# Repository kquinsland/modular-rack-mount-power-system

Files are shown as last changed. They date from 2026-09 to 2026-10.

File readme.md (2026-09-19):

# Modular Rack Power

This is a "side-quest" project on the way to building a small "mini rack" dedicated to hosting GH/A runners.

I'll do the CAD and standalone development here before integrating it into the larger project.
The goal is to have a modular system of a backplane and multiple carrier modules that can be swapped in and out to provide different power configurations as needed.
As long as the power supply can handle it, backplanes may share/daisy-chain the
input distribution needed by their carrier modules.

Hardware, firmware, and host tooling for a modular mini-rack power system.

## Boards

- `backplane`: STM32C092/CAN-FD backplane with six carrier slots, power
  distribution, aggregate current monitoring, fan control, and a status
  NeoPixel.
- `carrier`: Mates with one backplane slot and hosts an SW3538 USB-C PD module.

Every backplane and carrier is an independent STM32C092 CAN-FD node. There is no
I2C mux and no controller/proxy relationship between nodes. Earlier hardware and
firmware were research prototypes and are not compatibility targets.

## Layout

```text
firmware/
  Cargo.toml
  backplane/
  carrier/
  bootloader/
  crates/
  tools/
  xtask/
  docs/pdcan/
hardware/
  boards/
    backplane/
    carrier/
  libraries/
    symbols/
    footprints/
    3dmodels/
  mechanical/
docs/
scripts/
build/
releases/
```

`build/` is for generated local outputs. `releases/` is for fabrication packages that should be preserved exactly as sent to a board house.

See [`firmware/README.md`](firmware/README.md) for workspace commands and the
current hardware/firmware contract. Run `mise run firmware:check` from this
directory, or run Cargo commands from `firmware/`. The reviewed implementation
plan is kept in [`firmware/plan.md`](firmware/plan.md).

## Documentation site

The public-facing project documentation is maintained in [`site/`](site/) and
is intended for <https://mrps.karlquinsland.com/>. Run `mise run site:serve` for
local preview or `mise run site:build` for a production build. Create journal
entries with `mise run worklog:new -- "Concise Summary"` to create
`site/content/worklogs/YYYY/MM/DD - Concise Summary/index.md` with matching
front matter and an adjacent `_files/` directory for page resources.

## Misc

I can't believe that it's STILL such a pain in the ass to use LCSC to search for parts that are stocked by the SMT service.
https://yaqwsx.github.io/jlcparts/#/

Also super useful reference: https://www.tinkervault.com/usb-power-sources/dc-pd30-adapters
It's how I 'caught' that the `sw3538` based module I am using is non-standard 140W, later confirmed:

- https://en.eeworld.com.cn/Reference_Designs/detail/81702
- https://github.com/happyme531/h1_SW35xx/issues/13#issuecomment-4361605621

https://github.com/Shrike-Lab/HomeLab-PDU-V1/blob/main/ASSEMBLY/README.md#pcb-tray

Plan was to use APK43070 but they do not support MCU controlling it via i2c

https://meron33.hatenablog.com/entry/2026/02/07/112759

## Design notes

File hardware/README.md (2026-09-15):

# Hardware

Source hardware lives here.

- `boards/`: One KiCad project per physical PCB.
- `libraries/`: Project-local KiCad symbols, footprints, and 3D models shared by all boards.
- `mechanical/`: Enclosure, panel, mounting, and exported mechanical references.

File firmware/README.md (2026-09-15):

# Firmware

This Cargo workspace targets the finalized Generation-2 hardware. Every backplane
and carrier is an independent STM32C092GCU6 CAN-FD node. I2C is board-local; the
host addresses nodes directly for control, telemetry, commissioning, and
application firmware updates.

## Workspace

- `backplane/`: backplane hardware contract and Embassy application target.
- `carrier/`: current SW3538 carrier contract and Embassy application target.
- `bootloader/`: common Embassy Boot swap/rollback bootloader.
- `crates/pdcan-types/`: shared role, capability, policy, telemetry, and update types.
- `crates/pdcan-protocol/`: strict CAN-FD codecs and message catalog.
- `crates/pdcan-core/`: transport-independent safety, commissioning, and update state machines.
- `crates/pdcan-drivers/`: INA237, DS18B20, and SW3538 drivers plus flash records.
- `crates/pdcan-artifact/`: versioned, signed-ready application update bundles.
- `tools/pdcan/`: Clap-based SocketCAN host utility with `clap_schema` discovery.
- `tools/pdcan-sim/`: deterministic Generation-2 backplane/carrier simulator.
- `xtask/`: CI, embedded builds, size gates, bundle construction, and DBC generation.

Firmware retains manual binary codecs; **Deku is not adopted**. See
[decision 0002](../docs/decisions/0002-do-not-use-deku-in-firmware.md) for the
rationale and supporting tests. The [benchmark report](docs/pdcan/deku-benchmark.md)
preserves the completed POWER and carrier-policy trial and reproduction commands.

## Commands

Run Cargo commands from this directory:

```sh
cargo xtask ci
cargo xtask firmware build backplane --release
cargo xtask firmware build carrier --release
cargo xtask firmware build bootloader --release
cargo xtask dbc --check
cargo run --package pdcan -- --help
cargo run --package pdcan -- schema --full
cargo run --package pdcan-sim -- --help
```

Build an unsigned application bundle after converting the linked application to
the raw ACTIVE-partition image expected by Embassy Boot:

```sh
cargo xtask firmware bundle carrier 1.0.0 carrier.bin carrier-1.0.0.pdcan
cargo run --package pdcan -- firmware inspect carrier-1.0.0.pdcan
```

Only Linux builds open SocketCAN interfaces. Host tests, artifact inspection,
Clap help, and schema discovery work on macOS. Embedded binaries use
`thumbv6m-none-eabi` and the `stm32c092gc` Embassy feature.

## Safety and update contract

Carrier outputs start disabled. A persisted enable is restored only after local
hardware checks and a deterministic UID-derived startup delay. Emergency and
fault handling always override policy. Backplane fans start at the safe 100%
duty state.

The host stages an image directly to the target node over CAN, verifies its
SHA-256 digest, and activates it separately. The current SW3538 profile advertises
`interrupt`, so `pdcan firmware activate` and the convenience `update` command
require `--allow-interruption`. A future profile may advertise `live` only after
its complete activation, trial-boot, failure, and rollback sequence has passed
profile-specific hardware-in-the-loop continuity testing.

The bootloader itself is SWD-only. Initial unsigned bundles provide transfer
integrity, not sender authentication; the artifact reserves Ed25519 algorithm,
key-ID, and signature fields for later enforcement.

See [plan.md](plan.md), [the firmware architecture](docs/pdcan/firmware-architecture.md),
and [the protocol specification](docs/pdcan/protocol.md).

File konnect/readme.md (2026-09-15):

# Konnect

This repository uses [Konnect](https://github.com/mixelpixx/Konnect), a Rust MCP
server, for AI-assisted KiCad work.

Mise downloads the precompiled upstream GitHub release. The version and release
artifact checksums are pinned in `mise.toml` and `mise.lock`:

```text
version: v0.11.0
```

Konnect is currently beta software and is licensed AGPL-3.0-only.
Review Konnect's `LICENSE` and
`COMMERCIAL.md` before using it in a commercial workflow.

## Architecture

Konnect runs as one Rust binary. It uses KiCad 10's supported IPC API
for live PCB edits and direct, atomic S-expression editing for schematics.

## Setup

Install KiCad 10, then from the repository root run:

```shell
mise install
mise run konnect:verify
```

No Konnect compiler toolchain is required. Mise selects the precompiled GitHub
release for the host OS and architecture, verifies its release provenance and
checksum, and puts `konnect` on the project tool path.

Konnect v0.11.0 does not publish a standalone Linux ARM64 binary. The mise entry
therefore supports this repository's Linux x86-64 and macOS ARM64 targets and
deliberately excludes the generic Linux Plugin and Content Manager ZIP from
standalone asset matching. Other project tools remain available on Linux ARM64;
only Konnect is skipped.

Restart Codex after the build so it reloads `.codex/config.toml`. Useful checks:

```shell
codex mcp list
codex mcp get konnect
```

The project MCP entry starts mise's `konnect` binary with the repository's
`konnect/config.toml`. It uses stdio transport, binds the default project
directory to the repository root, and initially exposes Konnect's small starter
toolset. Other toolsets are loaded on demand.

## KiCad runtime setup

In KiCad 10, enable **Preferences → Plugins → Enable KiCad API**. Most live PCB
operations require the target board to be open in PCB Editor. Schematic editing
and some closed-board operations do not require KiCad to be running.

On Linux, `kicad` and `kicad-cli` normally work from `PATH`. On macOS, add the
application paths to `konnect/config.toml` if they are not already discoverable:

```toml
kicad_cli = "/Applications/KiCad/KiCad.app/Contents/MacOS/kicad-cli"
kicad_binary = "/Applications/KiCad/KiCad.app/Contents/MacOS/kicad"
ipc_address = "ipc:///tmp/kicad/api.sock"
```

The KiCad Plugin and Content Manager package is optional for this repository's
standalone MCP server. Install the matching `konnect-pcm-v0.11.0-*` release if
you also want Konnect's KiCad GUI integration or native Specctra bridge.

## Optional Codex guidance

This repository includes the six v0.11.0 Konnect skills and their references
in `.codex/skills`. The `.agents/skills` symlink points there so Codex can
discover them using its repository skill search path.

Konnect bundles KiCad skills for Codex. Installing them writes outside this
repository to `~/.agents/skills`, so it is intentionally not part of the normal
build or verification tasks:

```shell
mise run konnect:install-guidance
konnect status --client codex
```

Remove those user-level files with:

```shell
konnect uninstall --client codex
```

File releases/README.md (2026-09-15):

# Releases

Preserved board fabrication outputs go here.

Use one folder per hardware release, for example `rev-a/backplane/` and `rev-a/carrier/`.

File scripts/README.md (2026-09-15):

# Scripts

Project automation goes here, such as KiCad CLI exports for schematics, BOMs, fabrication files, and 3D models.

## PCB power-capacity reports

`pcb_power_capacity.py` reads the filled copper geometry for a KiCad net and
estimates its current capacity at selected conductor temperature rises using
the IPC-2221 relationship published by KiCad. It reports every participating
copper layer's shared geometry, a natural current-sharing aggregate, an
ideal-sharing ceiling, voltage drop, copper loss, and a separate via-barrel
screening estimate. A scenario may compare multiple named copper stackups
without duplicating the geometry views. The generated SVG provides stackup
summary cards, color-coded limiting cuts, one conservative-temperature
capacity profile per stackup, and aggregate temperature-rise proxy heatmaps.
Each heatmap locally inverts the IPC-2221 capacity relationship; it is useful
for locating relative hot regions but is not a thermal-spreading or airflow
simulation.

The host needs Python 3.11 or newer, KiCad 10 with its `pcbnew` Python
bindings, and Shapely 2.x. The same dependencies are already used by the
repository's panel-generation workflow.

Generate both checked-in scenarios under `build/power-capacity/`:

```sh
mise run power:reports
```

Generate one named scenario or list the configured scenarios:

```sh
mise run power:report backplane-vcc
mise run power:report carrier-vcc
mise run power:report --list
```

Scenarios and their source/sink currents are defined in
`pcb_power_scenarios.toml`. The backplane scenario uses six 5.5 A slot loads;
it compares 2 oz outer / 1 oz inner copper with 1 oz outer / 0.5 oz inner
copper in one report. The carrier scenario follows `VCC` from `J1.1` to the
upstream side of the current shunt at `R1.1` and uses the board's KiCad
stackup. Reports show both micrometres and nominal PCB copper weight using
34.8 µm per oz/ft². Stackup comparisons use repeated `stackups` tables in the
scenario configuration. An ad-hoc invocation—or explicit `--copper` overrides
on a named scenario—generates a single custom-stackup report:

```sh
mise run power:report -- \
  --board hardware/boards/carrier/carrier.kicad_pcb \
  --net VCC \
  --source J1.1 \
  --sink R1.1=5.5 \
  --layer F.Cu \
  --layer In1.Cu \
  --layer In2.Cu \
  --layer B.Cu \
  --copper F.Cu=35 \
  --copper In1.Cu=17.5 \
  --copper In2.Cu=17.5 \
  --copper B.Cu=35
```

Omit `--layer` to use every enabled copper layer carrying the selected net.
Add one or more `--cut X1,Y1:X2,Y2` arguments to evaluate explicit board-space
cross-sections alongside the automatic sweep. A manual cut appears in the SVG
when it is limiting; every cut remains available in the complete JSON inventory.
The automatic sweep projects the source pad's actual polygon along the load
direction and places its first sample half a scan pitch beyond the pad edge, so
the source pad itself cannot be reported as a downstream copper bottleneck.

Each report directory contains:

- `report.md`: concise human-readable results and qualifications;
- `report.svg`: shared aggregate/per-layer geometry, stackup-specific limiting
  cuts and capacity profiles, and estimated temperature-rise proxy maps; and
- `report.json`: machine-readable inputs plus every stackup's scanned cuts,
  electrical estimates, limiting results, and peak temperature-rise proxy for
  future CI checks.

The all-scenarios task also writes `index.md` and `summary.json` at the report
root. The summary includes a board SHA-256 and an explicit pass/fail boolean
for each requested temperature rise, making it suitable for later CI policy
checks without scraping Markdown.

Run the formula and real-board integration tests with:

```sh
mise run power:test
```

This is a screening calculation, not a released board rating or a coupled
electro-thermal simulation. Review the SVG, heed extrapolation warnings, and
validate connectors, components, via topology, airflow, and first-article
temperatures separately.

## PCB production exports

Generate either board's checked-in BOM, component-placement file, Gerber/drill
archive, STEP assembly, IPC-D-356 netlist, designator inventory, assembly-count report, and validation manifest with:

```sh
mise run production:carrier
mise run production:backplane
```

The task runs ERC and DRC with schematic-parity checking before publishing any
files. It requires the selected board's design inputs to be committed, verifies
that the BOM and placement references agree exactly, checks the required
four-layer CAM file set, and stages everything before publishing the complete
file set in `hardware/boards/<board>/production/<silkscreen-id>/`, for example
`hardware/boards/backplane/production/mrp.backplane-v2.1-26-09-10-abcdef1/`.
The ZIP, CSVs, IPC netlist, reports, STEP and validation manifest all go inside
that release directory. Re-exporting the same release replaces only that
directory; other releases and any legacy files in the production root remain
intact. The manifest records `release_id`. DRC warnings are retained in
`validation.json`; ERC findings, DRC errors, unconnected items, parity errors,
missing sourcing fields, or BOM/CPL disagreement stop the export and leave the
previous production directory intact.

`assembly-report.md` lists the four PCBWay quote fields per single board:
unique parts (distinct LCSC codes), SMD components, BGA/QFP-category components,
and through-hole components. It follows PCBWay's tooltip definitions: the fields
count parts, despite the site's “SMT Pads” image labels. BGA/QFP includes ICs with
more than 16 pins (including QFN/SOP) and other SMD parts with more than 10 pins;
it is a subset of SMD. Only exported BOM/CPL references count, so hand-installed
connectors/modules excluded from those files do not enter the assembly quote.
The report includes a separate SMT contact count for reference. Repeated numbered
exposed-pad segments count once. Details are also stored under
`assembly.pcbway_quote` in `validation.json`. KiCad's Python bindings (`pcbnew`)
must be available to the task's Python interpreter. This report is published
alongside the fabrication ZIP and is covered by the validation manifest hash.

STEP assemblies are published alongside the ZIP as
`mrp.<board>-v<version>-YY-MM-DD-<hash>.step`, for example
`mrp.carrier-v2.1-26-09-10-abcdef1.step`. The project family, board name,
version, source-commit date and short hash come from the same release variables
as the silkscreen; filename dates use hyphens. STEP
exports use the center of the Edge.Cuts bounding box as the XY origin, cut via
holes in the board body, and include silkscreen and solder-mask faces. All
component categories are included, including DNP and unspecified footprints,
independently of BOM/CPL exclusions. VRML references use matching STEP/IGES models
where available. Footprints without assigned models cannot contribute component
geometry; their references and the export settings/origin are recorded under
`step` in `validation.json`. KiCad's model/geometry diagnostics are preserved in
the matching `<release-name>.step.log` as well as the task output. The exact STEP
filename is recorded in `step.file`. STEP text variables match the CAM release, and model paths resolve
relative to the original board project. STEP files are hashed in the manifest;
their internal exporter timestamps are not normalized.

The bottom silkscreen's `BUILD_DATE` and `SHORT_HASH` variables are baked from
the source commit. KiCad CAM timestamps are normalized to that same commit time
so every file carries consistent source provenance. For an isolated test
export, pass another output root after `--`; the release-ID subdirectory is
still appended:

```sh
mise run production:carrier -- --output-dir /tmp/carrier-production
mise run production:backplane -- --output-dir /tmp/backplane-production
```

## PCB release pipeline

The new KiBot/KiKit pipeline is described in the
[release tooling guide](../.kibot/release/README.md).

```sh
mise run release:setup
mise run release:check
mise run docs:pcb-renders
mise run docs:pcb-iboms
mise run release:build
```

`build_pcb_release.py` snapshots a committed hardware revision and stages the
pipeline configuration. `pcb_release_worker.py` runs checks and exports in a
digest-pinned container. `panel_layout.py` owns the six-carrier/one-backplane
geometry. `convert_pcb_render.py` is the PEP 723 lossless WebP converter, and
`validate_pcb_release.py` checks assembly and archive invariants.

Renders and per-board manifests publish into each page's `_files/` directory
under `site/content/system/hardware/`. Vendor proof WebPs stay outside fabrication
upload ZIPs. Preview mode never produces fabrication packages. Release mode
requires both source boards, the panel, and vendor variants to pass their gates.

`panel:build` invokes the new release builder and publishes to
`releases/pcb-release/`. The old `build_carrier_backplane_panel.py` and
standalone production exporter remain for historical comparison; existing Rev A
exports are not regenerated by this migration.

The architecture and Mermaid diagrams are in
[pcb-release-pipeline-refactor.md](../docs/pcb-release-pipeline-refactor.md).

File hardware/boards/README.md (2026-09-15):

# Boards

Each physical PCB gets its own KiCad project directory.

Current boards:

- `backplane`
- `carrier`

Both active boards use the same STM32C092GCU6 and direct CAN-FD architecture.
The backplane and carrier directories are the only product board definitions;
earlier research layouts are not compatibility targets. Some shared library
nicknames retain their original internal name so the finalized KiCad references
remain stable.

Future boards should follow the same pattern: `hardware/boards/<board-name>/<board-name>.kicad_pro`.

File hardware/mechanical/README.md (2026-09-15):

# Mechanical

Mechanical source and exports for the system.

- `enclosure/`: Editable enclosure or mounting models.
- `panels/`: Front/rear panel source files.
- `exports/`: Shared STEP/DXF/PDF exports used for board alignment or review.

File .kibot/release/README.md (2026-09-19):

# PCB release tooling

The entry point is `scripts/build_pcb_release.py`, with file-based mise tasks.
It snapshots the selected commit, including the complete hardware library tree,
and runs KiBot/KiCad/KiKit inside the digest-pinned image defined by `IMAGE`.
Source projects in the checkout are never modified by a build.

Active projects are `hardware/boards/carrier/carrier.kicad_pro` and
`hardware/boards/backplane/backplane.kicad_pro`. The builder recognizes the
former `backplane-prototype` path in historical revisions and refuses to treat
the earlier split backplane as the consolidated board. Historical revisions
that used retired submodules need those pinned objects available locally.

```sh
mise run release:setup             # download the pinned image once
mise run release:test              # Python validation/conversion tests
mise run release:check             # both boards: ERC, parity, DRC, zone refill
mise run docs:pcb-renders          # unchecked preview + panel -> Hugo WebP bundles
mise run docs:pcb-iboms            # same, plus interactive assembly HTML
mise run release:build            # gated release -> build/pcb-release/
mise run panel:build              # gated release -> releases/pcb-release/ + Hugo
```

Pass `--ref COMMIT_OR_TAG` to select another committed source. The older
`PANEL_GIT_HASH` environment variable remains supported. Text-variable overrides
use `-D KEY=VALUE`, `--carrier-define KEY=VALUE`, or
`--backplane-define KEY=VALUE`. Board-specific overrides take precedence.
`BUILD_DATE` uses the source commit's UTC date; `SHORT_HASH` uses its first
12 hex digits. Every manifest records the full commit and effective variables.

For one board without changing site assets:

```sh
python scripts/build_pcb_release.py preview --board carrier --output build/carrier-preview
```

Preview is explicitly marked `preview-unchecked` and creates no fabrication
ZIPs. Release has no option to skip electrical checks. ERC findings, DRC errors,
unconnected items, and parity errors block it. Existing KiCad exclusions are
respected; active DRC/parity warnings are retained in validation summaries.
The mixed-panel validation policy also needs reconciliation before release use;
see the acceptance status below.

The host needs Python 3.11+, uv, and Podman. The container supplies KiBot 1.9.0,
KiCad 10.0.4, and KiKit 1.8.0-1. Builds use an offline container after setup.
Python packages for WebP are declared/pinned in `convert_pcb_render.py` using
PEP 723. No host KiCad Python installation or GUI is needed.

## Artifact boundaries

| Artifact | Destination |
| --- | --- |
| Carrier top/bottom | `site/content/system/hardware/modules/carrier/_files/carrier.webp`, `carrier-bottom.webp` |
| Backplane top/bottom | `site/content/system/hardware/backplane/_files/backplane.webp`, `backplane-bottom.webp` |
| Panel overview | `site/content/system/hardware/_files/panel.webp` |
| Render provenance | `renders.json` in each owning page's `_files/` directory |
| Optional interactive BOM | `site/static/guides/assembly/_files/carrier-ibom.html` / `backplane-ibom.html` |
| Manufacturing files | `<output>/<vendor>/upload/` and `<vendor>-upload.zip` |
| Vendor proof images | `<output>/<vendor>/proofs/<vendor>-{top,bottom}.webp` |
| Review metadata | `<output>/manifest.json`, `panel-info.json`, `checks/`, vendor order notes/netlist |
| Temporary source copies, PNGs and diagnostic logs | `build/pcb-release-work/<revision>-<unique>/` |

Upload ZIPs contain only `gerbers.zip`, `BOM.csv`, and `positions.csv`.
The Gerber archive has an explicit 13-file allowlist: four copper layers,
two masks, two silkscreens, two paste layers, the outline, and separate
PTH/NPTH Excellon drills. Proofs and order notes remain outside both archives.
The shared CPL uses millimetres and KiCad's Cartesian Y convention; negative
Y below the auxiliary origin is intentional. Rotation is normalized to 0–360°.
No automatic vendor-specific rotation correction is applied.

KiBot's manufacturer templates supply the CAM settings. Local overrides retain
both paste layers, use a shared origin, use metric drills, and explicitly
enable solder-mask subtraction for both vendors. PCBWay's upstream default has
mask subtraction disabled, so this override is deliberate.

## Vendor artwork setup

Create each conditional silk item as a board-only, padless footprint. Set these
custom footprint fields through the normal KiCad/Konnect editing workflow:

| Content | `ReleaseVendor` | `ReleaseArtwork` |
| --- | --- | --- |
| 8 × 8 mm JLC barcode target | `jlcpcb` | `barcode` |
| Literal `WayWayWay` job marker | `pcbway` | `job-number` |
| PCBWay logo | `pcbway` | `logo` |

Use a real unique reference, omit the footprint from BOM/positions, and keep
all artwork graphics on F.SilkS/B.SilkS. Pads, copper graphics, and 3D models
are rejected. The release requires the corresponding artwork roles for each
vendor; it fails closed if they have not been registered. The existing loose
barcode square must be moved into a tagged footprint, and the PCBWay marker
and logo still need to be supplied/placed before that gate can pass.

The container worker filters these board-only footprints on disposable panel
copies before KiBot exports. This small custom step handles graphics that
have no schematic component; ordinary BOM filters alone do not remove such
graphics reliably. It never guesses artwork from coordinates or deletes
untagged graphics. Both output variants receive another DRC check.

Proofs are PcbDraw views of the exact filtered PCB used for each export. They
verify artwork selection and placement; they are not a Gerber CAM simulation
of the fabricator's ink-clipping process. Inspect the actual plotted silkscreen
in GerbView as part of final manufacturing review.

## Publication and reproducibility

Checks and both vendor branches finish before publication. An existing output
directory must contain this tool's manifest to be replaced. Directory updates
use rename with rollback. Hugo publication replaces only known generated
files, preserves bundle content, and rolls back on an I/O failure. Publication
is serialized within this worktree; it is not a crash-atomic transaction across
separate filesystem paths.

CAM timestamps, ZIP ordering, file modes and ZIP timestamps are normalized.
The panel generator seeds KiCad's UUID generator from the commit. WebP encoding
is lossless and deterministic for the same input pixels. KiCad's ray-traced
images can differ slightly between runs: full release manifests, which include
image hashes, are therefore not promised byte-identical. They retain exact
source and tooling hashes for traceability.

## Acceptance status

Verified locally: both board previews, the mixed-panel preview, Hugo publication,
interactive BOMs, both boards' KiBot/native-KiCad BOM and LCSC agreement, both
vendors' standalone backplane CAM exports, proof rendering, twenty-one unit tests,
and Mermaid diagram rendering.

Panel compatibility fixes preserve explicit component-class reference lists
for each board instance, namespace `A.Reference`/`B.Reference` comparisons in
inherited rules, and bake only visible reference fields on their original
layers. Hidden fields must not become visible panel silkscreen. Component-class
filters other than explicit reference lists fail closed until supported; this
is not a general evaluator for all KiCad rule expressions or rule-area names.

The carrier source currently retains 27 `Under_PD_Module` members. Git history
shows the assignment list cleared in `b4fcf69`, `67bfaca`, and `8def932`, then
restored most recently in `361c928`. The commits record project saves but cannot
identify the process responsible; an editor saving stale in-memory settings is
a plausible explanation. The current panel problem was separate: KiKit did not
copy these top-level project assignments or rename the rule's `MOD1` reference.
The generated panel now has six assignments with 162 namespaced members; its
under-module overlaps and reference-specific courtyard exceptions pass DRC.

Full mixed-panel release acceptance is **not complete**:

- Carrier D1 now uses `mini-rack-power:D_SMC_Silk0.15mm` in both the schematic
  and PCB, retaining its pad geometry and fitted status. Native carrier checks
  after replacement report zero ERC/DRC errors and zero unconnected items;
  28 existing DRC warnings remain, with no D1 library-mismatch warning.
  The diagnostic counts below use an older source revision, not this PCB fix;
  repeat the mixed-panel check using the updated committed source.
- A diagnostic using source checkpoint `f12cc7b` and the compatibility fixes
  plus the mouse-bite policy below reports 215 panel errors: 126 repeated D1
  line-width assertions, 31 mouse-bite/courtyard findings,
  48 narrow GND connections, six visible carrier LED1 text-height findings,
  and four unconnected items. Under-module and reference-specific courtyard
  exceptions now work. These are generated-panel integration findings, not
  evidence of 215 errors in either source PCB. Reconcile the remaining policy
  and repeat the full checked-source/refill/panel sequence before accepting
  CAM equivalence. Do not blanket-ignore the findings.
- The 0.45 mm pad-hole spacing rule originates in `d28e3ec` and was copied to
  the carrier in `bedac27`. It also matches NPTH mouse bites, whose current
  0.6 mm holes have 0.4 mm edge-to-edge spacing. JLCPCB documents separate
  [mouse-bite guidance](https://jlcpcb.com/blog/pcb-design-efficiency-mouse-bites)
  from its general [pad-hole spacing limit](https://jlcpcb.com/capabilities/pcb-capabilities).
  The generated panel now appends a 0.30 mm hole-to-hole rule matching only
  **pairs of generated NPTH mouse bites** (`KiKit_MB_*`), eliminating all 108
  false generic pad-hole spacing findings in this diagnostic. Ordinary holes,
  tooling holes, mixed mouse-bite/ordinary-hole pairs, copper clearances, and
  component courtyards retain their existing checks. No source rule is changed.
  The generator validates actual 0.6 mm round unconnected NPTHs, 5–8 per set,
  0.30–0.40 mm edge gaps, and the expected 27 sets/135 holes. Metadata records
  the measured 1.0 mm pitch and 0.4 mm gap separately from KiKit's requested
  0.95 mm pitch. The capabilities table recommends 0.2–0.3 mm gaps while the
  more detailed mouse-bite guide recommends 0.35–0.4 mm (minimum 0.3 mm);
  this policy explicitly follows the latter. Confirm the panel with JLCPCB's
  engineering review when ordering rather than treating DRC as vendor approval.
- The panel inherits the backplane's 0.20 mm minimum copper connection width.
  The carrier leaves this check disabled (minimum 0.0 mm). Its In1/In2 GND
  zones contain 0.1651–0.1871 mm necks: widths of copper bridges, not copper
  thickness or clearances. Check the affected ground-current paths before
  widening the geometry or adopting a narrowly scoped alternate policy.
  Recommended next step: enable the same 0.20 mm connection check on the
  carrier, then address the eight findings per carrier (four on each inner
  layer) in the source layout. These zones already use solid pad connections
  and 0.25 mm minimum fill thickness, so this is not a thermal-spoke setting
  to turn up. Adjust nearby obstacles/connection geometry or remove unnecessary
  copper tongues only after checking alternate ground paths. Refill and verify
  connectivity before rebuilding. The common 0.20 mm policy is a design margin,
  not a claim that JLCPCB cannot fabricate any narrower copper.
- Vendor artwork still needs placement/registration as described above.
- Run both complete mixed-panel vendor branches and compare their CAM/assembly
  geometry once those gates pass. No fabrication-ready mixed-panel package has
  been produced by this implementation yet.

The old standalone production exporter and panel script remain available for
comparison while the migration is validated. The public `panel:build`,
`docs:pcb-renders`, and `docs:pcb-iboms` tasks use the new implementation.
The old Rev A production package remains a historical artifact.

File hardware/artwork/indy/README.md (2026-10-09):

# Indy silkscreen artwork

Faithful vector traces of the supplied dot-free artwork. No generative redraw,
line thickening, or removal of small details is applied. The selected source is
`indy04.png` (Image #3 in the supplied comparison); `indy02.png` (Image #1) is
provided as an alternative. Source PNGs are at the repository root.

## Files

- `indy04-silkscreen-75mm.svg`: preferred artwork, nominally 60.266 × 75 mm.
- `indy02-silkscreen-75mm.svg`: alternative, nominally 61.793 × 75 mm.
- `indy-size-proof.pdf`: A4 comparison of the preferred artwork at 50, 75, and
  100 mm tall. Print at **Actual Size / 100%**, without fitting to the page.
  Check the 50 mm calibration bar with a ruler.
- `indy-size-proof.svg` and `.png`: comparison sources and screen preview.
- `trace.py`: repeatable conversion and rendering; run with `uv run
  hardware/artwork/indy/trace.py` from the repository root.

## Import into KiCad

In PCB Editor, use **File → Import → Graphics**, select a `silkscreen` SVG,
choose **F.SilkS**, and enable **Group imported items**. Import scale 1 gives
75 mm height; use 0.666667 for 50 mm or 1.333333 for 100 mm. For back-side
artwork, check orientation as viewed from the back of the board.

Black SVG paths mean **silkscreen ink**; the board's fabrication ink color
determines their printed color. The background and internal openings are
transparent, with no background rectangle. Do not import the comparison sheet:
its colored rectangles and labels are only for viewing.

[KiCad's vector import documentation](https://docs.kicad.org/10.0/en/pcbnew/pcbnew.html#_importing_vector_graphics)
describes scale, layer, and grouping settings.

## Size and print fidelity

For preserving detail, prefer **100 mm tall** if space permits; **75 mm** is a
reasonable compromise. At **50 mm**, expect fine whiskers and facial details to
drop out. These are estimates, not a guaranteed manufacturing minimum.

The preferred source's cropped artwork is 998 × 1242 pixels. Sampled whisker
cross-sections include 2–4 pixel widths, equivalent to 0.081–0.161 mm at 50 mm
height, 0.121–0.242 mm at 75 mm, and 0.161–0.322 mm at 100 mm. These samples are
not an exhaustive minimum-width measurement; oblique cross-sections can also
overestimate perpendicular stroke width. Fur tips taper toward zero width at
every size. Larger printing preserves more detail but cannot preserve every
tip exactly.

[JLCPCB's published legend capability](https://jlcpcb.com/capabilities/pcb-)
lists a 0.15 mm minimum line width and 0.15 mm pad-to-silkscreen spacing.
Confirm the actual fabricator's requirements before production. The comparison
sheet shows ideal geometry, not a simulation of ink spreading or lost details.

The SVGs contain closed filled polygons with even-odd holes. The tracing script
classifies white source pixels, follows their boundaries with a 0.25 source-pixel
polygon approximation tolerance, and checks rendered mask overlap. Both traces
exceeded 99.99% intersection-over-union at source resolution. This checks visual
conversion fidelity, not manufacturability. No board placement, KiCad import
verification, or board DRC has been performed.

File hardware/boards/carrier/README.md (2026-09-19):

# Carrier PCB

KiCad project for one mini-rack power carrier board.

Responsibilities:

- Mate with one backplane slot.
- Host one fixed-address DC/USB-C PD module.
- Convert the slot-local DC and CAN-FD interface into the module-local wiring.
- Keep carrier-side interfaces reusable across all backplane slots.

Assembly notes:

- `J1` and `MOD1` are intentionally DNP/excluded from the PCB assembly BOM. The
  user installs and solders the right-angle XT30PW(2+2) connector and SW3538
  module after assembly.
- The housekeeping converter shares the backplane's LM5164DDAR regulator and
  PSPMAA0805-101M-ANP 100 µH inductor.
- L1 is placed and routed. The checked-in assembly and fabrication outputs are
  generated and validated with `mise run production:carrier`.

Relevant docs:

- `../../../docs/system-overview.md`
- `../../../docs/interfaces.md`
- `../../../docs/power-budget.md`
- `hardware-handoff.md`

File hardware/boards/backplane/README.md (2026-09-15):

# Consolidated backplane

This directory contains the finalized Generation-2 backplane:
`backplane.kicad_pro`, `backplane.kicad_sch`, `backplane.kicad_pcb`, and
`backplane.kicad_dru`.

The PCB in this directory is the mechanical authority for the board
outline, airflow cutouts, mounting holes, and six slot-connector footprints and
placement. The carrier is the electrical authority for circuitry shared between
the two boards, including the slot pinout, STM32, CAN transceiver, current
sensor, and slot connector pinout.

## Implemented schematic

The root schematic is divided into five sheets:

- `01_power_input.kicad_sch`: DC input, 1 mOhm high-side current shunt,
  INA237 monitor;
- `02_control.kicad_sch`: STM32C092GCU6, reset/decoupling, SWD, and test points;
- `03_can_slots.kicad_sch`: TCAN3413 CAN-FD interface, external CAN protection,
  optional termination, and the six carrier slots;
- `04_fan_status.kicad_sch`: two independent 3-wire fan supply-PWM switches and
  tachometer inputs, plus an externally powered DS18B20 interface. Per-slot
  addressable LEDs were removed to keep automated assembly on one side of the
  PCB; and
- `05_buck_converters.kicad_sch`: separate LM5164 3.3 V and 12 V converters.

The Rust `backplane-firmware` target implements this board. Earlier firmware
targets and their hardware assumptions are not supported.

Both regulators use LM5164DDAR, LCSC C477928, with
PSPMAA0805-101M-ANP 100 uH inductors, LCSC C2962892. The output-specific
feedback, on-time, ripple-injection, and capacitor networks remain separate.

The PCB stackup specifies 2 oz outer copper, 1 oz inner copper, and an ENIG
surface finish.

Generate the backplane BOM, placement file, Gerber/drill archive, IPC-D-356
netlist, designator inventory, and validation manifest with
`mise run production:backplane`. A successful export records warnings in the
manifest; it does not by itself supersede the fabrication-readiness status
below.

The local I2C2 bus uses STM32 PA6/PA7 and exists only between the STM32 and
INA237. Carrier communication is CAN-FD.

## Connectors

`J8` is the main DC input:

1. GND
2. VIN_RAW

`J7` is a XINLAIYA XY308-2.54-3P three-position screw terminal, LCSC
`C557686`:

1. GND
2. CANL
3. CANH

`J7` is intentionally marked DNP and excluded from pick-and-place output because
the user installs it by hand after assembly. D1 and L3 protect only this external
CAN boundary. Each carrier has its own connector-side CAN protection, so the
backplane does not duplicate ESD parts at every slot. `SJ1` and `R17` provide
normally-open 120 ohm termination for use only when this backplane is at a
physical bus end.

`J8` is likewise marked DNP and excluded from pick-and-place output for hand
installation after assembly.

The six carrier slots retain the authoritative combined XT30 plus two-signal
footprint. Their physical pinout is:

1. VIN_BUS — power contact furthest from the two low-voltage signal contacts
2. GND — power contact between pin 1 and the two low-voltage signal contacts
3. CANH
4. CANL

The slot references are `J1` through `J6`, from slot 1 through slot 6. `J9` and
`J11` are independently controlled 3-wire fan connections: GND, switched 12 V,
and tach.

CAN differential nets use KiCad's `_P`/`_N` naming convention on both sides of
the common-mode choke: `CAN_BUS_P`/`CAN_BUS_N` and
`CAN_EXT_P`/`CAN_EXT_N`, with `P = CANH` and `N = CANL`. Custom DRC rules
enforce a 0.20-0.30 mm gap on coupled routes and a 35 mm maximum uncoupled
length. Narrowly scoped breakout areas permit up to 2.40 mm pair spacing at
connector, choke, and transceiver fan-outs. Whole-net skew is intentionally not
constrained because the six-drop `CAN_BUS` trunk is branched; aggregate P/N net
lengths do not describe a meaningful point-to-point signal path.

`J12` is the externally powered DS18B20 header:

1. GND
2. DQ (`DS18B20_DATA`, pulled up to 3.3 V through `R24`)
3. +3V3

The DS18B20 data signal uses STM32 `PA15`. The local status NeoPixel uses `PA1`
through a 100 ohm series resistor and has a dedicated 100 nF bypass capacitor.
Fan 0 uses `PA2` for supply PWM and `PB8` for tach capture. Fan 1 uses `PA0` for
supply PWM and `PA8` for tach capture.

## Power assumptions

The backplane is designed for a **24–48 V nominal system**, compatible with
24 V and future 48 V carrier generations. The current SW3538 carrier is the
limiting factor: **24 V nominal, 30 V maximum input**. A second-generation
carrier with a suitably rated module and protection is required for 48 V use.
Slot feeds are unswitched and do not provide voltage conversion; never connect
a 48 V supply while any current-generation carrier is fitted. No nominal
backplane voltage below 24 V is specified. Supply tolerance, harness drop,
startup, fault protection, and thermal performance remain qualification items.

The first population targets a nominal 24 V input and up to 100 W output per
slot. Six fully loaded slots produce a working input budget of approximately
30 A. `RSH1` is 1 mOhm, giving 30 mV and 0.9 W at 30 A; configure the INA237 for
its narrow shunt range and route the sense pair as true Kelvin connections.

The later design goal is 48 V nominal with a new carrier revision and up to
240 W per slot.
That is a future characterization target, not a released rating, until the
input-protection, current-path, thermal, transient, and first-article tests are
complete.

Both fan channels share the LM5164 12 V rail. Its combined continuous,
startup, and stall load must be tested with the intended pair of fans; adding a
second connector does not increase the regulator's 1 A output rating.

## PCB status

The schematic is synchronized into a fully placed and routed PCB. The finalized
design passes ERC and PCB DRC. Its operating limits remain conditional on the
first-article validation below.

Before ordering and assigning a production current rating:

- verify the mirrored `J1`-`J6` mating geometry, power polarity, and CANH/CANL
  ordering against a carrier;
- confirm the hand-installed `J7`, `J8`, `J9`, `J11`, and `J12` footprints and
  entry directions against the sourced parts;
- review the generated BOM, placement, Gerber, drill, and validation files; and
- perform first-article high-current, thermal, fan startup/stall, CAN-FD, and
  protection testing under the intended enclosure and airflow conditions.

See `../../../docs/interfaces.md`, `../../../docs/system-overview.md`, and
`../../../docs/power-budget.md` for the system-level definitions.

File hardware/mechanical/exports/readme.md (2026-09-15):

# Misc 3d models

Mostly for PCB footprints.

The XT30s came from grabcad:

- [XT30(2+2)PW-M](https://grabcad.com/library/xt30-2-2-pw-m-3)

- [XT30(2+2) F](https://grabcad.com/library/amass-xt30-2-2-f-1)

The `F` variant is not the same as the `U` variant which is what I actually need but it's good enough to start with.
I will have to order a U variant and make a proper 3d model for it later.

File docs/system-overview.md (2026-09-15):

# System Overview

The second-generation design combines the controller, six-slot power
distribution, current monitoring, dual-fan control, and external temperature
sensor interface on one backplane. Each carrier has its own STM32 and CAN-FD
transceiver; there is no backplane-to-carrier I2C bus.

```mermaid
flowchart LR
    supply["24-48 V nominal system; 24 V with current carriers"] --> input[J8 DC input]
    input --> shunt[1 mOhm shunt]
    shunt --> bus[VIN_BUS high-current distribution]
    bus --> slots[Six carrier slots]
    bus --> buck3[LM5164 3.3 V]
    bus --> buck12[LM5164 12 V]

    canext[J7 GND / CANL / CANH] <--> protection[ESD + common-mode choke]
    protection <--> canbus[Shared CAN-FD trunk]
    canbus <--> phy[Backplane TCAN3413]
    canbus <--> slots

    buck3 --> mcu[Backplane STM32C092]
    buck3 --> monitor[INA237]
    buck3 --> phy
    shunt --> monitor
    mcu <--> monitor
    buck3 --> temp[DS18B20 external-supply header]
    mcu <--> temp
    buck12 --> fans[Two 3-wire fan high-side switches]
    mcu --> fans
```

## Electrical Authority

Where the boards overlap, the carrier is authoritative. The backplane therefore
uses the carrier's STM32C092GCU6, TCAN3413DR, INA237AIDGSR, CAN choke and ESD
parts, and slot connector/pinout.

The finalized backplane PCB is authoritative for the board outline, airflow
cutouts, mounting features, and the six slot-connector footprints and
placement. Its consolidated circuitry is synchronized, placed, and routed.
Electrical ratings still depend on first-article validation.

## Communications

CAN-FD is the only communication interface between the backplane and carriers.
One protected three-position screw-terminal connection joins the external bus.
Optional 120 ohm termination is fitted but normally open. The backplane does not
duplicate ESD arrays at each carrier slot because every carrier retains its own
connector-side protection.

I2C is strictly local to the backplane STM32 and its INA237 current sensor.

## Power Targets

The backplane is designed for a **24–48 V nominal system**. The current SW3538
carrier limits the first revision to **24 V nominal, 30 V maximum input**;
48 V operation requires a second-generation carrier with a suitably rated
module and protection. All slots receive the same unswitched bus voltage, so
do not mix current carriers onto a 48 V-powered backplane. No nominal input
below 24 V is specified; supply-tolerance and startup margins still require
qualification at the carrier connector.

The first population targets a nominal 24 V input and no more than 100 W output
per slot, or approximately 30 A total backplane input current for six loaded
slots. The board measures aggregate input current rather than switching or
limiting individual slots.

The longer-term hardware goal is 48 V nominal input with a new carrier revision
for up to 240 W per slot. That goal is not a released rating until the raw-input
protection, shunt/current path, connector and copper temperatures, transients,
regulators, carrier hot-swap path, and full-system first-article behavior have
been validated.

## Cooling and Temperature

A dedicated LM5164 generates 12 V for two independently switched 3-wire fan
connectors. The STM32 controls each high-side PMOS and reads both tach outputs.
The two channels share the regulator's 1 A output capability, so simultaneous
startup and stall loading must be validated with the selected fans.

An externally powered DS18B20 can be connected at J12 for remote air, heatsink,
or chassis-temperature measurement. The STM32 also contains an ADC-connected
internal die-temperature sensor, but that is not a substitute for a remotely
placed sensor. The backplane has one local status NeoPixel on PA1; there are no
per-slot NeoPixels.

Firmware uses the same STM32 target and bootloader on every board, with separate
backplane and carrier applications. The host commissions and controls nodes and
performs direct CAN firmware updates; a backplane never updates a carrier.

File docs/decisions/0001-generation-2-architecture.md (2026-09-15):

# 0001: Generation-2 Direct CAN Node Architecture

## Decision

The product consists of backplanes and carriers connected to shared power and
CAN-FD trunks. Every board uses an STM32C092GCU6 and TCAN3413 and is an
independently commissioned PDCAN node.

A backplane distributes an unswitched input bus to six carrier connectors and
owns aggregate input monitoring, two fans, an external temperature sensor, and
one status NeoPixel. A carrier owns its power-output safety, local monitoring,
status NeoPixel, and profile-specific controller. Local I2C buses do not cross
board boundaries; there is no I2C mux.

The host addresses every node directly for discovery, configuration, telemetry,
and Embassy Boot application updates over CAN. A backplane does not proxy or
perform a carrier update. Each carrier profile declares whether firmware
activation is live or interrupts its service.

## Rationale

Direct CAN addressing matches the physical bus, removes fixed-address I2C
isolation and controller dependencies, allows multiple backplanes to share a
power supply, and permits carrier types to evolve without changing backplane
firmware. A common MCU and bootloader keep build, commissioning, recovery, and
update behavior consistent across roles.

## Consequences

- Operational identity is a persistent Node ID associated with the STM32 UID,
  not a backplane/port address.
- Optional backplane UID and slot binding is descriptive inventory metadata.
- Carrier behavior is capability/profile-driven. The initial SW3538 carrier is
  an interrupt-update profile; basic and future 240 W profiles may differ.
- Each node must enter its own safe state on boot, emergency, communication
  loss, invalid configuration, and failed update.
- Firmware bundles are target-specific and staged into a per-node DFU partition.
  Activation uses Embassy Boot trial/confirmation/rollback behavior.
- Previous research/prototype protocols, firmware targets, and hardware
  topologies are not compatibility requirements.

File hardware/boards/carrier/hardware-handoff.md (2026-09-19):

# USB-C PD Carrier PCB Hardware Handoff

**Status:** Carrier Rev A implementation notes. The checked-in schematic now
uses the common backplane `LM5164DDAR` and `PSPMAA0805-101M-ANP` buck pair. The
PCB now has both parts placed and routed, and its production outputs are
generated with `mise run production:carrier`.

**Revision:** Rev A architectural handoff

**Design intent:** Per-module USB-C PD carrier for a 24–48 V nominal backplane
system. This SW3538 population is limited to **24 V nominal, 30 V maximum
input**; a second-generation carrier is required for 48 V operation. It provides
protected power switching, current/power telemetry, CAN-FD, local I²C control, and a local 3.3 V
housekeeping supply. The first population is product-limited to 100 W while
the component choices support investigation toward a future 240 W EPR system.

---

## 1. Scope

This carrier PCB is intended to sit between a shared high-current DC distribution bus and one USB-C Power Delivery module.

The carrier shall:

- Accept **24 VDC nominally, 30 VDC maximum** in this revision; **48 VDC nominal** requires a new carrier revision and suitably rated module/protection.
- Supply a local **3.3 V housekeeping rail** for:
  - STM32 MCU
  - INA237 power monitor
  - WS2812B-2020-V6 RGB status LED
  - I²C pull-ups and miscellaneous logic
- Switch the high-current input rail to the USB-C PD module under MCU control.
- Protect the PD branch against:
  - excessive startup/inrush current
  - downstream short circuits
  - overloads
  - excessive pass-MOSFET dissipation during startup/faults
  - undervoltage / overvoltage
- Measure PD-module input:
  - bus voltage
  - current
  - power
- Provide:
  - one backplane CAN-FD interface
  - one local/downstream I²C bus, with the STM32 acting as controller/master
- Control a single WS2812-compatible RGB status LED.
- Default the PD-module power path to **OFF** whenever the MCU is unpowered, resetting, or not explicitly enabling the branch.

This is a **high-level electrical handoff**, not a production-release schematic. The KiCad engineer should validate component footprints, pin numbering, manufacturer land patterns, thermal design, switching-regulator layout, and protection margins before release.

The present work scope is hardware, schematic, PCB, and physical validation only. Firmware references below define the hardware interface and expected future ownership; firmware implementation is deferred.

The only electrical interface between the backplane and carrier is:

- unswitched DC input
- ground
- backplane CANL
- backplane CANH

The backplane does not supply a carrier logic rail. Each carrier generates its own 3.3 V housekeeping rail from the unswitched DC input.

---

## 2. Measured PD-module characteristics

The following measurements were made on the actual PD module and should be treated as design inputs:

| Parameter | Measured value |
|---|---:|
| Effective input capacitance while powered off | **~300 µF** |
| SDA to GND resistance while powered off | **~15 MΩ** |
| SCL to GND resistance while powered off | **~15 MΩ** |

The approximately 15 MΩ powered-off I²C resistance is encouraging and suggests that the PD module presents a high-impedance load to the I²C bus when unpowered.

No I²C bus-isolation IC is included in this design.

During bring-up, verify the powered-off behavior explicitly:

1. Leave the PD module unpowered.
2. Pull SDA and SCL to 3.3 V through approximately 10 kΩ.
3. Verify both lines rise close to 3.3 V.
4. Verify the pull-ups do not measurably back-power the PD module.
5. Verify the module does not clamp or distort either I²C line.

---

## 3. System assumptions

### 3.1 Product-generation power targets

Keep these three ratings distinct:

| Generation / constraint | Power target | Hardware interpretation |
|---|---:|---|
| First production population | **100 W maximum** | Nominal 24 V input; MOD1 supplies at most 20 V / 5 A under the selected configuration and system policy. |
| Rev-A carrier sizing case | **140 W capable** | Size the carrier power path, current limit, connector contacts, copper, and thermal design for this 24 V high-current case. |
| Prototype program target | **240 W USB-C EPR, 48 V / 5 A** | Requires a second-generation carrier, a suitably rated module/protection, and first-article characterization plus a fresh system/module review. Not supported by the populated Rev-A SW3538 carrier. |

The 140 W architecture case is the electrical sizing corner for this carrier.
Rev A is also a prototype vehicle for learning toward the 240 W target; that
goal does not change the first production run's 24 V / 100 W operating limit.

At the low-voltage operating corner, assuming approximately 90% converter efficiency:

\[
I_{PD-IN} \approx \frac{140W}{24V \times 0.90} \approx 6.48A
\]

The carrier high-current path shall therefore be designed for at least:

- **6.5 A continuous**
- approximately **11 A short-duration fault/current-limit current**
- appropriate margin in connector contacts, copper, vias, shunt, and MOSFET

### 3.2 Sequential startup

An external controller will enable modules **sequentially**, not simultaneously.

This substantially reduces aggregate bus inrush, but each carrier still retains a dedicated hot-swap controller because it also provides:

- per-branch hardware current limiting
- short-circuit protection
- controlled startup
- MOSFET SOA/power limiting
- UVLO/OVLO
- power-good indication
- autonomous hardware fault handling

### 3.3 48 V interpretation

The backplane is intended for a **24–48 V nominal system**, compatible with
both carrier generations. The populated Rev-A SW3538 carrier limits the first
revision to **24 V nominal and 30 V maximum input**. All slots share the raw
bus voltage; do not fit this carrier to a backplane powered from 48 V.

A **second-generation carrier** with a suitably rated module and coordinated
protection is required for 48 V input. The eventual 240 W USB-C EPR goal is
separate from the nominal backplane voltage and still needs full qualification.
Characterization cannot make the present SW3538 population 48 V-compatible.

Rev-A D1 has a 48 V stand-off rating and OVLO is approximately 56.4 V nominal;
neither enforces the 30 V operating limit nor protects the SW3538's 36 V
recommended input maximum. Enforce the current population's voltage limit at
the source. The 48 V/50 V calculations elsewhere in this handoff are component
stress/future-design studies, not permission to power this populated carrier at
those voltages. Supply tolerance and transients are not additional nominal
system ratings.

For a future 48 V carrier, define supply tolerance and transients and revisit:

- TVS selection
- INA237 85 V bus/common-mode limit
- UVLO/OVLO values
- MOSFET voltage rating
- all high-voltage capacitors

---

# 4. Functional architecture

```text
                         Rev A: 24 V nominal / 30 V maximum
                                         │
                                  J1 DC + CAN-FD
                                         │
                               ┌─────────┴─────────┐
                               │      DTVS1        │
                               │     SMCJ48A       │
                               └─────────┬─────────┘
                                         │
                                       VCC
                                         │
                    ┌────────────────────┴─────────────────────┐
                    │                                          │
                    │                                          │
             HOUSEKEEPING POWER                         PD POWER BRANCH
                    │                                          │
             ┌──────▼──────┐                                   │
             │ U2 LM5164   │                                   │
             │ 100 V buck  │                                   │
             └──────┬──────┘                                   │
                    │ +3V3                                      │
       ┌────────────┼───────────────┐                           │
       │            │               │                           │
       ▼            ▼               ▼                           ▼
   U1 STM32      U4 INA237       LED1 WS2812                RSH1 6mΩ
       │                            │                           │
       │                            │                       HS_SENSE
       │                            │                           │
       │                     ┌──────┴─────┐               ┌─────▼──────┐
       │                     │            │               │ U3 LMX5069│
       │                     │            │               │ hot-swap  │
       │                     │            │               └─────┬──────┘
       │                     │            │                     │ GATE
       │                     │            │               ┌─────▼──────┐
       │                     │            │               │ Q1 100 V  │
       │                     │            │               │ Linear FET│
       │                     │            │               └─────┬──────┘
       │                     │            │                     │
       │                     │            │                 PD_VIN_SW
       │                     │            │                     │
       │                     │            │                     ▼
       │                     │            └──────────────► J3 PD MODULE
       │                     │                                  │
       │                     └──── I2C1 ────────────────────────┤
       │                                                        │
       └──── FDCAN ──► U5 TCAN3413 ──► J1 BACKPLANE CAN-FD     │
```

The housekeeping branch connects to `VCC` **before** the PD current shunt. Therefore the INA237 reports the PD-module branch power rather than including the STM32/LED housekeeping power.

---

# 5. Major component BOM

## 5.1 Design-critical active components

| Ref | Qty | Manufacturer / Part | LCSC | Package | Function |
|---|---:|---|---|---|---|
| U1 | 1 | **ST STM32C092GCU6** | **C44847705** | UFQFPN-28, 4 × 4 mm | MCU with FDCAN |
| U2 | 1 | **TI LM5164DDAR** | **C477928** | SO PowerPAD-8 | 6–100 V, 1 A synchronous buck |
| U3 | 1 | **Wuxi Maxinmicro LMX5069MS** | **C47967145** | MSOP-10 | Hot-swap / inrush controller |
| U4 | 1 | **TI INA237AIDGSR** | **C2864837** | VSSOP-10 | I²C voltage/current/power monitor |
| U5 | 1 | **TI TCAN3413DR** | — | SOIC-8 | 3.3 V CAN-FD transceiver |
| Q1 | 1 | **Infineon IPB020N10N5LF** | **C536484** | TO-263 / D²PAK | 100 V linear-mode high-side pass MOSFET |
| Q2 | 1 | **2N7002** | **C8545** | SOT-23 | Fail-safe UVLO clamp |
| Q3 | 1 | **2N7002** | **C8545** | SOT-23 | MCU enable inversion / fail-safe control |
| RSH1 | 1 | **Milliohm HoLLR2512-3W-6mR-1%** | **C2985709** | 2512 | 6 mΩ shared current shunt |
| DTVS1 | 1 | **Hongjiacheng SMCJ48A** | **C19077611** | SMC | Input TVS |
| D2 | 1 | **Nexperia PESD2CANFD27V-TR** | — | SOT-23 | CAN-FD bus ESD protection |
| L1 | 1 | **PROD Tech PSPMAA0805-101M-ANP** | **C2962892** | 8 × 8.5 mm | 100 µH buck inductor |
| L3 | 1 | **TDK ACT1210D-101-2P-TL00** | **C3039743** | ACT1210 | CAN common-mode choke |
| LED1 | 1 | **Worldsemi WS2812B-2020-V6** | **C52917434** | 2020 | RGB status LED |

### Q1 sourcing note

`IPB020N10N5LF` is selected because the pass transistor in a hot-swap circuit must tolerate significant **linear-mode/SOA stress** during startup and fault limiting.

Do **not** replace Q1 based only on:

- lower RDS(on)
- higher pulsed current
- cheaper unit price
- same VDS rating

Any substitute must have a manufacturer-specified DC/pulsed linear-mode SOA that survives the programmed LMX5069 power-limit behavior at the 48 V corner.

Q1 is currently expected to be one of the more expensive and sourcing-sensitive parts in the design, so it should be treated as a procurement-review item before production.

## 5.2 Historical comparison with the backplane-prototype switch

The earlier `backplane-prototype` revision used the following discrete per-slot
switch (this is not the current consolidated `hardware/boards/backplane`):

- Vishay `SQD50P06-15L_GE3`, 60 V P-channel MOSFET in TO-252/DPAK
- BSS123 N-channel MOSFET to pull the P-MOS gate down
- 1 kΩ BSS123 gate-series resistor
- 10 kΩ BSS123 gate pull-down
- 10 kΩ P-MOS gate pull-down/current-limiting resistor
- 100 kΩ P-MOS source-to-gate pull-up for default OFF
- BZT52C12 source-to-gate zener clamp

That circuit is a reasonable compact on/off switch for the prototype voltage/current scope, but it shall **not** be copied onto this carrier.

| Attribute | Backplane prototype | Carrier Rev A | Decision |
|---|---|---|---|
| Pass device | SQD50P06 P-channel, 60 V, 15.5 mΩ max at 25 °C | IPB020N10N5LF N-channel Linear FET, 100 V, 2.0 mΩ max at 25 °C | Use the carrier selection. The prototype FET has inadequate transient margin for a 48 V bus and SMCJ48A clamp. |
| Gate drive | Discrete BSS123 pull-down with passive default-off network and 12 V zener clamp | LMX5069 high-side charge pump plus Q2/Q3 fail-safe UVLO control | Use LMX5069; a high-side N-FET requires gate drive above its source. |
| Inrush | Determined primarily by wiring, MOSFET, and load | Controlled current and MOSFET power limiting | Carrier requires the controlled solution for the measured ~300 µF module input. |
| Fault protection | No per-slot current measurement, timer, power limit, or power-good output | Shared 6 mΩ current shunt, programmable current/power limits, TIMER, PGD, UVLO/OVLO | Carrier protection is materially more complete. |
| Telemetry | None in the switch circuit | INA237 bus/current/power measurement using Kelvin shunt traces | Required on carrier. |
| Approx. cold conduction loss at 6.5 A | `6.5² × 15.5 mΩ ≈ 0.65 W` maximum | `6.5² × 2.0 mΩ ≈ 0.085 W` maximum | The N-FET also provides substantially lower normal loss. |

The useful concepts retained from the prototype are active-high control, passive default-off behavior, and explicit gate protection. The MOSFET, gate driver, current protection, and fault/status implementation are replaced by the LMX5069 architecture.

---

# 6. Housekeeping 3.3 V buck

## 6.1 Regulator choice

Use **LM5164DDAR**, shared with both backplane converters, rather than the
previously selected LM5163DDAR or a 60 V-class converter.

Reasons:

- 6–100 V operating range
- appropriate margin for a future 48 V bus
- synchronous architecture: no external freewheel diode
- 1 A output capability, far above expected housekeeping consumption
- suitable as a housekeeping converter for the 24–48 V nominal system architecture; the present SW3538 carrier remains limited to 24 V nominal / 30 V maximum
- common regulator and inductor BOM with the backplane

Expected housekeeping current is dominated by:

- STM32
- WS2812 at full-white brightness
- INA237
- I²C pull-ups

It is expected to remain well below 100 mA.

The RON, feedback, bootstrap, and Type-3 ripple-injection values remain
unchanged because they already match the backplane's 3.3 V LM5164 stage. At
24 V input, 3.3 V output, and approximately 300 kHz, the 100 µH inductor gives
an estimated 95 mA peak-to-peak ripple in continuous conduction. Verify the
actual switching frequency, transient response, ripple, and temperatures during
bring-up.

## 6.2 Proposed buck values

Target switching frequency: approximately **300 kHz**

| Ref | Value | Notes |
|---|---:|---|
| RRON | **27 kΩ, 1%** | ~300 kHz target |
| RFB_TOP | **110 kΩ, 1%** | Feedback |
| RFB_BOT | **62 kΩ, 1%** | Feedback |
| L1 | **100 µH** | 2.5 A Irms / 3 A saturation / 272 mΩ typical DCR |
| CIN1 | **2.2 µF / 100 V X7R** | Input ceramic |
| CIN2 | **2.2 µF / 100 V X7R** | Input ceramic |
| COUT | **22 µF / 25 V** | Output ceramic |
| COUT_HF | **100 nF** | Local output bypass |
| CBST | **2.2 nF / 50 V** | Bootstrap |
| RA | **110 kΩ, 1%** | Type-3 ripple injection |
| CA | **2.2 nF / 50 V** | Type-3 ripple injection |
| CB | **220 pF C0G / 50 V** | Type-3 ripple injection |
| R_BUCK_PG | **10 kΩ** | PGOOD pull-up to 3V3 |

Feedback target:

\[
V_{OUT}=1.2 \times \left(1+\frac{110k}{62k}\right)\approx3.33V
\]

### Optional input bulk

Provide a DNP footprint for approximately:

- **10–47 µF**
- **100 V**
- aluminum electrolytic or polymer appropriate for the final source

Populate if cable/source inductance or bench measurements indicate useful input damping.

## 6.3 Buck schematic

```text
                              VCC
                                 │
                 ┌───────────────┼────────────────┐
                 │               │                │
             CIN1 2.2u       CIN2 2.2u        optional bulk
              100 V            100 V           10–47u/100V
                 │               │                │
                GND             GND              GND
                                 │
                           ┌─────▼────────────┐
                           │ U2 LM5164        │
VCC ──────────────────►│ VIN             │
VCC ──────────────────►│ EN/UVLO         │
                           │                 │
BUCK_RON ─────────────────►│ RON             │
BUCK_FB  ─────────────────►│ FB              │
BUCK_PGOOD ◄───────────────│ PGOOD           │
BUCK_BST ─────────────────►│ BST             │
BUCK_SW  ◄─────────────────│ SW              │
GND ───────────────────────│ GND + EP        │
                           └─────────────────┘

BUCK_BST ── CBST 2.2n ── BUCK_SW

BUCK_SW ── L1 100uH ──────────── +3V3
                                      │
                                 COUT 22uF
                                      │
                                COUT_HF 100n
                                      │
                                     GND

+3V3 ── RFB_TOP 110k ──┐
                        ├── BUCK_FB
GND  ── RFB_BOT 62k ───┘

BUCK_SW ── RA 110k ── BUCK_RIPPLE
                           │
                           ├── CA 2.2n ── +3V3
                           │
                           └── CB 220p ── BUCK_FB

+3V3 ── 10k ── BUCK_PGOOD ── U1 PA8
```

---

# 7. Hot-swap, inrush, and PD branch protection

## 7.1 Power path

```text
                                 RSH1
                            6 mΩ / 3 W
VCC ═══════════════════════/\/\/\/══════════════ HS_SENSE
                           Kelvin │   │ Kelvin           │
                                  │   │                  │ D
                                  │   │             ┌────┴─────┐
                                  │   │             │ Q1       │
                                  │   │             │100 V NMOS│
                                  │   │             │Linear FET│
                                  │   │             └────┬─────┘
                                  │   │                  │ S
                                  │   │              PD_VIN_SW
                                  │   │                  │
                                  │   │                  ▼
                                  │   │                 J3
```

Q1 orientation:

- **Drain** = `HS_SENSE`
- **Source** = `PD_VIN_SW`
- **Gate** = `Q1_GATE`
- TO-263 tab = drain

## 7.2 LMX5069 pin mapping

```text
U3 LMX5069MS
────────────────────
1  SENSE
2  VIN
3  UVLO
4  OVLO
5  GND
6  TIMER
7  PWR
8  PGD
9  OUT
10 GATE
```

Connections:

```text
U3.VIN   ── Kelvin VCC side of RSH1
U3.SENSE ── Kelvin HS_SENSE side of RSH1
U3.GATE  ── Q1_GATE
U3.OUT   ── R_OUT 100Ω ── PD_VIN_SW
U3.PGD   ── PD_PGOOD
```

## 7.3 Shared current shunt

Use:

```text
RSH1 = 6.0 mΩ
Tolerance = ±1%
Power rating = 3 W
```

LMX5069 current-limit threshold:

- minimum approximately 48 mV
- typical approximately 55 mV
- maximum approximately 65 mV

Including shunt tolerance:

\[
I_{LIMIT,min}\approx\frac{48mV}{6.06m\Omega}\approx7.92A
\]

\[
I_{LIMIT,typ}\approx\frac{55mV}{6m\Omega}\approx9.17A
\]

\[
I_{LIMIT,max}\approx\frac{65mV}{5.94m\Omega}\approx10.94A
\]

This provides useful margin over the expected ~6.5 A worst normal load at 24 V.

Approximate shunt loss at 6.5 A:

\[
P=I^2R=6.5^2\times0.006\approx0.254W
\]

Approximate shunt loss near the maximum current-limit corner:

\[
P\approx10.94^2\times0.006\approx0.72W
\]

The 3 W shunt therefore has substantial thermal margin.

## 7.4 MOSFET power limit

Use:

```text
RPWR = 36.0 kΩ, 1%
```

With a 6 mΩ shunt and 48 V maximum input, the LMX5069 design equation gives approximately 41 W at the conservative low power-limit corner. It is not correct to label this value "typical."

The datasheet specifies the power-limit sense threshold only at `VDS = 48 V` and `RPWR = 150 kΩ`: 19 / 25 / 31 mV minimum / typical / maximum. Applying the controller's approximately 1 mV offset and scaling the remainder to 36 kΩ gives this first-order estimate:

| RPWR power-limit corner at 48 V | Approx. Q1 power |
|---|---:|
| Conservative design-equation minimum | **~41 W** |
| Inferred typical | **~54 W** |
| Inferred maximum | **~66 W** |

The 36 kΩ operating point is near the datasheet's recommended minimum 5 mV sense signal, so treat these as design estimates rather than guaranteed limits at this exact resistor value. Validate the limit on hardware over temperature.

Q1 SOA shall be proven against **~66 W and the maximum TIMER interval**, not 41 W / 35 ms. If that hot-corner check fails, revise `RPWR`, Q1, the timer strategy, or the controller architecture; do not release on typical behavior.

The preliminary Q1 result is favorable, not evidence of an expected failure.
At 48 V, a 66 W power limit corresponds to approximately 1.38 A. Infineon's
published 65 °C DC-SOA example for the same `IPB020N10N5LF` permits about
4.5 A at 48 V, roughly 3.3 times this first-order current. The remaining signoff
work is to prove the actual LMX5069 limit, Q1 starting/case temperature and
thermal path, the complete VDS/ID trajectory, and repeated auto-retry behavior
on this PCB.

## 7.5 Measured 300 µF module startup

Measured PD input capacitance:

```text
C_PD ≈ 300 µF
```

Energy stored at 48 V:

\[
E=\frac12CV^2
 =0.5\times300\mu F\times48^2
 \approx0.346J
\]

Using the approximately 41 W conservative minimum power-limit estimate and ~9.17 A typical current limit gives the slowest calculated LMX5069 startup interval at the 48 V corner:

```text
~8–9 ms conservative power-limit case
```

This is a very manageable startup event.

For scale, charging 300 µF to 48 V stores about 0.346 J. A persistent short at
the inferred 66 W maximum limit for the 66.5 ms maximum TIMER interval can
instead expose Q1 to as much as approximately 4.39 J per retry pulse. That is
why a successful typical startup capture alone does not close the fault-SOA
case.

Sequential external startup further reduces stress on the shared upstream supply because only one module is expected to enter startup at a time.

## 7.6 TIMER

Use:

```text
CTIMER = 680 nF, ±10%, X7R, >=16 V
Current PCB/BOM part: 0603B684K160NT / C24797
```

Approximate typical fault timeout:

\[
t_{FAULT}\approx
\frac{680nF\times3.6V}{70\mu A}
\approx35ms
\]

Approximate conservative minimum using capacitor, threshold, and timer-current corners:

```text
~20 ms
```

This remains comfortably above the expected ~8–9 ms startup interval.

Approximate conservative maximum using `CTIMER = 680 nF +10%`, the 4.0 V maximum TIMER threshold, and the 45 µA minimum fault-charge current:

\[
t_{FAULT,max}\approx
\frac{748nF\times4.0V}{45\mu A}
\approx66.5ms
\]

Use the **minimum** timeout corner to prove that valid startup completes. Use the **maximum** timeout corner to prove Q1 remains inside its hot, worst-case SOA during a persistent short. The final SOA check shall combine the approximately **66 W inferred maximum power limit** with the **66.5 ms maximum timeout**, input-voltage tolerance, PCB/Q1 starting temperature, and the applicable Infineon pulse curve; 41 W / 35 ms is not a release calculation.

### Important TIMER behavior

The LMX5069 uses the same TIMER capacitor for both:

- initial insertion/startup delay behavior
- current/power-limit fault timeout

With 680 nF, the initial insertion delay after raw VIN is first applied is considerably longer than the ~35 ms fault timer:

```text
Typical insertion delay: approximately 0.6 s
Worst-case order of magnitude: approximately 1.5 s
```

This is acceptable because:

- all carriers are expected to receive raw system power before individual PD branches are commanded on
- modules are subsequently enabled sequentially by the external controller

Firmware and system integration should nevertheless avoid assuming that `PD_PGOOD` can assert immediately after system VIN is first applied.

## 7.7 Hot-swap local decoupling

Use:

```text
C_HS = 1 µF / 100 V X7R
```

Place from `HS_SENSE` / Q1 drain to GND physically close to:

- RSH1
- U3
- Q1

---

# 8. UVLO / OVLO

Use independent UVLO and OVLO dividers.

## 8.1 UVLO

```text
VCC ── 110k ──┬── HS_UVLO
                   │
                  18k
                   │
                  GND
```

Approximate intended thresholds:

```text
UVLO rising:  ~19.8 V
UVLO falling: ~17.8 V
```

This prevents the 140 W branch from trying to operate on a substantially collapsed source.

These are typical thresholds, not a 20 V nominal-input or guaranteed-startup
specification. With the LMX5069's 25 °C threshold/hysteresis limits and ±1%
R4/R5 resistors, turn-on can reach approximately **22.56 V**. The system is
24–48 V nominal, with this carrier limited to 24 V nominal / 30 V maximum;
specify supply tolerance and harness drop and validate cold/hot startup at the
carrier connector. Do not lower UVLO solely to meet an unstated 20 V requirement.

## 8.2 OVLO

```text
VCC ── 110k ──┬── HS_OVLO
                   │
                  5.1k
                   │
                  GND
```

Approximate intended thresholds:

```text
OVLO rising:  ~56.4 V
OVLO falling: ~54.4 V
```

These divider values do not enforce the current carrier's 30 V input limit or
the SW3538's 36 V recommended maximum. They must not be interpreted as 48 V
compatibility. A future 48 V carrier needs protection coordinated with its own
module ratings; the present population's voltage limit must be enforced upstream.

---

# 9. Fail-safe PD enable logic

The PD branch must remain **OFF** if:

- the STM32 is unpowered
- the STM32 is resetting
- the STM32 GPIO is high impedance
- firmware has not explicitly requested PD power

Do not directly connect the MCU GPIO to the LMX5069 UVLO pin.

Use two 2N7002 MOSFETs:

```text
                          VCC
                             │
                           110k
                             │
                             ├──────────── KILL_GATE
                             │               │
                            36k              │ D
                             │          ┌────┴────┐
                            GND         │ Q3      │
                                        │ 2N7002 │
STM32 PD_ENABLE ──────────────── G       │        │
                                        └────┬───┘
                                             S
                                             │
                                            GND

KILL_GATE ───────────── G Q2 2N7002

HS_UVLO ─────────────── D
                        S
                        │
                       GND

PD_ENABLE ── 100k ── GND
```

Behavior:

### Default / fault-safe state

```text
MCU absent/reset/PD_ENABLE LOW
        ↓
Q3 OFF
        ↓
VIN divider drives KILL_GATE high
        ↓
Q2 ON
        ↓
HS_UVLO forced LOW
        ↓
LMX5069 holds Q1 OFF
```

### Enable state

```text
PD_ENABLE HIGH
        ↓
Q3 ON
        ↓
KILL_GATE pulled LOW
        ↓
Q2 OFF
        ↓
normal UVLO divider controls U3
        ↓
PD branch may start
```

This makes PD power control **active-high and fail-safe-off**.

---

# 10. Power-good

```text
+3V3 ── 10k ── PD_PGOOD ── U3.PGD
                         └─ U1 PA15
```

Firmware should use `PD_PGOOD` to distinguish:

- command accepted / enable asserted
- actual successful branch startup

`PD_PGOOD` is the carrier's hardware fault/status indication to the STM32. The LMX5069 does not provide a separate latched `FAULT` pin. Its open-drain `PGD` output deasserts when Q1's drain-to-source voltage rises above the power-good threshold, including while Q1 is off or a fault/retry cycle is in progress.

The LMX5069 automatically retries indefinitely at its TIMER-programmed low duty cycle after a persistent current- or power-limit timeout. That default behavior is intentional. The STM32 observes `PD_PGOOD` and decides whether to:

- leave `PD_ENABLE` asserted and permit hardware retries, or
- drive `PD_ENABLE` low to stop retries and hold the branch off.

Firmware is not in the current-limit loop and cannot weaken the autonomous hardware protection.

Recommended firmware sequence:

```text
receive POWER_ON
    │
    ▼
PD_ENABLE = 1
    │
    ▼
wait for PD_PGOOD
    │
    ├── asserted → probe PD module over I2C1
    │
    └── timeout  → report branch startup failure
```

---

# 11. INA237 current / voltage / power monitor

## 11.1 Measurement topology

The INA237 uses the same RSH1 shunt as the LMX5069.

Use separate Kelvin sense traces from the shunt pads.

```text
Kelvin VIN side
      │
     10Ω
      │
      ├──────── INA_INP_FILT ───── U4 IN+
      │
    100nF
      │
      ├──────── INA_INM_FILT ───── U4 IN-
      │
     10Ω
      │
Kelvin HS_SENSE side
```

The 100 nF capacitor is differential between filtered IN+ and IN- nodes.

## 11.2 INA237 pin map

```text
U4 INA237AIDGSR
────────────────────
1  A1
2  A0
3  ALERT
4  SDA
5  SCL
6  VS
7  GND
8  VBUS
9  IN-
10 IN+
```

Connections:

```text
U4.IN+   = INA_INP_FILT
U4.IN-   = INA_INM_FILT
U4.VBUS  = PD_VIN_SW
U4.VS    = +3V3
U4.GND   = GND
U4.SDA   = PD_I2C_SDA
U4.SCL   = PD_I2C_SCL
U4.ALERT = INA_ALERT
```

`VBUS` is deliberately measured **after Q1**, while current is measured through the upstream RSH1.

Thus the reported load power is approximately the actual voltage presented to the PD module multiplied by branch current.

## 11.3 INA237 ADC range

Configure:

```text
ADCRANGE = 0
Shunt full scale = ±163.84 mV
```

The smaller ±40.96 mV range is not suitable because:

```text
9.17 A × 6mΩ ≈ 55 mV
10.94 A × 6mΩ ≈ 65.6 mV
```

## 11.4 Address

Fixed configuration:

```text
A0 -> GND
A1 -> GND

I²C address = 0x40
```

Each carrier contains only one INA237. Tie A0 and A1 directly to GND; do not fit address-selection or alternate-address strap resistors.

## 11.5 ALERT

```text
+3V3 ── 10k ── INA_ALERT ── U4.ALERT
                         └─ U1 PB5
```

---

# 12. STM32

## 12.1 MCU

```text
U1 = STM32C092GCU6
Package = UFQFPN-28
```

No external crystal is required for this design.

## 12.2 Proposed pin assignment

| Physical pin | STM32 pin | Net / function |
|---:|---|---|
| 1 | PC14 | spare |
| 2 | PC15 | USER_BUTTON_N |
| 3 | VDD/VDDA | +3V3 |
| 4 | VSS/VSSA | GND |
| 5 | PF2/NRST | NRST |
| 6 | PA0 | spare |
| 7 | PA1 | spare |
| 8 | PA2 | spare |
| 9 | PA3 | spare |
| 10 | PA4 | spare |
| 11 | PA5 | spare |
| 12 | PA6 | spare |
| 13 | PA7 | spare |
| 14 | PB0 | CAN_RX / FDCAN_RX |
| 15 | PB1 | CAN_TX / FDCAN_TX |
| 16 | PA8 | BUCK_PGOOD |
| 17 | PC6 | PD_IRQ |
| 18 | PA9/PA11 | spare |
| 19 | PA10/PA12 | spare |
| 20 | PA13 | SWDIO |
| 21 | PA14 | SWCLK |
| 22 | PA15 | PD_PGOOD |
| 23 | PB3 | PD_ENABLE |
| 24 | PB4 | spare |
| 25 | PB5 | INA_ALERT |
| 26 | PB6 | PD_I2C_SCL / I2C1 |
| 27 | PB7 | PD_I2C_SDA / I2C1 |
| 28 | PB8 | LED_DATA_RAW |

## 12.3 MCU support

Recommended:

```text
+3V3 ── 100nF ── GND   near MCU supply pins
+3V3 ── 4.7uF  ── GND  local bulk

+3V3 ── 10k ── NRST
NRST ── 100nF ── GND
```

Expose test/programming pads:

```text
TP_SWDIO
TP_SWCLK
TP_NRST
TP_3V3
TP_GND
```

Use pogo/test pads rather than a permanent connector unless mechanical constraints favor otherwise.

---

# 13. CAN-FD and local I²C architecture

## 13.1 Backplane CAN-FD

The STM32 uses its FDCAN peripheral for backplane communication. A TCAN3413DR translates the 3.3 V logic interface to the differential CAN bus. The connector-side network includes a common-mode choke, a PESD2CANFD27V ESD protector, and optional 120 Ω termination selected by SJ1.

```text
U1 PB1 / FDCAN_TX ───── U5.TXD
U1 PB0 / FDCAN_RX ───── U5.RXD
GND                 ───── U5.STB

U5.CANH ── CAN_PHY_P ── L3 ── CAN_BUS_P ───── J1 pin 3
U5.CANL ── CAN_PHY_N ── L3 ── CAN_BUS_N ───── J1 pin 4
GND                              J1 pin 2
```

SJ1 and R26 provide endpoint termination. Populate/bridge the termination only when this carrier is physically at a bus end. U5 `STB` is intentionally tied low so the transceiver is permanently in normal mode; this carrier does not need MCU-controlled CAN standby. Place D2 adjacent to the connector on the bus side of L3. In the current PCB, D2 is intentionally placed as close to J1 and the local GND return as the connector/mechanical constraints permit. KiCad differential-pair naming uses `CAN_BUS_P/N` on the connector side and `CAN_PHY_P/N` on the transceiver side, where P is CANH and N is CANL; route each pair tightly coupled, symmetric, and length-matched.

## 13.2 Local / downstream I²C1

The STM32 is controller/master.

```text
U1 PB6 / I2C1_SCL ───── PD_I2C_SCL
U1 PB7 / I2C1_SDA ───── PD_I2C_SDA

U4 INA237.SCL ─────────── PD_I2C_SCL
U4 INA237.SDA ─────────── PD_I2C_SDA

J3.PD_I2C_SCL ─────────── PD_I2C_SCL
J3.PD_I2C_SDA ─────────── PD_I2C_SDA
```

Populate:

```text
+3V3 ── 2.2k ── PD_I2C_SCL
+3V3 ── 2.2k ── PD_I2C_SDA
```

CAN-FD messages may request downstream I²C transactions, but application logic must terminate and validate the CAN protocol before accessing the local bus. This allows firmware to:

- isolate downstream transaction failures
- report PD module communication failures upstream
- power-cycle the PD branch independently
- recover/reinitialize I2C1 without disturbing backplane CAN-FD communication

---

# 14. NeoPixel status LED

Use:

```text
LED1 = WS2812B-2020-V6
Supply = +3V3
```

Connection:

```text
U1 PB8 ── 100Ω ── LED1.DIN

+3V3 ───────────── LED1.VDD
  │
  └── 100nF ── GND

LED1.GND ───────── GND
LED1.DOUT ──────── NC
```

The V6 device is intended to operate directly from the 3.3 V rail, avoiding a logic-level translator.

---

# 15. Input TVS

Use:

```text
DTVS1 = Hongjiacheng SMCJ48A
LCSC C19077611
```

Connection:

```text
VCC ─────┬──────── rest of carrier
             │
           DTVS1
             │
            GND
```

Place immediately behind the input connector with very short high-current and ground return paths.

## TVS validation concern

The populated SMCJ48A must be qualified for transients on the current 24 V
nominal / 30 V maximum system, including voltage at MOD1. It does not clamp
the input to the SW3538's recommended range. Any 48 V/50 V TVS characterization
belongs to a future appropriately rated carrier or a separately reviewed test
fixture with the SW3538 removed, not to a populated Rev-A carrier.

For raw-bus transients, the INA237 is one important limiting device; this does
not supersede MOD1's lower input-voltage limit:

```text
INA237 maximum bus/common-mode range: 85 V
```

The selected TVS has a nominal clamp in the high-70-V range under its specified pulse conditions, leaving finite but not enormous margin to 85 V.

Validate on the actual:

- supply
- cable/harness
- connector
- branch current
- board layout

under:

- module enable
- module disable
- downstream short
- upstream hot-plug
- hot-unplug / interruption

If measured transients approach the INA237 absolute maximum, revise the TVS/protection architecture.

---

# 16. Complete logical netlist

The following is a signal-level connectivity specification for schematic implementation.

Exact manufacturer pin numbers and footprint pad numbering must be checked against current datasheets and verified in ERC/PCB review.

```text
# ============================================================
# RAW INPUT
# ============================================================

NET VCC
    J1.VIN+
    DTVS1.K
    U2.VIN
    U2.EN_UVLO
    CIN1.1
    CIN2.1
    C_BULK_OPTIONAL.1
    RSH1.POWER_IN
    U3.VIN                # Kelvin from RSH1 upstream pad
    RUV_TOP.1
    ROV_TOP.1
    R_KILL_TOP.1
    R_INA_P.1             # Kelvin from RSH1 upstream pad

NET GND
    J1.GND[*]
    DTVS1.A
    U5.STB

    U2.GND
    U2.EXPOSED_PAD
    CIN1.2
    CIN2.2
    C_BULK_OPTIONAL.2
    COUT.2
    COUT_HF.2
    RRON.2
    RFB_BOT.2

    U3.GND
    C_HS.2
    CTIMER.2
    RPWR.2
    RUV_BOT.2
    ROV_BOT.2

    Q2.S
    Q3.S
    R_KILL_BOT.2
    R_PD_EN_PD.2

    U4.GND
    U4.A0
    U4.A1
    C_INA_SUPPLY.2

    U1.VSS_VSSA
    C_MCU.2
    C_MCU_BULK.2
    C_NRST.2

    LED1.GND
    C_LED.2

    J3.GND[*]

    TP_GND

# ============================================================
# LM5164 BUCK
# ============================================================

NET BUCK_SW
    U2.SW
    L1.1
    CBST.2
    RA.1

NET BUCK_BST
    U2.BST
    CBST.1

NET BUCK_RON
    U2.RON
    RRON.1

NET BUCK_RIPPLE
    RA.2
    CA.1
    CB.1

NET BUCK_FB
    U2.FB
    RFB_TOP.2
    RFB_BOT.1
    CB.2

NET +3V3
    L1.2
    COUT.1
    COUT_HF.1

    CA.2
    RFB_TOP.1

    U1.VDD_VDDA
    C_MCU.1
    C_MCU_BULK.1
    R_NRST.1

    U4.VS
    C_INA_SUPPLY.1
    R_ALERT.1

    LED1.VDD
    C_LED.1

    R_PD_SCL.1
    R_PD_SDA.1

    R_PGD.1
    R_BUCK_PG.1

    TP_3V3

NET BUCK_PGOOD
    U2.PGOOD
    R_BUCK_PG.2
    U1.PA8

# ============================================================
# HIGH-CURRENT PD BRANCH
# ============================================================

NET HS_SENSE
    RSH1.POWER_OUT
    Q1.DRAIN
    C_HS.1

    U3.SENSE              # Kelvin from RSH1 downstream pad
    R_INA_N.1             # Kelvin from RSH1 downstream pad

NET Q1_GATE
    U3.GATE
    Q1.GATE

NET PD_VIN_SW
    Q1.SOURCE
    J3.PD_VIN[*]
    U4.VBUS
    R_OUT.2

NET LMX_OUT
    U3.OUT
    R_OUT.1

# ============================================================
# LMX5069 PROGRAMMING
# ============================================================

NET HS_UVLO
    U3.UVLO
    RUV_TOP.2
    RUV_BOT.1
    Q2.D

NET HS_OVLO
    U3.OVLO
    ROV_TOP.2
    ROV_BOT.1

NET HS_TIMER
    U3.TIMER
    CTIMER.1

NET HS_PWR
    U3.PWR
    RPWR.1

NET PD_PGOOD
    U3.PGD
    R_PGD.2
    U1.PA15

# ============================================================
# FAIL-SAFE PD ENABLE
# ============================================================

NET KILL_GATE
    R_KILL_TOP.2
    R_KILL_BOT.1
    Q2.G
    Q3.D

NET PD_ENABLE
    U1.PB3
    Q3.G
    R_PD_EN_PD.1

# ============================================================
# INA237
# ============================================================

NET INA_INP_FILT
    R_INA_P.2
    U4.IN+
    C_INA_DIFF.1

NET INA_INM_FILT
    R_INA_N.2
    U4.IN-
    C_INA_DIFF.2

NET INA_ALERT
    U4.ALERT
    R_ALERT.2
    U1.PB5

# ============================================================
# LOCAL / DOWNSTREAM I2C1
# ============================================================

NET PD_I2C_SCL
    U1.PB6
    U4.SCL
    R_PD_SCL.2
    J3.PD_I2C_SCL

NET PD_I2C_SDA
    U1.PB7
    U4.SDA
    R_PD_SDA.2
    J3.PD_I2C_SDA

# ============================================================
# BACKPLANE CAN-FD
# ============================================================

NET CAN_TX
    U1.PB1
    U5.TXD

NET CAN_RX
    U1.PB0
    U5.RXD

NET CAN_PHY_P
    U5.CANH
    L3.CAN_PHY_P

NET CAN_PHY_N
    U5.CANL
    L3.CAN_PHY_N

NET CAN_BUS_P
    L3.CAN_BUS_P
    D2.IO1
    SJ1.1
    J1.3

NET CAN_BUS_N
    L3.CAN_BUS_N
    D2.IO2
    R26.2
    J1.4

# ============================================================
# LED
# ============================================================

NET LED_DATA_RAW
    U1.PB8
    R_LED.1

NET LED_DATA
    R_LED.2
    LED1.DIN

# ============================================================
# RESET / DEBUG
# ============================================================

NET NRST
    U1.NRST
    R_NRST.2
    C_NRST.1
    TP_NRST

NET SWDIO
    U1.PA13
    TP_SWDIO

NET SWCLK
    U1.PA14
    TP_SWCLK
```

---

# 17. Passive BOM

Commodity resistors/capacitors may use the assembler's preferred stocked LCSC basic part where the electrical requirements are met.

For high-voltage ceramics, shunt components, and timing/programming values, preserve the specified electrical characteristics.

## 17.1 Resistors

| Ref | Qty | Value | Tolerance / notes |
|---|---:|---:|---|
| RSH1 | 1 | **6 mΩ** | 1%, 3 W, low TCR |
| RRON | 1 | **27 kΩ** | 1% |
| RFB_TOP | 1 | **110 kΩ** | 1% |
| RFB_BOT | 1 | **62 kΩ** | 1% |
| RA | 1 | **110 kΩ** | 1% |
| R_BUCK_PG | 1 | **10 kΩ** | 1% |
| R_OUT | 1 | **100 Ω** | 1–5% |
| RUV_TOP | 1 | **110 kΩ** | 1% |
| RUV_BOT | 1 | **18 kΩ** | 1% |
| ROV_TOP | 1 | **110 kΩ** | 1% |
| ROV_BOT | 1 | **5.1 kΩ** | 1% |
| RPWR | 1 | **36.0 kΩ** | 1% |
| R_PGD | 1 | **10 kΩ** | 1% |
| R_KILL_TOP | 1 | **110 kΩ** | 1% |
| R_KILL_BOT | 1 | **36.0 kΩ** | 1% |
| R_PD_EN_PD | 1 | **100 kΩ** | 1–5% |
| R_INA_P | 1 | **10 Ω** | 1% |
| R_INA_N | 1 | **10 Ω** | 1% |
| R_ALERT | 1 | **10 kΩ** | 1% |
| R_NRST | 1 | **10 kΩ** | 1% |
| R_PD_SCL | 1 | **2.2 kΩ** | local I²C pull-up |
| R_PD_SDA | 1 | **2.2 kΩ** | local I²C pull-up |
| R26 | 1 | **120 Ω** | CAN termination, DNP unless enabled by SJ1 |
| R_LED | 1 | **100 Ω** | LED data series |

## 17.2 Capacitors

| Ref | Qty | Value | Rating / notes |
|---|---:|---:|---|
| CIN1 | 1 | **2.2 µF** | 100 V X7R |
| CIN2 | 1 | **2.2 µF** | 100 V X7R |
| C_BULK_OPTIONAL | 1 | **10–47 µF** | 100 V, DNP initially |
| COUT | 1 | **22 µF** | 25 V |
| COUT_HF | 1 | **100 nF** | >=10 V |
| CBST | 1 | **2.2 nF** | 50 V |
| CA | 1 | **2.2 nF** | 50 V |
| CB | 1 | **220 pF** | C0G, 50 V |
| C_HS | 1 | **1 µF** | 100 V X7R |
| CTIMER | 1 | **680 nF** | X7R, >=16 V, ~10% |
| C_INA_DIFF | 1 | **100 nF** | differential shunt-input filter |
| C_INA_SUPPLY | 1 | **100 nF** | local INA237 bypass |
| C_MCU | 1 | **100 nF** | MCU bypass |
| C_MCU_BULK | 1 | **4.7 µF** | MCU/local 3V3 bulk |
| C_NRST | 1 | **100 nF** | reset |
| C_LED | 1 | **100 nF** | LED local bypass |

---

# 18. Suggested LCSC parts for selected passives

These are convenience selections, not architectural requirements unless noted.

| Function | Suggested part | LCSC |
|---|---|---|
| 6 mΩ / 3 W shunt | HoLLR2512-3W-6mR-1% | **C2985709** |
| 100 µH inductor | PROD Tech PSPMAA0805-101M-ANP | **C2962892** |
| 2.2 µF / 100 V X7R | Samsung CL32B225KCJSNNE, 1210 | **C55151** |
| 22 µF / 25 V output MLCC | Samsung CL21A226MAQNNNE, 0805 | **C45783** |
| 1 µF / 100 V X7R | Samsung CL31B105KCHNNNE | **C13832** |
| 680 nF timer capacitor | 0603B684K160NT, 0603 | **C24797** |
| 2N7002 | commodity stocked 2N7002 | **C8545** |

For low-voltage generic 0603 resistors and decoupling capacitors, prefer existing BOM values/basic parts already used elsewhere in the product when electrically equivalent.

---

# 19. Connector interfaces

The existing carrier/backplane connector is a combined two-power-contact plus two-signal-contact interface. There is no separate upstream control connector and no backplane-provided 3.3 V rail.

## J1 — combined backplane interface

```text
pin 1 = VCC
pin 2 = GND
pin 3 = CAN_BUS_P / CANH
pin 4 = CAN_BUS_N / CANL
```

The power contacts and PCB copper shall support the 140 W architecture case and the short-duration current-limit current. Route CANL/CANH as a controlled, tightly coupled differential pair appropriate for the selected CAN-FD data rate and physical length.

The routed carrier PCB is the controlling definition: `pin 1 = VCC`, `pin 2 = GND`, `pin 3 = CANH / CAN_BUS_P`, and `pin 4 = CANL / CAN_BUS_N`. Update every mating backplane connector to produce this mapping at the physical contacts. When checking a male/female pair, use the manufacturer mating-face drawings or continuity measurements rather than inferring numbering from an unlabeled PCB-side view.

J1 is intentionally excluded from the assembly BOM. The assembled PCB is expected
to ship without this right-angle XT30PW(2+2) connector; the user installs and
solders J1 after assembly.

## J3 — PD-module interface

```text
PD_VIN_SW       multiple contacts as required
GND             multiple contacts as required
PD_I2C_SCL
PD_I2C_SDA
+3V3_AUX        optional if useful
SPARE_GPIO0     optional
SPARE_GPIO1     optional
```

The live KiCad design uses `MOD1` for the SW3538 module footprint. `MOD1` is
intentionally excluded from the assembly BOM because the user installs and
solders the PD module after PCB assembly.

---

# 20. Expected startup sequence

```text
System VIN applied
    │
    ├── DTVS1 clamps transient events
    │
    └── LM5164 starts +3V3
             │
             ▼
        STM32 starts
             │
             │
             └── hardware kill logic keeps LMX5069 UVLO low
                  regardless of MCU reset/high-Z state
             │
             ▼
external controller eventually selects this module
             │
             ▼
upstream POWER_ON command
             │
             ▼
PD_ENABLE = HIGH
             │
             ▼
Q3 grounds KILL_GATE
             │
             ▼
Q2 releases HS_UVLO
             │
             ▼
LMX5069 validates VIN/UVLO/OVLO
             │
             ▼
Q1 turns on under current/power control
             │
             ▼
~300 µF PD input capacitance charges
             │
             ▼
PD_PGOOD asserts
             │
             ▼
STM32 probes PD module over I2C1
             │
       ┌─────┴─────┐
       │           │
    success      failure
       │           │
      ready     report / controlled retry
```

---

# 21. Fault behavior

## 21.1 Downstream short

Expected hardware sequence:

```text
downstream short
    │
    ▼
RSH1 differential voltage rises
    │
    ▼
LMX5069 enters current/power limiting
    │
    ▼
TIMER runs
    │
    ▼
fault persists beyond timer
    │
    ▼
LMX5069 shuts Q1 off
    │
    ├── PD_PGOOD deasserts to STM32
    │
    ▼
LMX5069 waits at its programmed low retry duty cycle
    │
    ├── PD_ENABLE remains HIGH → automatic retries continue
    │
    └── STM32 drives PD_ENABLE LOW → branch held OFF
```

Automatic retry is the accepted default. Firmware is not part of the primary protection loop; it only decides whether continued hardware retries are appropriate after observing `PD_PGOOD` and other telemetry.

## 21.2 MCU crash/reset

Hardware default:

```text
MCU PD_ENABLE LOW/high-Z
    │
    ▼
Q3 OFF
    │
    ▼
Q2 ON
    │
    ▼
UVLO forced low
    │
    ▼
PD branch OFF
```

## 21.3 Brownout

The PD branch should naturally disable if:

- VIN falls below programmed LMX5069 UVLO
- MCU housekeeping collapses and PD_ENABLE is lost

The branch should therefore fail toward OFF rather than partially commanded ON.

## 21.4 PD module communication failure

Firmware should be able to:

1. report an I2C1 failure upstream over CAN-FD
2. clear/reinitialize I2C1
3. disable `PD_ENABLE`
4. allow the PD module's onboard housekeeping supply to discharge `PD_VIN_SW`
5. re-enable the branch
6. wait for `PD_PGOOD`
7. reprobe the module

Keep the backplane CAN-FD interface operational while recovering the downstream I²C bus.

No dedicated bleeder is required on `PD_VIN_SW`. The PD module's onboard low-power supply remains connected to its input capacitors and discharges them to zero after Q1 turns off. Confirm the discharge time on the assembled module during bring-up; add no carrier bleeder unless that measurement disproves the assumption.

---

# 22. PCB layout requirements

These requirements are important enough to include as schematic notes.

## 22.1 High-current path

Keep the branch geometrically direct:

```text
J1.VIN
   ═════════ RSH1 ═════════ Q1 ═════════ J3.PD_VIN
```

Design for:

- >=6.5 A continuous
- >10 A short-duration limit/fault current
- minimum unnecessary neck-down
- multiple copper layers where practical
- adequate via arrays at layer transitions

## 22.2 Shunt Kelvin routing

RSH1 is physically a two-terminal power resistor, but its measurement connections must be routed as Kelvin senses.

High-current copper:

```text
VIN plane/pour ===== [ RSH1 ] ===== HS_SENSE power copper
```

Sense traces:

```text
inner edge VIN pad ───── U3.VIN
                   └──── R_INA_P

inner edge OUT pad ───── U3.SENSE
                   └──── R_INA_N
```

Do not pick up current-sense traces from arbitrary points in the surrounding pours.

## 22.3 Hot-swap component placement

Keep:

- RSH1
- U3
- Q1
- C_HS

physically close.

The pass-MOSFET gate and controller loops should be short and quiet.

## 22.4 Q1 thermal / SOA layout

Q1's normal conduction dissipation is small because its on-resistance is very low.

The important thermal event is linear-mode operation during:

- controlled startup
- overload limiting
- downstream short until timeout

Give the TO-263 drain/tab substantial copper and thermal vias.

Do not optimize Q1 layout based only on its steady-state conduction loss.

## 22.5 LM5164 layout

Critical converter loop:

```text
CIN → LM5164 switching stage → GND → CIN
```

Requirements:

- CIN immediately adjacent to VIN/GND
- short high-di/dt current loop
- small `BUCK_SW` copper area
- L1 immediately adjacent to SW
- feedback/ripple network on quiet side of L1
- keep `BUCK_FB` away from SW and gate-current paths
- solid ground reference under the converter where permitted by TI guidance

## 22.6 TVS placement

Place DTVS1 immediately behind J1.

Its return to ground must be:

- short
- wide
- direct

Do not route TVS surge current through narrow logic-ground sections.

## 22.7 Grounding

Use a continuous ground plane rather than artificially splitting logic and power grounds.

Route high branch current so its return path does not create narrow shared impedances underneath:

- MCU
- INA237
- feedback networks
- I²C

## 22.8 Existing-outline fit assessment

The present carrier outline is usable for the Rev-A electronics, but the result is constrained rather than spacious.

Relevant geometry from the current PCB:

| Region | Approximate geometry | Consequence |
|---|---:|---|
| Main board | **66.25 × 34.30 mm** (`x=115.50…181.75`, `y=96.35…130.65`) | Overall envelope remains unchanged. |
| PD-module front courtyard | **68.4 × 34.0 mm** (`x≈114.8…183.2`, `y≈95.8…129.8`) | It covers essentially the entire component side; do not plan normal top-side carrier components under the module. |
| Central PCB cutout | **~27.35 × 27.05 mm** (`x≈135.10…162.45`, `y≈98.84…125.89`) | Removes most of the center on both sides. |
| Left bottom-side lobe | **~19.6 × 34.3 mm**, before connector/pad keepouts | Primary candidate for TVS, shunt, LMX5069, Q1, and nearby high-current support parts. |
| Right bottom-side lobe | **~19.3 × 34.3 mm**, locally narrowed to **~12.2 mm** by the PD module's USB-C edge notch | Split into buck and MCU/monitor placement zones; use the neck primarily for routing. |
| Center top/bottom routing rails | approximately **2.5 mm top** and **4.8 mm bottom** around the cutout | Useful for signals and parallel copper assistance, not major component placement. |

Courtyard-level package rectangles fit with the following provisional bottom-side floorplan:

```text
BACKPLANE / XT30 END                                  USB-C END

┌──────── connector tongue ────────┬──────── main board ────────────────┐
│                                  │ LEFT LOBE    CUTOUT    RIGHT LOBE  │
│                                  │ TVS/RSH/LMX  ┌─────┐   BUCK block  │
│                                  │ Q1 D2PAK     │ PD  │   3V3 logic   │
│                                  │ gate support │module│   MCU/INA/LED │
│                                  │              └─────┘               │
└──────────────────────────────────┴─────────────────────────────────────┘
                                     all new parts on B.Cu side
```

Fit conclusion:

- **Yes:** the existing 2D outline is sufficient for a first 140 W-capable carrier layout if the new circuitry is placed predominantly on the bottom side.
- **No:** it is not credible as a top-side-only or two-layer implementation.
- Q1 and the 8 × 8.5 × 5.0 mm maximum buck inductor are the limiting package/height items. Before placement is frozen, confirm at least their bottom-side mechanical clearance in the rack assembly.
- Reserve Q1's entire available local lobe width for copper and thermal vias where possible. Passing a courtyard check alone is not sufficient thermal validation.
- Perform a real placement/routing review after the schematic is captured; the present result is a feasibility floorplan, not evidence that an unrouted board is production-ready.

## 22.9 Required stackup and copper

Rev A shall use a 4-layer, 1.6 mm stackup with 1 oz outer copper and 0.5 oz inner copper. Keep CAN, I²C, and ordinary signal routing on the outer layers over continuous reference copper. No dedicated 3.3 V plane is required; use both internal layers as solid GND reference planes:

```text
L1 / F.Cu    1 oz      module pads, high-current pours, signals
L2 / In1.Cu  0.5 oz    solid GND
L3 / In2.Cu  0.5 oz    solid GND
L4 / B.Cu    1 oz      components, high-current pours, signals
```

The PCB implements the internal planes as the `GND_IN1` and `GND_IN2` zones. Refill both planes as part of every final production export. The central cutout makes the remaining copper rails narrow. Use filled copper on every useful layer, parallel paths where the net permits, and dense through-via arrays at layer transitions. Validate finished copper thickness and the exact dielectric stack with the fabricator at order time.
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

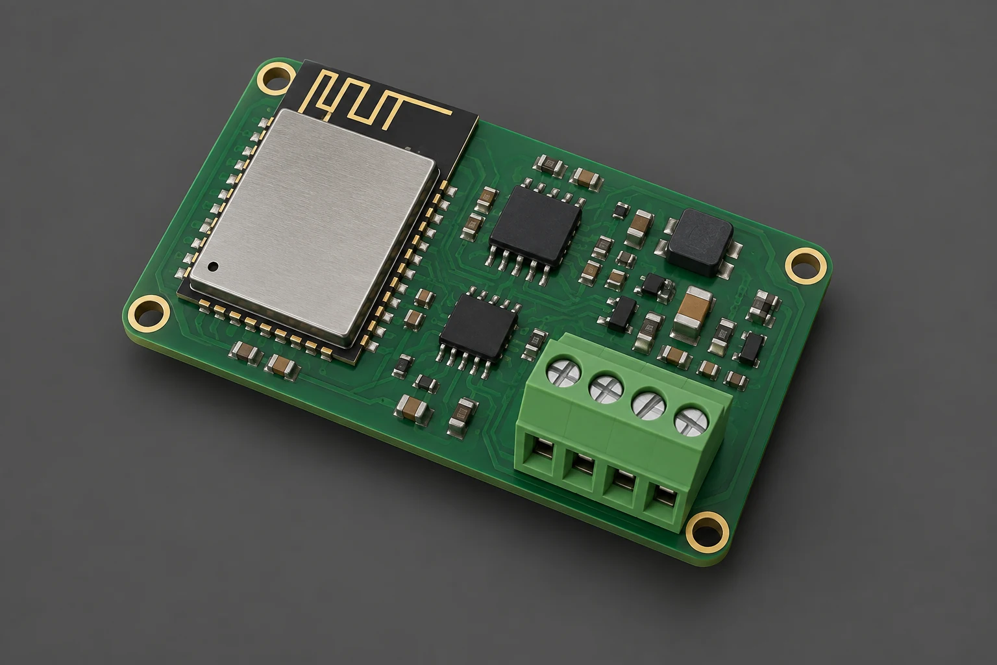
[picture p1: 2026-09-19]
site/content/system/hardware/gateway/_files/gateway-concept.webp

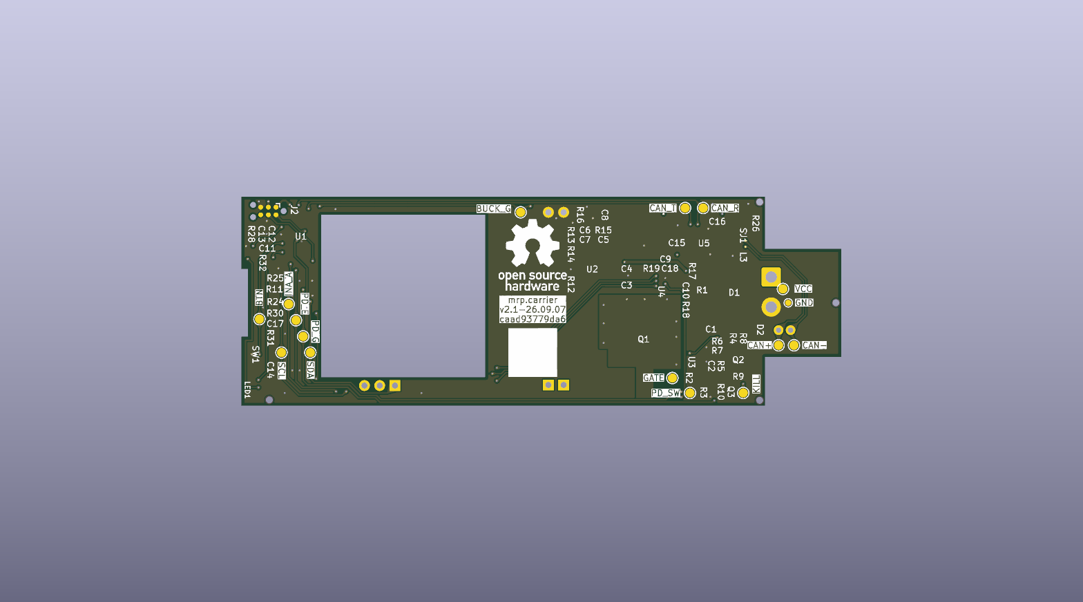
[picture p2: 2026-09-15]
site/content/system/hardware/modules/carrier/_files/carrier-bottom.webp

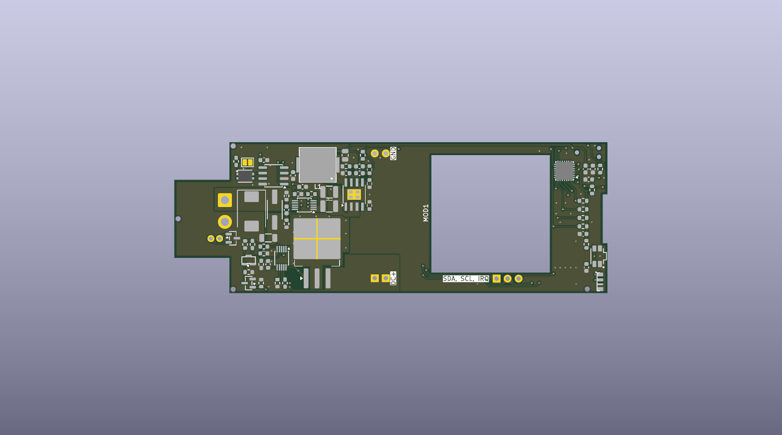
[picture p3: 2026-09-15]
site/content/system/hardware/modules/carrier/_files/carrier.webp

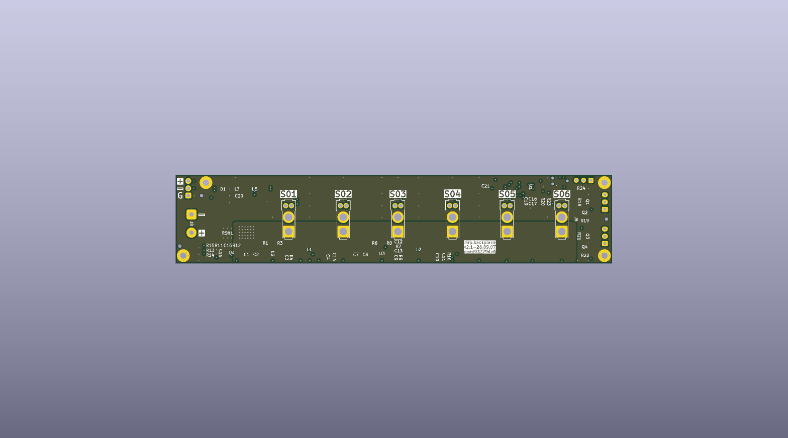
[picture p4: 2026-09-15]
site/content/system/hardware/backplane/_files/backplane-bottom.webp

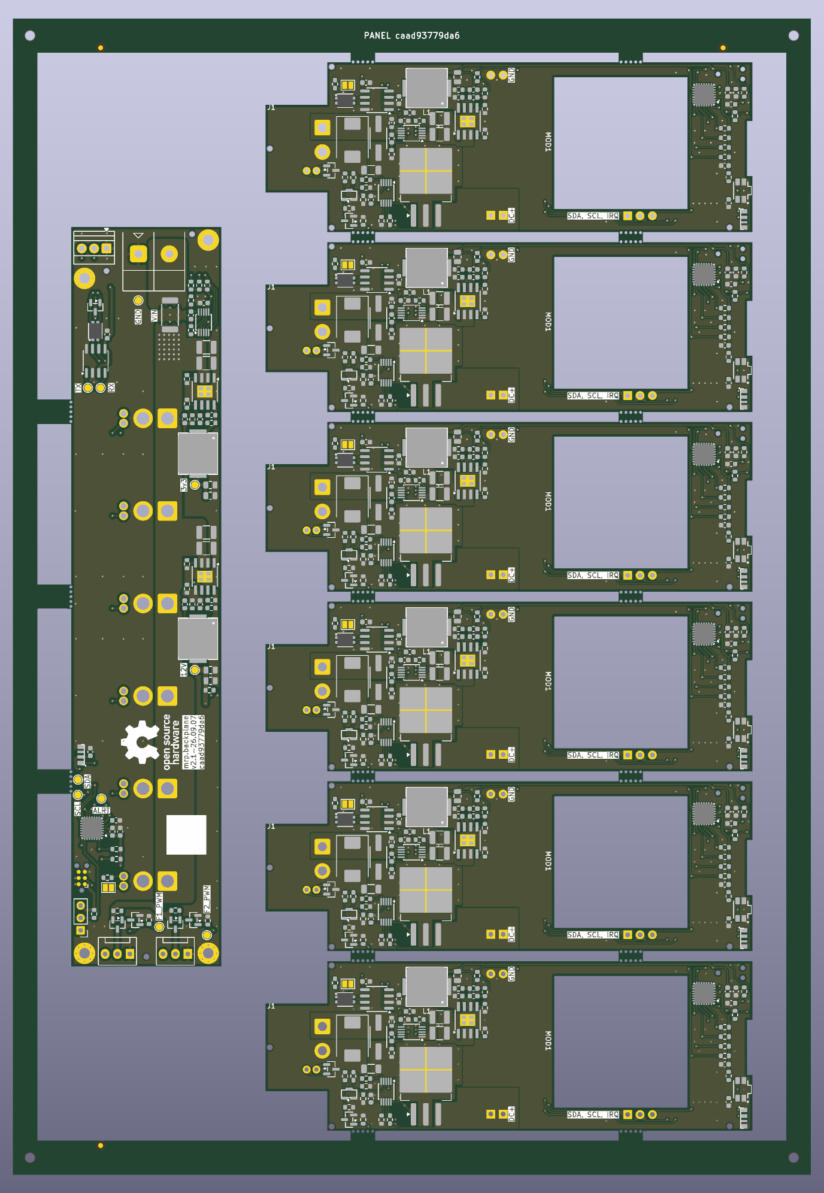
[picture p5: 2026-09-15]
site/content/system/hardware/_files/panel.webp

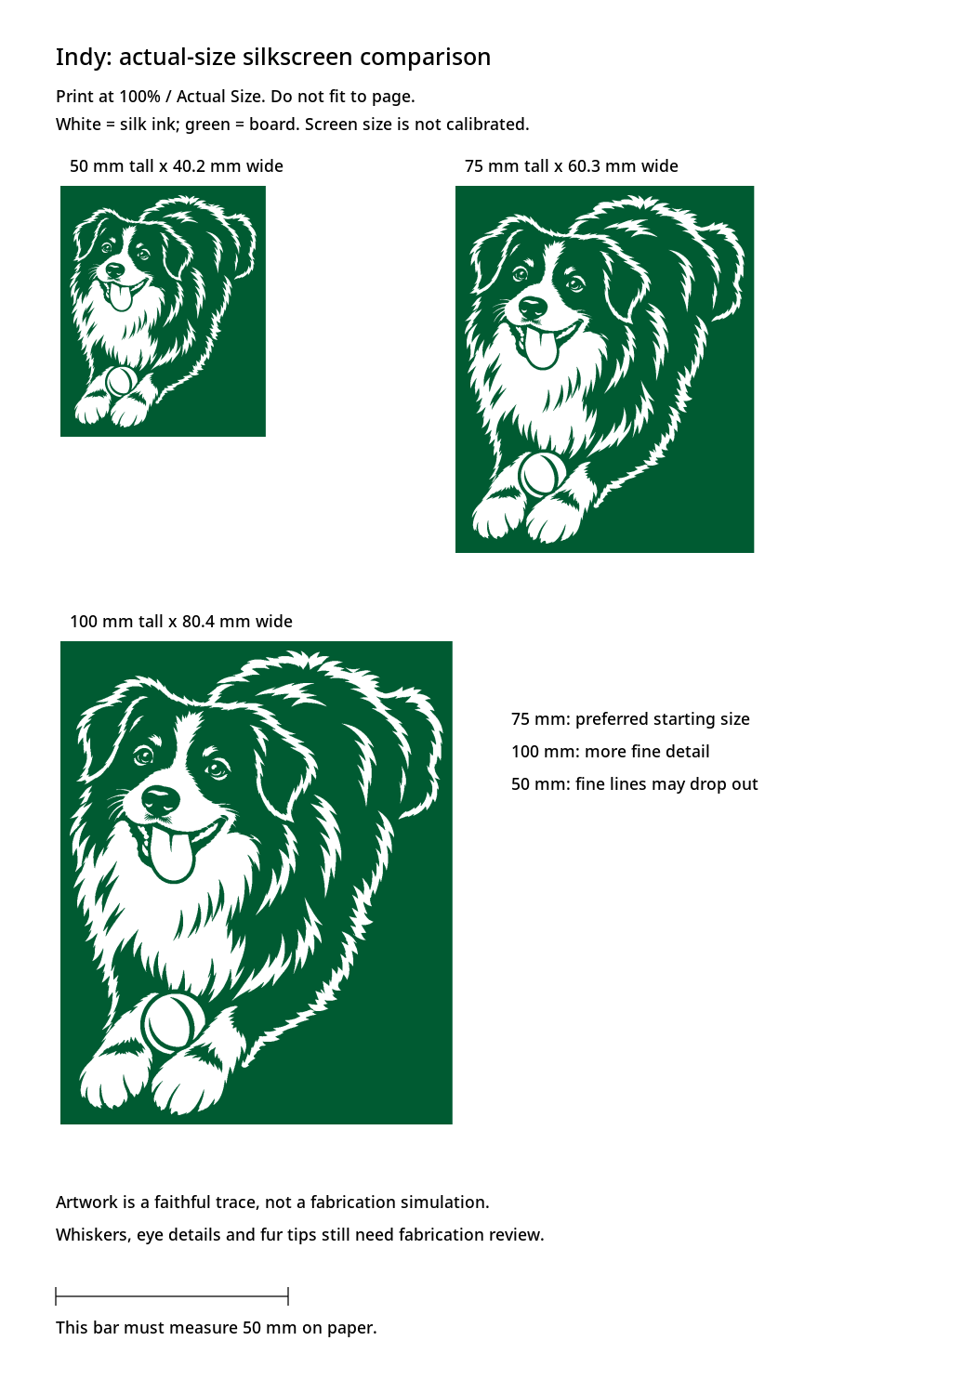
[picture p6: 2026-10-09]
hardware/artwork/indy/indy-size-proof.png

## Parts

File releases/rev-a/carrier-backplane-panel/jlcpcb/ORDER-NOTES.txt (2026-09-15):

Mini Rack Power carrier/backplane Rev A panel

Vendor: jlcpcb
Panel: 6 carrier PCBs + 1 backplane prototype PCB
Panel dimensions: 163.800 mm x 237.350 mm
Panel build Git revision: 35e47c0
Construction: FR-4, 4 layers, 1.6 mm, ENIG
Copper: 2 oz outer layers, 1 oz inner layers
Separation: routed gaps (2 mm minimum) with 5 mm mouse-bite tabs
Mouse bites: 0.6 mm NPTH, 0.95 mm pitch (0.35 mm edge-to-edge)
Assembly side: top only
Different designs in panel: 2

Upload the nested Gerber ZIP for PCB fabrication, then upload BOM.csv and
positions.csv in the assembly step. Do not ask the vendor to re-panelize or
depanelize before assembly. Ask CAM engineering to preserve the supplied
customer panel, tooling holes, fiducials, routed gaps, and mouse bites.

Select 'Panelized PCBs already in Gerber' / customer-supplied panel and set
'Different Designs' to 2. For PCBA, use the complete panel BOM/CPL option and
prefer Standard PCBA; ask engineering to confirm the 2 oz outer / 1 oz inner
stack-up before payment.

Order quantity is the number of complete panels. Each panel yields six carrier
boards and one backplane board. Do not permit component substitutions without
approval; PCBWay BOM rows marked 'Not specified in released BOM' must be matched
to the exact LCSC part stated in the Customer Notes field.

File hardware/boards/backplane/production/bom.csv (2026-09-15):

Designator | Footprint | Quantity | Value | LCSC Part #
C1, C2, C7, C8 | C_1210_3225Metric | 4 | 2.2uF 100V | C55151
C3, C5, C9, C12 | C_0603_1608Metric | 4 | 2.2nF 50V | C1604
C4, C10, C11, C14 | C_0805_2012Metric | 4 | 22uF 25V | C45783
C6 | C_0603_1608Metric | 1 | 220pF C0G | C106210
C13 | C_0603_1608Metric | 1 | 56pF 50V C0G | C1676
C15, C16, C17, C19, C20, C21, C22 | C_0603_1608Metric | 7 | 100nF | C14663
C18 | C_0603_1608Metric | 1 | 4.7uF | C19666
D1 | SOT-23 | 1 | PESD2CANFD27V-TR | C552488
L1, L2 | L_PRODTech_PSPMAA0805 | 2 | 100uH | C2962892
L3 | L_CommonModeChoke_TDK_ACT1210D | 1 | ACT1210D-101-2P-TL00 | C3039743
LED1 | LED_Worldsemi_WS2812B-4020-V6_SideView | 1 | WS2812B-4020-V6 | C52941387
Q1, Q3 | SOT-23 | 2 | AO3407A | C15155
Q2, Q4 | SOT-23 | 2 | 2N7002 | C8545
R1 | R_0603_1608Metric | 1 | 27k 1% | C22967
R2, R4 | R_0603_1608Metric | 2 | 110k 1% | C25805
R3 | R_0603_1608Metric | 1 | 62k 1% | C23221
R6, R18, R19, R21, R22 | R_0603_1608Metric | 5 | 100k 1% | C25803
R7 | R_0603_1608Metric | 1 | 453k 1% | C25818
R8 | R_0603_1608Metric | 1 | 49.9k 1% | C23184
R9 | R_0603_1608Metric | 1 | 330k 1% | C23137
R10, R15, R20, R23 | R_0603_1608Metric | 4 | 10k | C25804
R11, R12 | R_0603_1608Metric | 2 | 10R | C22859
R13, R14 | R_0603_1608Metric | 2 | 2.2k | C4190
R17 | R_0603_1608Metric | 1 | 120R 1% | C22787
R24 | R_0603_1608Metric | 1 | 4.7k 1% | C23162
RSH1 | R_2512_6332Metric | 1 | 1mR 1% 6W | C19270875
U1 | QFN-28_4x4mm_P0.5mm | 1 | STM32C092GCU6 | C44847705
U2, U3 | TI_SO-PowerPAD-8 | 2 | LM5164DDAR | C477928
U4 | MSOP-10_3x3mm_P0.5mm_0.20mm_Clearance | 1 | INA237AIDGSR | C2864837
U5 | SOIC-8_3.9x4.9mm_P1.27mm | 1 | TCAN3413DR | C22433320

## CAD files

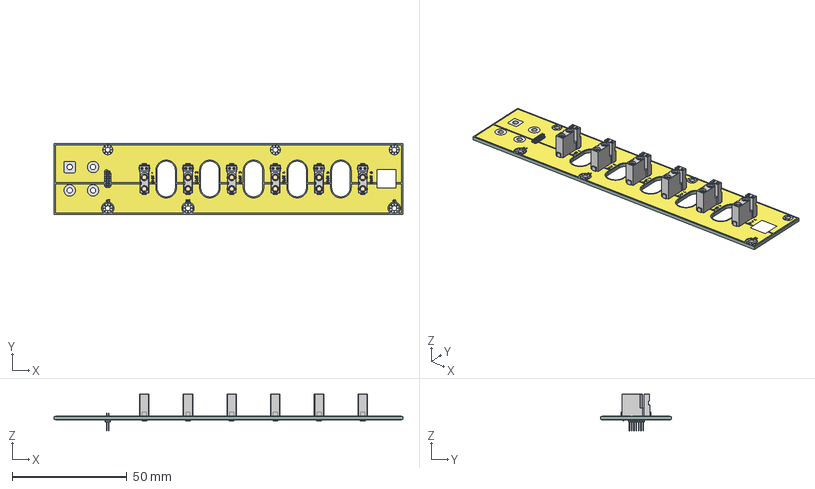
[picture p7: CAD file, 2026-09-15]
hardware/mechanical/exports/backplane/backplane-prototype.m1v2.step
151.8 x 30.8 x 16.1 mm
XT30(2+2) x 6
PinHeader_2x07_P100mm_Vertical
backplane-prototype-unsaved-export-cCUPBU_copper
backplane-prototype-unsaved-export-cCUPBU_pad
backplane-prototype-unsaved-export-cCUPBU_silkscreen x 2
backplane-prototype-unsaved-export-cCUPBU_PCB

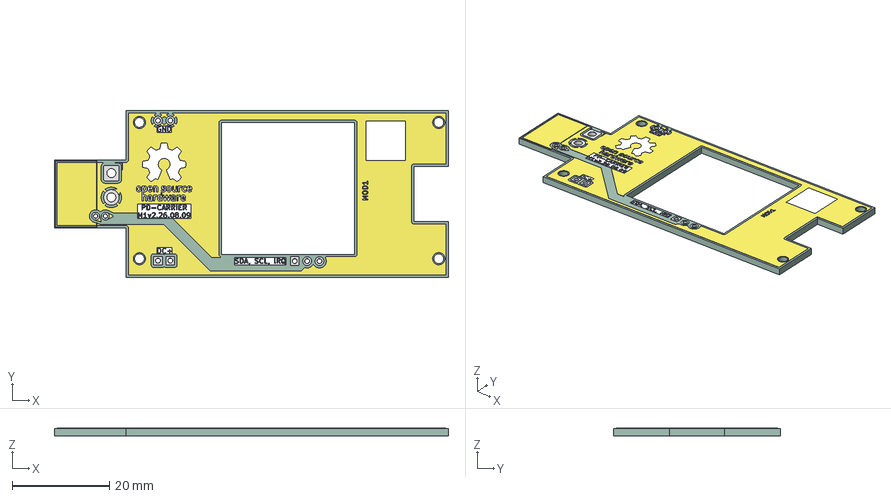
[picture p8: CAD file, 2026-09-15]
hardware/mechanical/exports/carrier/carrier-bare-pcb.m1v2.step
81.0 x 34.3 x 1.62 mm
carrier-unsaved-export-CTJ2nq_copper
carrier-unsaved-export-CTJ2nq_pad
carrier-unsaved-export-CTJ2nq_silkscreen
carrier-unsaved-export-CTJ2nq_PCB

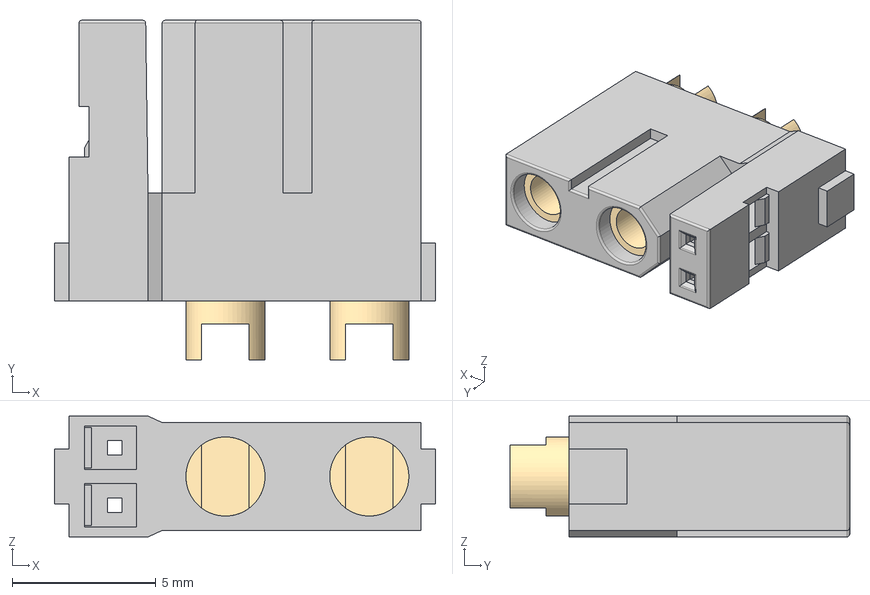
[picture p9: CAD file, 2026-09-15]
hardware/mechanical/exports/components/XT30(2+2).step
13.2 x 11.8 x 4.20 mm

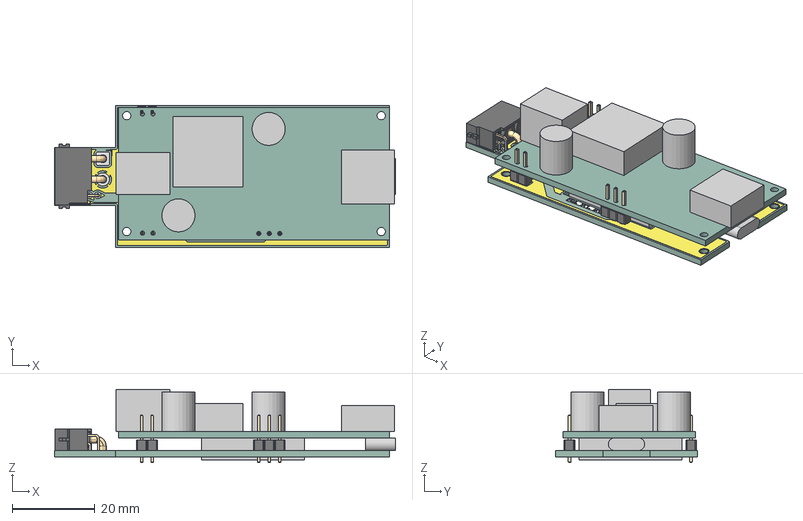
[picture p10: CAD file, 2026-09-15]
hardware/mechanical/exports/carrier/carrier-with-module.m1v2.step
82.4 x 34.3 x 17.8 mm
dc-jack
caps
inductor
usb-a
usb-c
heat-sinks
PinHeader_1x02_P254mm_Vertical x 2
PinHeader_1x03_P254mm_Vertical
XT30(2+2)PW-M
carrier-unsaved-export-DCpNC6_copper
carrier-unsaved-export-DCpNC6_pad
carrier-unsaved-export-DCpNC6_silkscreen
carrier-unsaved-export-DCpNC6_PCB

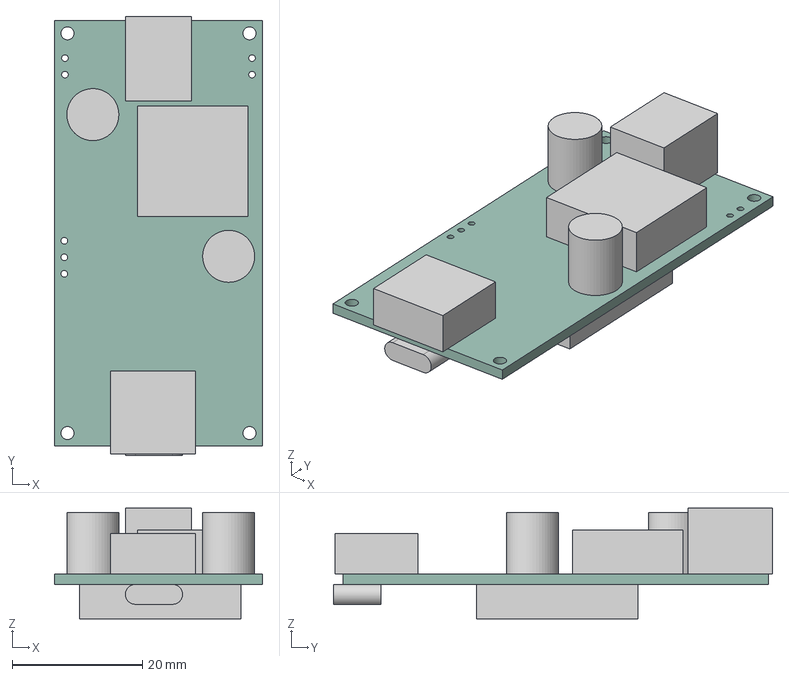
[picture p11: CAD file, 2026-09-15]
hardware/mechanical/exports/components/SW3538_140W_Module.step
32.0 x 67.6 x 17.1 mm

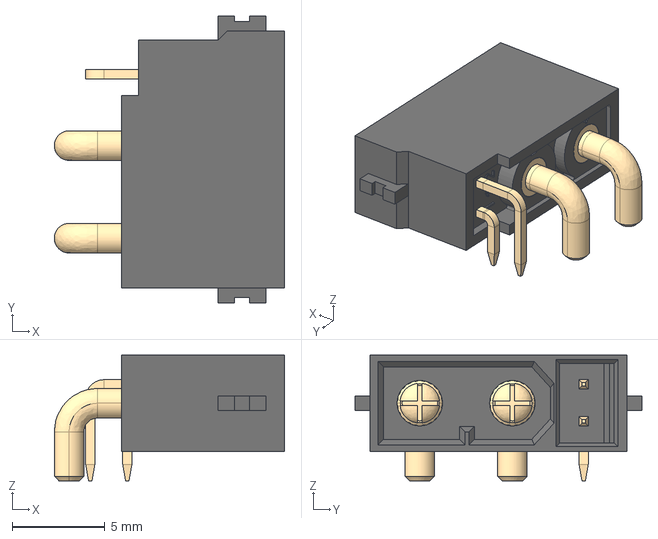
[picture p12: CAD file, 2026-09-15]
hardware/mechanical/exports/components/XT30(2+2)PW-M.step
12.4 x 15.5 x 6.80 mm

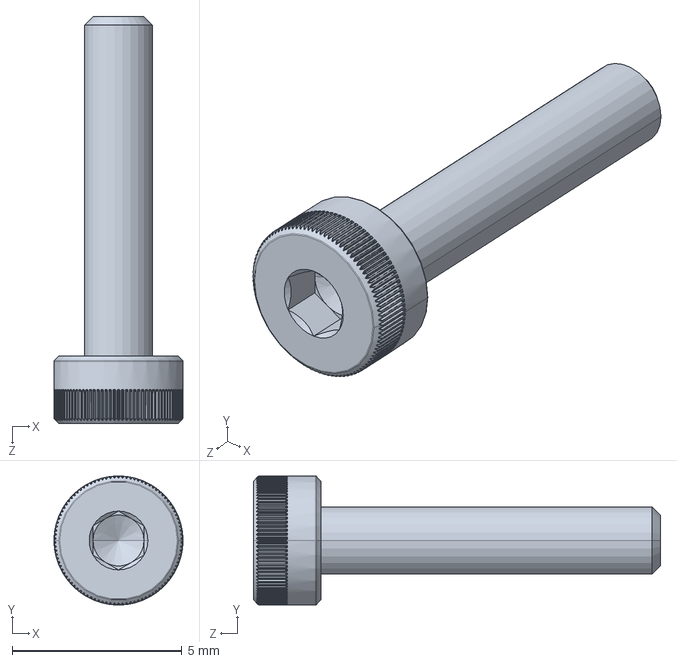
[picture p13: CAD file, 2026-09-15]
hardware/mechanical/components/90128A181_NO THREADS_Zinc-Plated Alloy Steel Socket Head Screw (1).STEP
3.80 x 3.80 x 12.0 mm

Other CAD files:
hardware/mechanical/exports/components/SW3538_140W_Module.dxf
hardware/mechanical/exports/components/XT30(2+2).dxf

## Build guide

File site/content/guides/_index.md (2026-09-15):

---
title: Guides
description: Practical build, assembly, and bring-up instructions.
icon: book-open
weight: 2
---

These guides cover practical work on the Modular Rack Power system. Observe the
limits and readiness notes in the system documentation before assembling or
powering hardware.

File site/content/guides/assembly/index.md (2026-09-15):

---
title: Assembly
description: Interactive PCB assembly references for the backplane and carrier.
weight: 1
---

Use the interactive BOMs to locate parts while assembling the current PCB
prototypes:

- [Backplane interactive BOM](_files/backplane-ibom.html)
- [Carrier interactive BOM](_files/carrier-ibom.html)

These are assembly aids, not fabrication-readiness approvals. Review the
system documentation and release checks before ordering, assembling, or
powering a board.

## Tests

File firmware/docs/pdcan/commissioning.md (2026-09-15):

# Node Commissioning and Carrier Binding

Every STM32 supplies an immutable 96-bit UID. A commissioned node additionally
stores one mutable Node ID from 1 through 254. Node 0 is reserved for broadcast;
255 is invalid.

## Discovery

`pdcan scan` broadcasts a nonce. Every node replies directly with its UID,
optional Node ID, commissioning state, protocol version, role, carrier profile,
hardware revision, capabilities, update impact, firmware version, bootloader
version, and partition-layout version. Discovery works before commissioning.

```sh
pdcan scan --interface can0
pdcan identify 00112233445566778899aabb --seconds 10
pdcan assign 00112233445566778899aabb 17
pdcan clear-node 00112233445566778899aabb
```

Assignments and clears are addressed by immutable UID and carry a request ID.
Nodes periodically claim their configured address. If two distinct UIDs claim
the same Node ID, each enters `AddressConflict`, suppresses ordinary operational
traffic, remains safe, and continues commissioning traffic so the conflict can
be corrected.

## Optional carrier binding

A carrier may persist `{backplane_uid, slot_index}` as descriptive metadata:

```sh
pdcan bind 17 aabbccddeeff001122334455 0
pdcan clear-binding 17
```

Slot indexes are zero-based. The backplane UID remains stable when its Node ID
changes. Binding does not route messages, grant authority to the backplane, or
prove physical placement. Host software may resolve a human-facing
`backplane.slot` alias to the carrier's current Node ID after discovery.

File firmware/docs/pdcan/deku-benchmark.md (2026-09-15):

# Deku codec experiment

Measured on 2026-09-13 on branch `codex/deku-codec-bench`, based on
`main` at `9680cd3992865a311ab963fa6192fc00b31434e8`. The trial was preserved
as commit `3e4f021` and as [deku-trial.patch](deku-trial.patch). The implementation
and experimental Cargo feature are excluded from the firmware on `main`.

**Decision: do not use Deku in firmware; retain the manual codecs.**
[Decision 0002](../../../docs/decisions/0002-do-not-use-deku-in-firmware.md)
records the accepted outcome. Deku works without a heap and preserves the tested
wire behavior, but the measured costs do not justify adoption for these layouts.
The linked codec probe grows by 12,436 bytes with the current default release
profile, or 1,100 bytes with size optimization and LTO. This report preserves the
completed trial as evidence.

The experiment uses Deku 0.20.3 with default features disabled: no runtime `std`,
`alloc`, or `bits`. It changes `POWER` payload encoding/decoding and
`SET_CARRIER_POLICY` body encoding/limit decoding. Request IDs, CAN identifier
packing, and semantic validation remain in the existing codec. The default build
continues to use manual serialization.

The derived structs contain raw integers and fixed arrays. Boolean, reserved-byte,
source, header, and exact-length checks run in the original validation layer.
The fixed-layout helpers use `expect` only after the caller has established buffer
length; they introduce no parse assertions on unvalidated enum or boolean values.

## Correctness

- All 69 workspace tests pass with the default codecs and with `deku-codec`.
- New independent vectors cover little-endian fields, signed extrema, optional
  policy limits, invalid flags, reserved fields, and incorrect lengths.
- Both builds produce identical output for all 54,128 differential corpus records.
  The corpus includes 4,096 valid messages of each type, exhaustive single-byte
  replacements on four examples of each type, lengths 0–80, every CAN identifier
  bit flipped individually, and deterministic arbitrary inputs. Successful decoded
  values, encoded frames, and exact error variants are compared.
- Corpus SHA-256: `da462110e5835a25b8ddf316a192802f66a9c36521c3b15421953241b0cb6c32`.
- Standard `cargo xtask ci` passes on Rust 1.98.1, including formatting, default
  workspace tests, Clippy, DBC consistency, embedded checks, and firmware size gates.
- Workspace Clippy with Deku enabled and embedded Clippy for the size probe pass.

## Embedded size

Rust 1.98.1 / LLVM 22.1.8, `thumbv6m-none-eabi`. Values are bytes. Flash is
`text + data`; static RAM is `data + bss` from `llvm-size`.

| Image/profile | Manual flash | Deku flash | Change | Static RAM, both |
|---|---:|---:|---:|---:|
| Backplane, default release | 13,728 | 13,724 | -4 | 248 |
| Carrier, default release | 13,704 | 13,704 | +0 | 248 |
| Bootloader, default release | 14,732 | 14,732 | +0 | 32 |
| Codec probe, default release | 8,700 | 21,136 | +12,436 | 24 |
| Codec probe, `z` + LTO + 1 codegen unit | 5,380 | 6,480 | +1,100 | 24 |

The current application entry points do not call these codecs. Their sizes therefore
do not measure codec adoption cost; the four-byte backplane difference should not be
interpreted as a Deku saving. The separate `carrier/examples/codec-size.rs` probe
uses opaque inputs and consumes all four codec results, keeping the relevant code
linked. It also retains the existing control dispatcher. It is a link-only probe,
not an application image to flash.

The probe links without an allocator. Static RAM does **not** include stack usage;
stack high-water marks and MCU execution time were not measured. The optimized
profile was supplied only to probe build commands; repository release settings
were not changed. Its result is not an estimate for every future message layout.

## Host timing

AMD Ryzen 9 5950X, x86_64 Linux, Rust 1.98.1, default Cargo bench/release profile.
Values are median nanoseconds per full public codec call. Each process warms up
for 100,000 calls, then measures 21 batches of 100,000 calls per operation. The
table takes the median of three process medians, alternating variant order.
There are 256 varied inputs; half the policy inputs omit PD limits. Inputs and
outputs pass through `black_box`. Timing includes indexing/loop overhead; CPU
affinity and frequency were not fixed. These are host measurements, not MCU timing.

| Operation | Manual ns | Deku ns | Deku/manual |
|---|---:|---:|---:|
| `encode_power` | 8.23 | 8.14 | 0.99× |
| `decode_power` | 10.61 | 9.50 | 0.90× |
| `encode_policy` | 22.26 | 31.77 | 1.43× |
| `decode_policy` | 13.78 | 14.81 | 1.07× |
| `reject_power_reserved` | 7.60 | 7.60 | 1.00× |
| `reject_policy_reserved` | 11.17 | 11.17 | 1.00× |

The largest observed host regression is policy encoding. Power decoding is faster
in this host build; small differences in the other operations should not drive an
embedded design decision. Rejected reserved bytes are checked before the Deku
parser runs, so similar rejection timings are expected.

## Reproduction

From the repository root, create a separate checkout of the original base and
apply the archived trial patch. This reproduces the experiment without changing
the firmware on `main`:

```sh
git worktree add --detach ../modular-rack-power-deku-trial \
  9680cd3992865a311ab963fa6192fc00b31434e8
git -C ../modular-rack-power-deku-trial apply \
  "$PWD/firmware/docs/pdcan/deku-trial.patch"
cd ../modular-rack-power-deku-trial
rustup target add thumbv6m-none-eabi --toolchain 1.98.1
rustup component add llvm-tools-preview --toolchain 1.98.1
python3 firmware/scripts/bench_deku.py
```

The runner reads the pinned version from `firmware/rust-toolchain.toml`, passes it
explicitly to Rust commands, uses `--locked`, and keeps separate build directories
for the two variants. It runs protocol tests, compares complete corpus output,
builds all three firmware images and both probe profiles, captures feature trees,
and performs the host timing runs. A corpus mismatch fails the run and saves both
outputs for inspection. Results are written to `firmware/target/deku-bench/results.json`.

This run is preserved in [deku-benchmark-results.json](deku-benchmark-results.json),
including per-process timing ranges and feature trees.

In the separate checkout prepared above, the rejected experiment can also be
built directly (this is not a production build configuration):

```sh
cd firmware
cargo +1.98.1 build -p carrier-firmware --bin carrier --release \
  --target thumbv6m-none-eabi --features firmware-bin,pdcan-protocol/deku-codec
```

Broader adoption is not planned. Reconsideration requires a new decision supported
by materially different requirements or measurements under the intended firmware
release profile, including MCU latency and stack usage. The current decision is
to retain the manual firmware codecs.

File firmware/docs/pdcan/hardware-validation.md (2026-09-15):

# Generation-2 Firmware Hardware Validation

- Status: pending first-article firmware bring-up on the finalized boards
- Scope: observations that compilation, unit tests, simulation, and fake flash
  cannot establish

A checked item needs the board revision/serial, firmware commit, supply and
load conditions, instrument setup, measured result, and pass/fail rationale.

## Common MCU, boot, and safe state

- [ ] Confirm both boards boot the common STM32C092GCU6 bootloader and their
  role-specific application from the documented flash partitions.
- [ ] Confirm the bootloader never enables carrier power output or changes a
  backplane fan from its hardware-safe state.
- [ ] Measure reset-to-application and watchdog-reset behavior, including every
  RCC reset-cause flag that firmware reports.
- [ ] Cut power during configuration erase, payload programming, and commit;
  verify the last complete record is selected and outputs remain safe.
- [ ] Verify a persisted emergency latch survives full power loss and watchdog
  reset, and explicit acknowledgement clears it without enabling an output.
- [ ] Measure stack high-water marks, worst-case interrupt latency, and watchdog
  margins under maximum CAN, sensor, LED, and flash activity.

## CAN-FD network

- [ ] Verify STM32 PB0 RX/PB1 TX and the permanently enabled TCAN3413 on both
  boards at the selected nominal/data bit rates over the intended harness.
- [ ] Verify extended CAN-FD+BRS traffic among a host, at least one backplane,
  and multiple carriers; confirm classic, standard-ID, and non-BRS traffic is
  ignored.
- [ ] Validate the commissioning claim window with startup skew, duplicate Node
  IDs, token collisions/retries, multiple backplanes, and representative load.
- [ ] Exercise error-passive, bus-off, recovery, unplug/replug, missing
  termination, and excessive-stub cases without unsafe output transitions.
- [ ] Measure emergency-command latency to each carrier's `PD_ENABLE` low state
  under idle, saturated-bus, I2C-busy, flash-write, and watchdog conditions.
- [ ] Confirm loss of any backplane does not prevent the host from addressing a
  carrier which remains powered and attached to the CAN trunk.

## Backplane

- [ ] Confirm NeoPixel data is PA1 and validate waveform timing, reset interval,
  startup-off behavior, and electrical levels.
- [ ] Confirm fan 0 PWM/tach is PA2/PB8 and fan 1 PWM/tach is PA0/PA8.
- [ ] Validate 3-wire fan supply-PWM polarity/frequency, tach scaling, startup,
  stall detection, and the pair's combined load on the 1 A 12 V rail.
- [ ] Confirm I2C2 PA6/PA7 communicates only with INA237 address `0x40`, and INA
  alert on PA4 wakes/flags the expected path.
- [ ] Validate the 1 mOhm shunt in narrow-range mode across expected current,
  temperature, reverse-current, overrange, and alert conditions.
- [ ] Confirm DS18B20 1-Wire on PA15 with external power, including CRC failure,
  missing sensor, conversion timeout, unplug/replug, and long-cable behavior.
- [ ] Confirm PA3 12 V power-good gating and recovery behavior.
- [ ] Verify aggregate inrush and fan startup remain within supply/backplane
  limits when several independently booting carriers are inserted.

## Current SW3538 carrier

- [ ] Confirm PB3 `PD_ENABLE` is held low before peripheral initialization and
  remains low after reset, corrupt configuration, emergency, or unrecoverable
  fault.
- [ ] Confirm PA15 `PD_PGOOD`, PC6 `PD_IRQ`, PA8 `BUCK_PGOOD`, PB5 INA alert,
  PC15 user button, and PB8 NeoPixel against the production board.
- [ ] Confirm I2C1 PB6/PB7 reaches only the local INA237 and SW3538 circuitry;
  inject stuck SDA/SCL and verify bounded recovery or safe disable.
- [ ] Validate the 6 mOhm INA237 configuration across output operating range and
  compare measured current/power with calibrated instruments.
- [ ] Validate SW3538 identity, unlock/bank transitions, enable/disable,
  interrupt handling, contract/fault decoding, and return to the base bank after
  interrupted transactions.
- [ ] Prove advertised fixed PDOs remain at or below 20 V, 5 A, and 100 W and
  that unsupported PPS, EPR, and nonstandard 7 A behavior cannot be enabled.
- [ ] Measure the interval from enable through policy application and confirm
  failures or timeouts return `PD_ENABLE` low.
- [ ] Verify the SW3538 profile advertises `interrupt` update impact and that the
  host refuses activation without `--allow-interruption`.

## Firmware update and rollback

- [ ] Stage valid backplane and carrier bundles from the host over CAN and
  confirm target/profile/revision/layout mismatches are rejected before write.
- [ ] Drop, duplicate, reorder, corrupt, and delay data frames; verify cumulative
  ACK/retry behavior, byte-for-byte duplicate checks, gap rejection, and final
  SHA-256 verification.
- [ ] Reset or remove power during every erase/write/finish/activate boundary;
  verify the node boots either the last confirmed image or a fully verified
  staged image, never partial data.
- [ ] Confirm staging does not interrupt normal service for both update-impact
  profiles; activation follows the profile's declared live/interrupt contract.
- [ ] Boot an intentionally unhealthy candidate and verify Embassy Boot rollback
  after the bounded confirmation window.
- [ ] Boot a healthy candidate and verify `mark_booted`, durable running-version
  metadata, subsequent reset, and another update.
- [ ] Confirm a host can update a carrier while its backplane is absent; observe
  that no backplane-to-carrier updater traffic exists.

## Release evidence

Before calling firmware production-ready, archive CAN traces, firmware bundle
hashes, flash maps, power-interruption matrix, timing distributions, thermal and
load conditions, and all deviations. Promote provisional constants only after
the measured worst case and margin have been reviewed.

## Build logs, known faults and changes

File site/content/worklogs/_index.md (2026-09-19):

---
title: Worklogs
description: Informal development updates and expanded release notes for Modular Rack Power.
icon: clock
---

Journaling about progress on long-term projects is not new to me… but doing it publicly, in the repo is.

We’ll see how this goes!

The worklogs section is for recording design decisions, experiments, setbacks, and milestones as the project evolves.

Think of it as a running diary of the project's development / a "self-contained and DIY" version of [hackaday.io](https://hackaday.io/).

Entries describe what was understood at the time and may be superseded by later work.
Use the system documentation for the current most accurate and curated reference.

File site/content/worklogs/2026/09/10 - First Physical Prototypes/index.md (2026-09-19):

---
title: 'First Physical Prototypes'
date: 2026-09-10
description: After a lot of re architecture, the second-generation design is now ready for first-article prototypes.
tags:
  - hardware
slug: '10-first-physical-prototypes'
draft: false
resources:
  - src: _files/early_prototype_01.webp
    name: early_prototype_01
    title: Early enclosure prototype
    params:
      alt: CAD view of the open rack enclosure with a power supply and a row of carrier modules
      caption: Early enclosure layout with the power supply and carrier modules.
  - src: _files/early_prototype_02.webp
    name: early_prototype_02
    title: Early rack layout
    params:
      alt: CAD view of two computers mounted above the power enclosure, with colored lines indicating cable routes
      caption: Early rack layout showing the computers above the power enclosure and proposed cable routing.
---

I thought it would be appropriate for the first entry to do two things:

1. Cover the initial physical prototypes
2. Announce that the first "actual" prototypes have been sent off for manufacturing.

## Initial Physical Prototypes

Please see the [system overview]( {{< ref "system/" >}}) for a high-level overview of the goal/purpose, and architecture that is being implemented in these prototypes.

Everything below is some form of initial thought/concept that led to the current design of the first physical prototypes.

From the very beginning, the target form-factor has been a 1U rack-mountable enclosure.

The very first mockups focused on the ["mini-rack" form factor](https://mini-rack.jeffgeerling.com/) just to see how many distinct USB-C ports I could afford to fit within a 'narrow' 1U space.

{{< figure name="early_prototype_01" >}}

With a standard MEAN WELL shaped power supply, it looked like the answer was "at most 6 ports".

After some _very_ early feedback from a small circle of friends, 6 ports is just above what they'd need for their own mini-rack home-labs in most cases.
It's enough to power up to 5 nodes + a switch... which could then use PoE to power a KVM or other peripheral devices as needed.

For the few people I spoke with that have a "tall" rack, eating another 1U for 6 more ports was considered acceptable.
In 12U of height, two power units can power 10 nodes and you'd still have a bit of spare capacity for additional peripherals.

This was the beginning of a more scalable approach; you should be able to 'link' multiple units together.
Even if each unit was going to have it's own power supply, you could still manage them collectively and link their telemetry and control interfaces for unified management across the entire rack.

Prior to this point, the plan was to do everything within a single 1U unit, likely with I2C or Modbus which does not lend itself well to scaling across multiple linked units.

I don't have any renders to show at this point, but it just so happens that you can comfortably fit two backplanes (for a total of 12 ports) within a single "full-width" 1U unit.

Before settling on 6 total ports, some additional layouts were considered for smaller racks; this early design had some space 'reserved' for cable management.

{{< figure name="early_prototype_02" >}}

The "2-4 ports, with cable mgmt room" design was the earliest iteration of the physical layout; from the _very beginning_ an Ethernet port for telemetry and web based management was considered essential.

I don't have too much more from the _early_ prototypes to show here but hopefully this gives a sense of the initial direction and design considerations and where some of the core ideas originated.

Right now, the design is focused on _at most_ 100W per USB-C but if you look through this repo carefully, you might notice that _some_ documents / schematic sections are "ready" for a 240W cap per port.

240W is the current limit of what USB-C can do and I'm not even sure how practical it is given that _most_ of the loads this is aimed at need ~20V.
The 240W envelope uses 5A at 48V, which would need a step-down converter to provide the ~20V required by most of the intended loads... which defeats some of the simplicity and efficiency benefits of using USB-C for these lower power devices.

So for now, 240W _is_ a future "maybe?" goal.

Before pushing the power envelope, there are so many other aspects of this design that need proving and refinement before I add higher power capabilities and the associated complexity to the list.

Besides the "most PCs don't operate on 48V" problem, the 100W limit is driven by several factors, some of which include:

- Going above 100W per port is going to require building my own USB-C/PD circuitry, which adds complexity and cost and is out of scope for the initial prototypes.
  - There are no "off the shelf" modules that I can find on Ali Express right now that support more than 100W per port using _standard_ USB-C/PD specifications. Some can do 140W but using non-standard implementations that would require building my own custom source/trigger circuitry.
- Thermal management becomes significantly more challenging above 100W per port, requiring more advanced cooling solutions... especially in small form-factor enclosures where airflow is limited.
- Components rated for the higher voltages/currents are more expensive.
- 100W is a _lot_ considering this is targeting "small form-factor" PCs often used in home labs.
  - Yes, lots of these PCs come with power supplies rated _just above_ 100W but that's typically the maximum they can draw... with the CPU pegged _and_ several power-hungry things plugged in to the USB Ports. My intended use case assumes that the computer is not pegged at 100% load all of the time nor is it burdened with power hungry peripherals.
  - In my own home-lab, 10 different general purpose compute nodes are often running simultaneously and the **total power draw** across all nodes is usually under 3.5A total (about 21V, so roughly 73.5W).
  - At some point, I hope to be able to afford some more powerful local LLM nodes which _will_ demand 100W+ by themselves.

## PCBWay

Shortly after this little endeavour started to move from a concept to an actual "I should actually sit down and design this properly, not hack something together" project, [PCBWay](https://pcbway.com/g/LybhZ4) reached out and offered to cover _some_ of the costs associated with producing the first ever prototype articles.

After some consideration, I decided to take them up on their offer for a few reasons:

- They're [proud to support educational and hobbyist projects like mine](https://www.pcbway.com/project/sponsor/). That deserves recognition and appreciation!

- Prototyping is expensive. SO MUCH of what makes modern day electronics 'cheap' is the result of large-scale manufacturing and economies of scale. When you're producing just a few units, the cost per unit is significantly higher, and having some of those costs covered is a huge help.
- Some of the BOM uses components that are _new_ and therefore not widely available or easy to source reliably. At least one supplier went out-of-stock on a critical component _while I was finishing layout_! Luckily, PCBWay's sourcing team was able to step in and secure the necessary parts for me.
  - It was a huge relief to have that support, as it allowed me to focus on other aspects like firmware design/development and getting the initial version of documentation (including this post!) done instead of spending time sourcing every single component and doing a lot of logistical coordination with multiple suppliers for consignment!

So!
A few days ago, I sent off the first batch of prototype PCBs to PCBWay for manufacturing and assembly.

Expect a follow up work log once they arrive and I have a chance to assemble and test the first prototypes.

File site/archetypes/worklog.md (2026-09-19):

{{- $bundle := path.Base (path.Dir .File.Path) -}}
{{- $date := .File.Path | replaceRE `^worklogs/([0-9]{4})/([0-9]{2})/([0-9]{2}) - .*/index\.md$` `${1}-${2}-${3}` -}}
---
title: '{{ $bundle | replaceRE `^[0-9]{2} - ` "" | replaceRE `'` `''` }}'
date: {{ $date }}
description: ""
tags: []
slug: '{{ $bundle | replaceRE ` - ` "-" | urlize }}'
draft: true
resources: []
---

Write the concise project update here.

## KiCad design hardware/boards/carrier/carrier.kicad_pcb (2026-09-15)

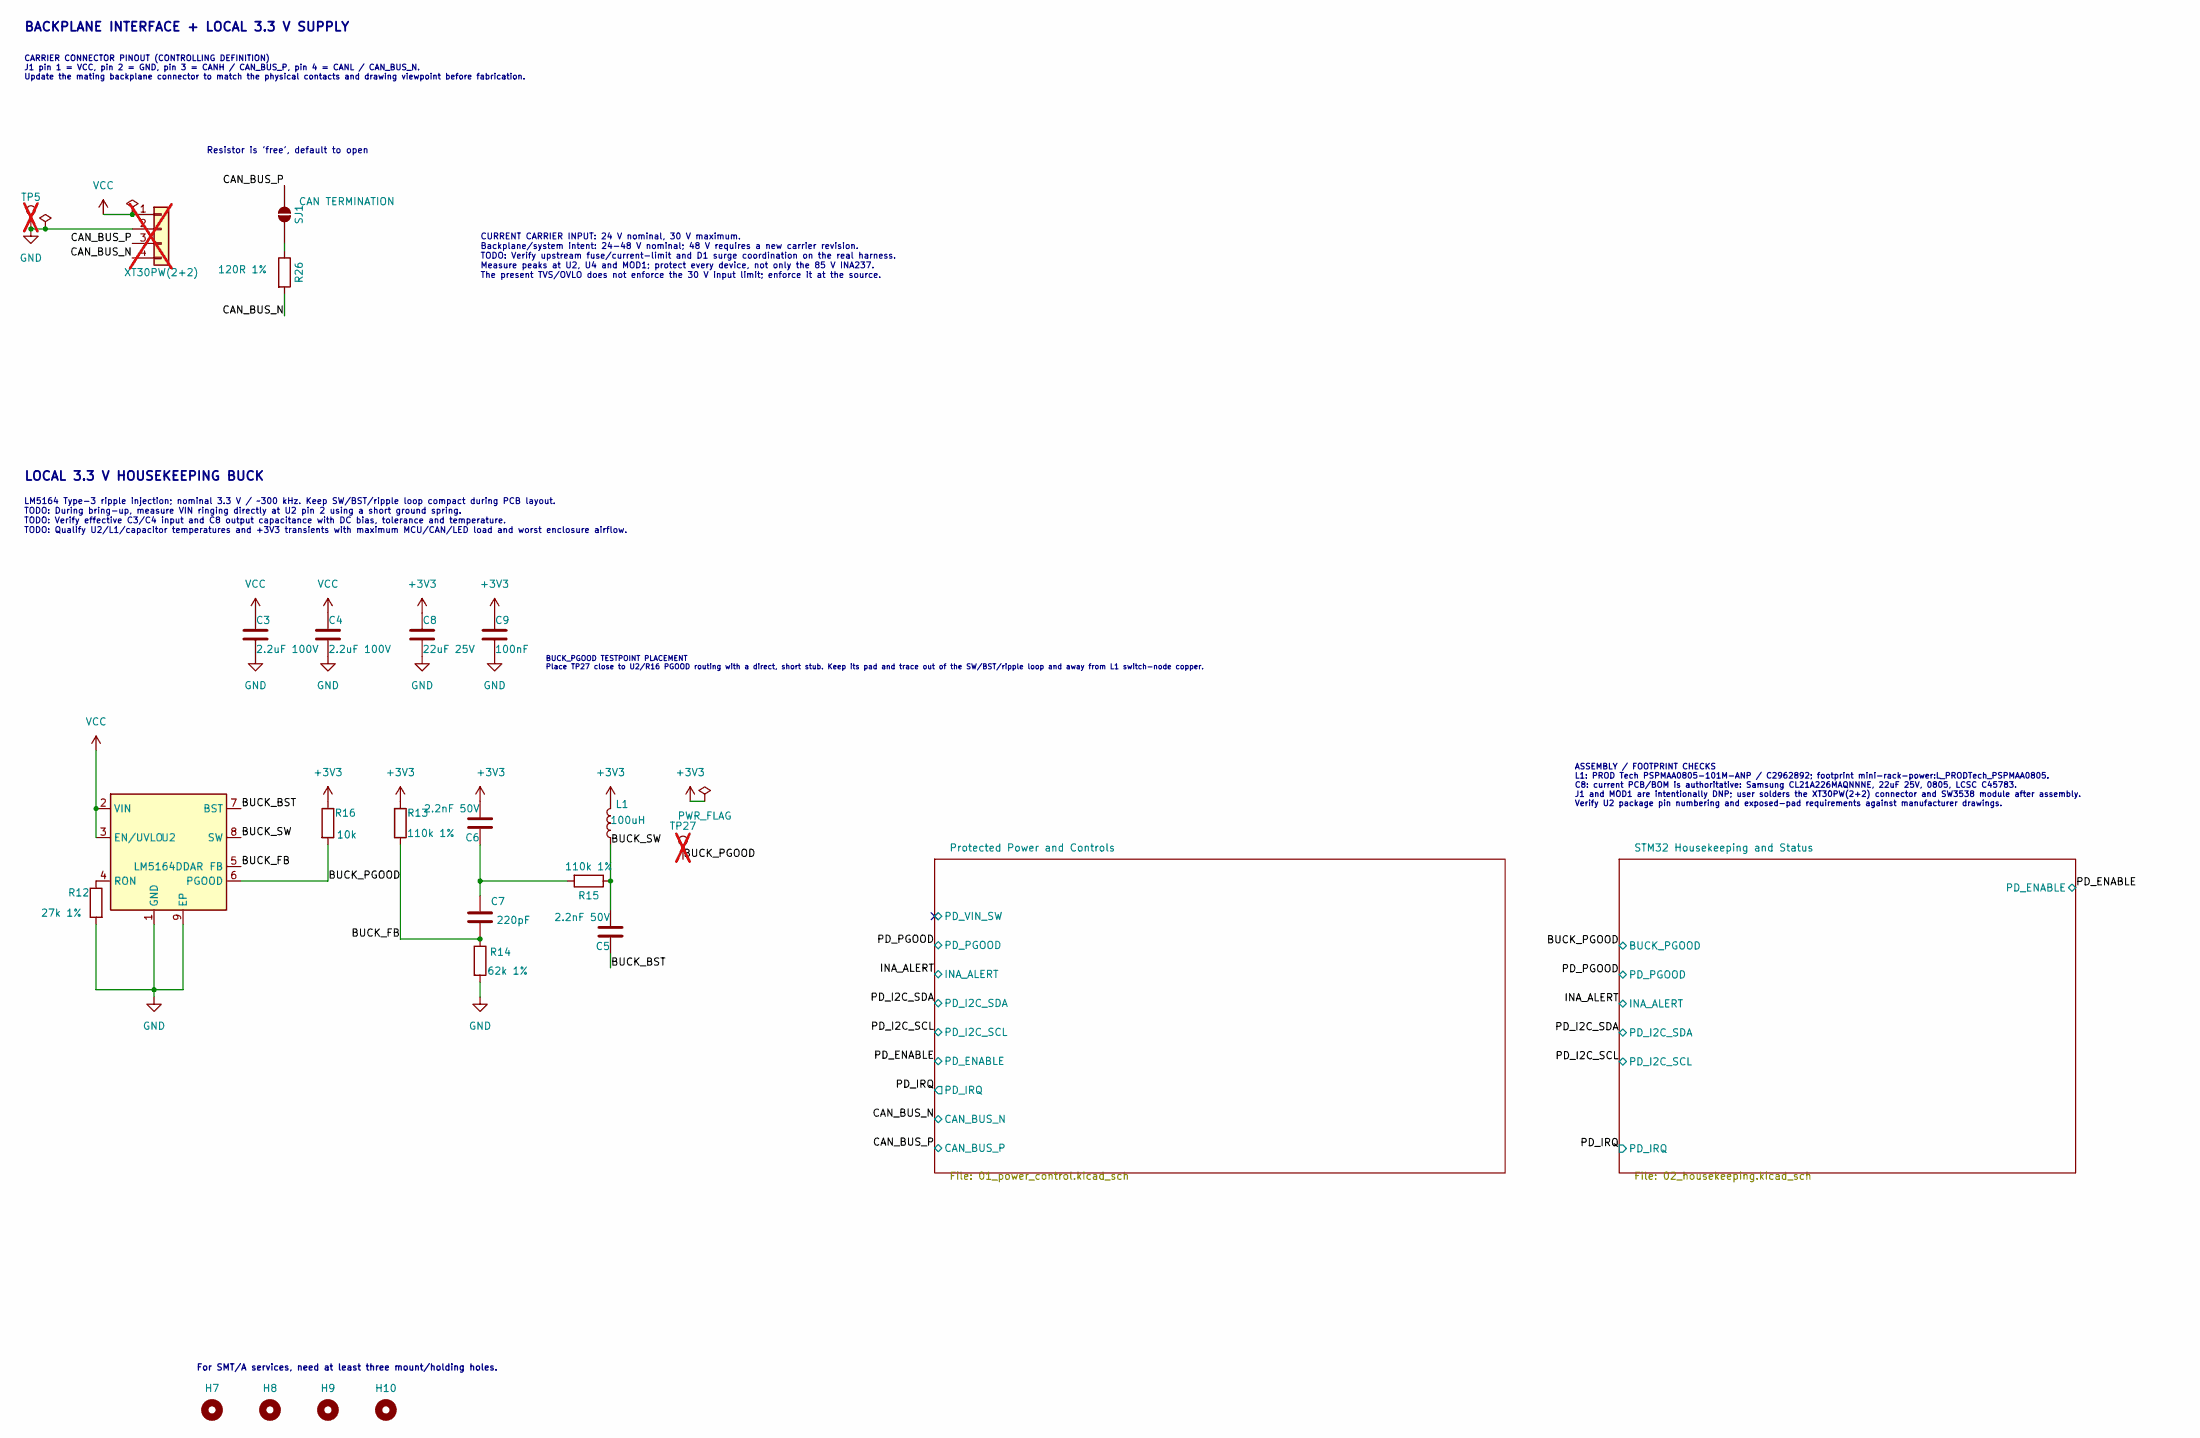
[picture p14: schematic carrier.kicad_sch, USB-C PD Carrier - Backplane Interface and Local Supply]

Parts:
C3, C4: 2.2uF 100V; C_1210_3225Metric; MPN CL32B225KCJSNNE; LCSC C55151
C5, C6: 2.2nF 50V; C_0603_1608Metric; MPN 0603B222K500NT; LCSC C1604
C7: 220pF; C_0603_1608Metric; MPN CC0603JRNPO9BN221; LCSC C106210
C8: 22uF 25V; C_0805_2012Metric; MPN CL21A226MAQNNNE; LCSC C45783
C9: 100nF; C_0603_1608Metric; MPN CC0603KRX7R9BB104; LCSC C14663
H7, H8, H9, H10: ToolingHole_1.152mm; MountingHole_JLCPCB_Tooling_1.152mm
J1: XT30PW(2+2); Amass_XT30PW_2plus2_M_RightAngle_THT; MPN XT30PW(2+2)-M.G.B; LCSC C19268030; not fitted
L1: 100uH; L_PRODTech_PSPMAA0805; MPN PSPMAA0805-101M-ANP; LCSC C2962892
R12: 27k 1%; R_0603_1608Metric; MPN 0603WAF2702T5E; LCSC C22967
R13, R15: 110k 1%; R_0603_1608Metric; MPN 0603WAF1103T5E; LCSC C25805
R14: 62k 1%; R_0603_1608Metric; MPN 0603WAF6202T5E; LCSC C23221
R16: 10k; R_0603_1608Metric; MPN 0603WAF1002T5E; LCSC C25804
R26: 120R 1%; R_0603_1608Metric; MPN 0603WAF1200T5E; LCSC C22787
SJ1: CAN TERMINATION; SolderJumper-2_P1.3mm_Open_Pad1.0x1.5mm; MPN PCB feature
TP5: GND; TestPoint_Pad_D1.0mm; not fitted
TP27: BUCK_PGOOD; TestPoint_Pad_D1.5mm; MPN PCB test point; not fitted
U2: LM5164DDAR; TI_SO-PowerPAD-8; MPN LM5164DDAR; LCSC C477928

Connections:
+3V3: C6.2, C8.1, C9.1, L1.2, R13.1, R16.1; also elsewhere on the board
/BUCK_BST: C5.1, U2.7 (BST)
/BUCK_FB: C7.2, R13.2, R14.1, U2.5 (FB)
/BUCK_PGOOD: R16.2, TP27.1 (1_1), U2.6 (PGOOD); also elsewhere on the board
/BUCK_SW: C5.2, L1.1, R15.1, U2.8 (SW)
/CAN_BUS_N: J1.4, R26.2; also elsewhere on the board
/CAN_BUS_P: J1.3, SJ1.1 (A); also elsewhere on the board
GND: C3.2, C4.2, C8.2, C9.2, J1.2, R12.2, R14.2, TP5.1 (1_1), U2.1 (GND), U2.9 (EP); also elsewhere on the board
unnamed: C6.1, C7.1, R15.2
unnamed: R26.1, SJ1.2 (B)
unnamed: R12.1, U2.4 (RON)
VCC: C3.1, C4.1, J1.1, U2.2 (VIN), U2.3 (EN/UVLO); also elsewhere on the board

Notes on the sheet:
CURRENT CARRIER INPUT: 24 V nominal, 30 V maximum. Backplane/system intent: 24-48 V nominal; 48 V requires a new carrier revision. TODO: Verify upstream fuse/current-limit and D1 surge coordination on the real harness. Measure peaks at U2, U4 and MOD1; protect every device, not only the 85 V INA237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
LOCAL 3.3 V HOUSEKEEPING BUCK
ASSEMBLY / FOOTPRINT CHECKS L1: PROD Tech PSPMAA0805-101M-ANP / C2962892; footprint mini-rack-power:L_PRODTech_PSPMAA0805. C8: current PCB/BOM is authoritative: Samsung CL21A226MAQNNNE, 22uF 25V, 0805, LCSC C45783. J1 and MOD1 are intentionally DNP; user solders the XT30PW(2+2) connector and SW3538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
Resistor is 'free', default to open
LM5164 Type-3 ripple injection; nominal 3.3 V / ~300 kHz. Keep SW/BST/ripple loop compact during PCB layout. TODO: During bring-up, measure VIN ringing directly at U2 pin 2 using a short ground spring. TODO: Verify effective C3/C4 input and C8 output capacitance with DC bias, tolerance and temperat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
BUCK_PGOOD TESTPOINT PLACEMENT Place TP27 close to U2/R16 PGOOD routing with a direct, short stub. Keep its pad and trace out of the SW/BST/ripple loop and away from L1 switch-node copper.
For SMT/A services, need at least three mount/holding holes.
CARRIER CONNECTOR PINOUT (CONTROLLING DEFINITION) J1 pin 1 = VCC, pin 2 = GND, pin 3 = CANH / CAN_BUS_P, pin 4 = CANL / CAN_BUS_N. Update the mating backplane connector to match the physical contacts and drawing viewpoint before fabrication.
BACKPLANE INTERFACE + LOCAL 3.3 V SUPPLY

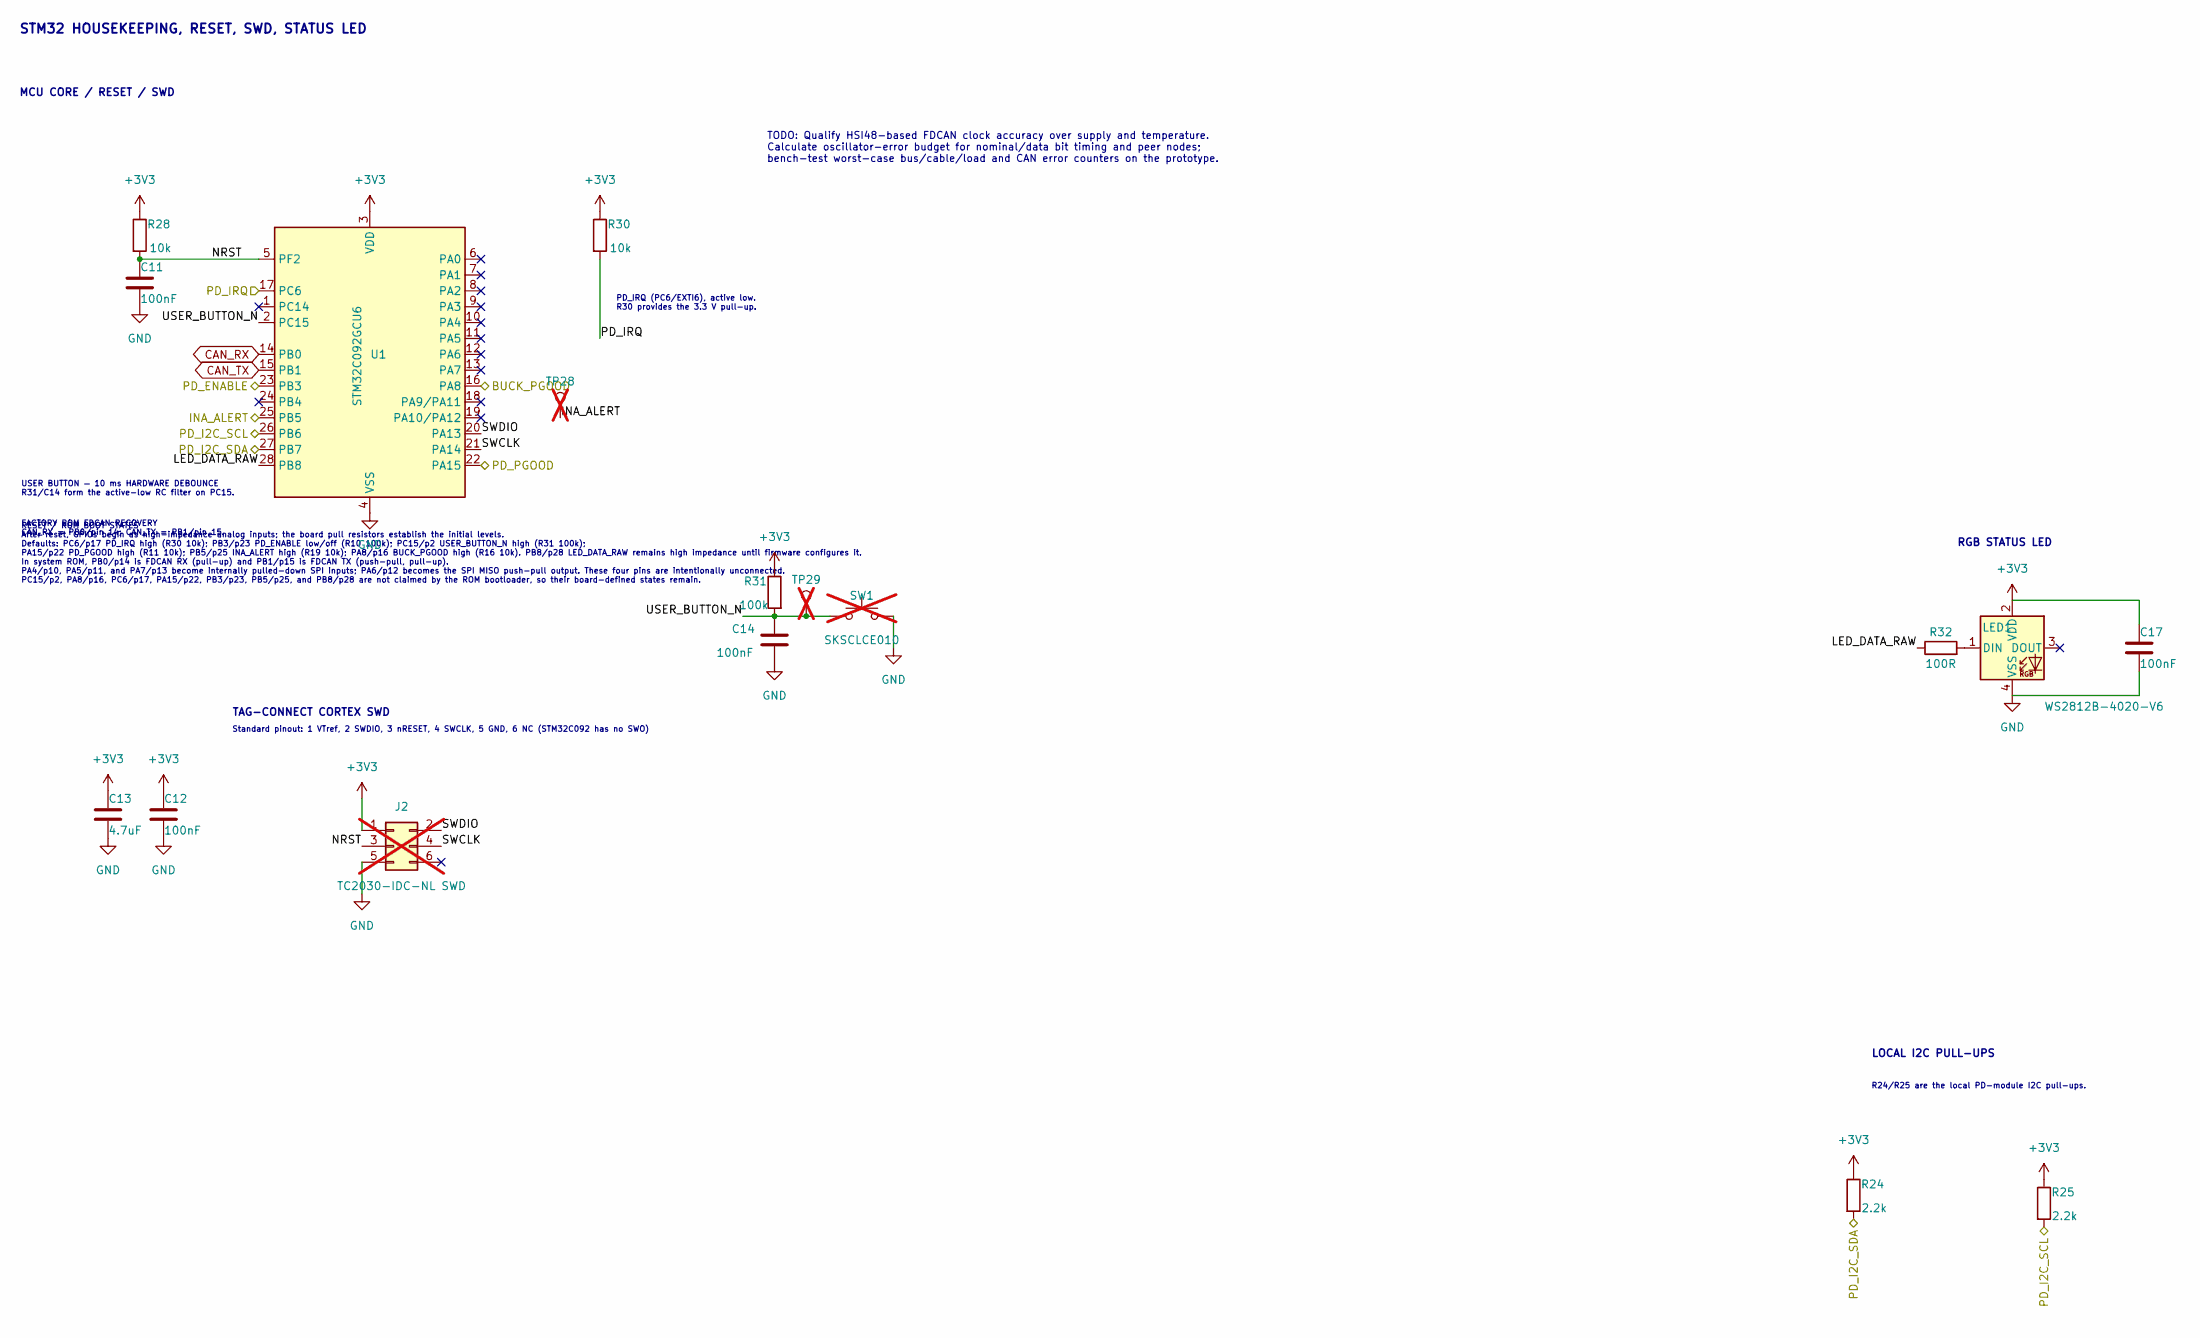
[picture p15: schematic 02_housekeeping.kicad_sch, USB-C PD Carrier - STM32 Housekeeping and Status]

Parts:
C11, C12, C14, C17: 100nF; C_0603_1608Metric; MPN CC0603KRX7R9BB104; LCSC C14663
C13: 4.7uF; C_0603_1608Metric; MPN CL10A475KO8NNNC; LCSC C19666
J2: TC2030-IDC-NL SWD; Tag-Connect_TC2030-IDC-NL_2x03_P1.27mm_Vertical; MPN TC2030-IDC-NL; not fitted
LED1: WS2812B-4020-V6; LED_Worldsemi_WS2812B-4020-V6_SideView; MPN WS2812B-4020-V6; LCSC C52941387
R24, R25: 2.2k; R_0603_1608Metric; MPN 0603WAF2201T5E; LCSC C4190
R28, R30: 10k; R_0603_1608Metric; MPN 0603WAF1002T5E; LCSC C25804
R31: 100k; R_0603_1608Metric; MPN 0603WAF1003T5E; LCSC C25803
R32: 100R; R_0603_1608Metric; MPN 0603WAF1000T5E; LCSC C22775
SW1: SKSCLCE010; SW_ALPS_SKSCLCE010_SidePush; MPN SKSCLCE010; LCSC C139799; not fitted
TP28: INA_ALERT; TestPoint_Pad_D1.5mm; MPN PCB test point; not fitted
TP29: USER_BUTTON_N; TestPoint_Pad_D1.5mm; MPN PCB test point; not fitted
U1: STM32C092GCU6; QFN-28_4x4mm_P0.5mm; MPN STM32C092GCU6; LCSC C44847705

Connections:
+3V3: C12.1, C13.1, C17.1, J2.1, LED1.2 (VDD), R24.1, R25.1, R28.1, R30.1, R31.1, U1.3 (VDD); also elsewhere on the board
/BUCK_PGOOD: U1.16 (PA8); also elsewhere on the board
/INA_ALERT: TP28.1 (1_1), U1.25 (PB5); also elsewhere on the board
/PD_ENABLE: U1.23 (PB3); also elsewhere on the board
/PD_I2C_SCL: R25.2, U1.26 (PB6); also elsewhere on the board
/PD_I2C_SDA: R24.2, U1.27 (PB7); also elsewhere on the board
/PD_IRQ: R30.2, U1.17 (PC6); also elsewhere on the board
/PD_PGOOD: U1.22 (PA15); also elsewhere on the board
/STM32 Housekeeping and Status/LED_DATA_RAW: R32.1, U1.28 (PB8)
/STM32 Housekeeping and Status/NRST: C11.1, J2.3, R28.2, U1.5 (PF2)
/STM32 Housekeeping and Status/SWCLK: J2.4, U1.21 (PA14)
/STM32 Housekeeping and Status/SWDIO: J2.2, U1.20 (PA13)
/STM32 Housekeeping and Status/USER_BUTTON_N: C14.1, R31.2, SW1.2, TP29.1 (1_1), U1.2 (PC15)
CAN_RX: U1.14 (PB0); also elsewhere on the board
CAN_TX: U1.15 (PB1); also elsewhere on the board
GND: C11.2, C12.2, C13.2, C14.2, C17.2, J2.5, LED1.4 (VSS), SW1.1, U1.4 (VSS); also elsewhere on the board
unnamed: LED1.1 (DIN), R32.2

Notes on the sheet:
Standard pinout: 1 VTref, 2 SWDIO, 3 nRESET, 4 SWCLK, 5 GND, 6 NC (STM32C092 has no SWO)
FACTORY ROM FDCAN RECOVERY CAN_RX = PB0/pin 14; CAN_TX = PB1/pin 15.
LOCAL I2C PULL-UPS
USER BUTTON — 10 ms HARDWARE DEBOUNCE R31/C14 form the active-low RC filter on PC15.
R24/R25 are the local PD-module I2C pull-ups.
TAG-CONNECT CORTEX SWD
TODO: Qualify HSI48-based FDCAN clock accuracy over supply and temperature. Calculate oscillator-error budget for nominal/data bit timing and peer nodes; bench-test worst-case bus/cable/load and CAN error counters on the prototype.
MCU CORE / RESET / SWD
STM32 HOUSEKEEPING, RESET, SWD, STATUS LED
PD_IRQ (PC6/EXTI6), active low. R30 provides the 3.3 V pull-up.
RESET / ROM BOOT STATES After reset, GPIOs begin as high-impedance analog inputs; the board pull resistors establish the initial levels. Defaults: PC6/p17 PD_IRQ high (R30 10k); PB3/p23 PD_ENABLE low/off (R10 100k); PC15/p2 USER_BUTTON_N high (R31 100k); PA15/p22 PD_PGOOD high (R11 10k); PB5/p25 IN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
RGB STATUS LED

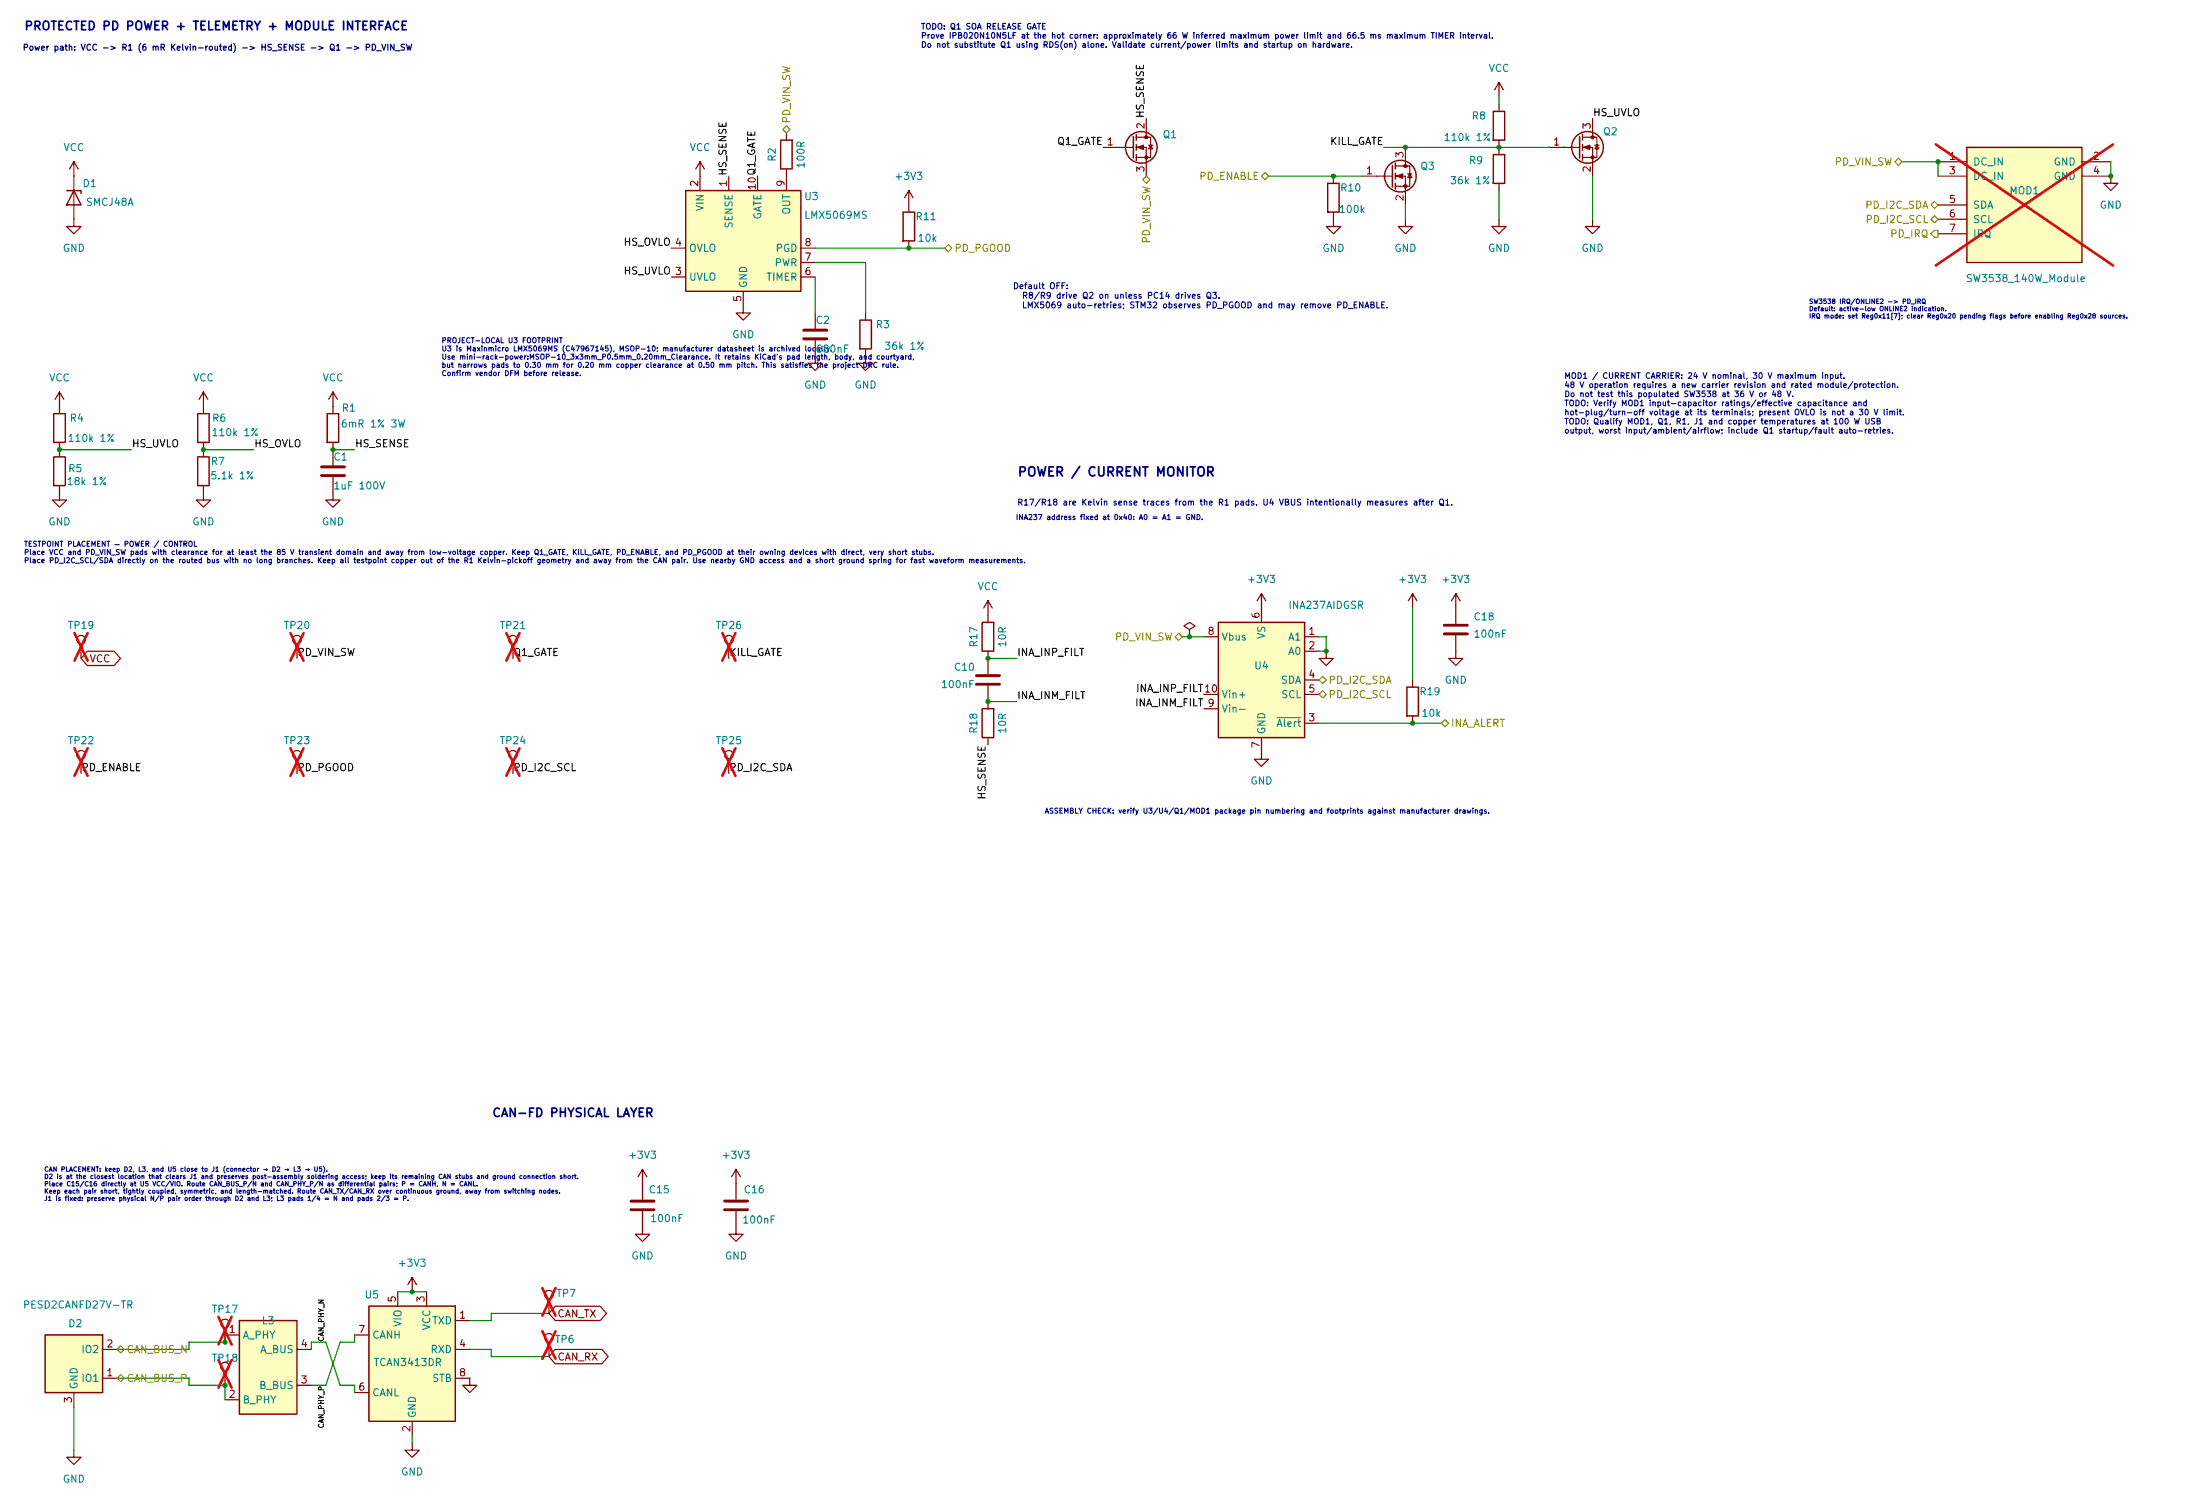
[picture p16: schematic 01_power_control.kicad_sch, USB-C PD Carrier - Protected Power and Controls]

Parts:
C1: 1uF 100V; C_1206_3216Metric; MPN CL31B105KCHNNNE; LCSC C13832
C2: 680nF; C_0603_1608Metric; MPN 0603B684K160NT; LCSC C24797
C10, C15, C16, C18: 100nF; C_0603_1608Metric; MPN CC0603KRX7R9BB104; LCSC C14663
D1: SMCJ48A; D_SMC_Silk0.15mm; MPN SMCJ48A; LCSC C19077611
D2: PESD2CANFD27V-TR; SOT-23; MPN PESD2CANFD27V-TR; LCSC C552488
L3: ACT1210D-101-2P-TL00; L_CommonModeChoke_TDK_ACT1210D; MPN ACT1210D-101-2P-TL00; LCSC C3039743
MOD1: SW3538_140W_Module; not fitted
Q1: IPB020N10N5LF; TO-263-3_TabPin2; MPN IPB020N10N5LF; LCSC C536484
Q2, Q3: 2N7002; SOT-23; MPN 2N7002; LCSC C8545
R1: 6mR 1% 3W; R_2512_6332Metric; MPN HoLLR2512-3W-6mR-1%; LCSC C2985709
R2: 100R; R_0603_1608Metric; MPN 0603WAF1000T5E; LCSC C22775
R3, R9: 36k 1%; R_0603_1608Metric; MPN 0603WAF3602T5E; LCSC C23147
R4, R6, R8: 110k 1%; R_0603_1608Metric; MPN 0603WAF1103T5E; LCSC C25805
R5: 18k 1%; R_0603_1608Metric; MPN 0603WAF1802T5E; LCSC C25810
R7: 5.1k 1%; R_0603_1608Metric; MPN 0603WAF5101T5E; LCSC C23186
R10: 100k; R_0603_1608Metric; MPN 0603WAF1003T5E; LCSC C25803
R11, R19: 10k; R_0603_1608Metric; MPN 0603WAF1002T5E; LCSC C25804
R17, R18: 10R; R_0603_1608Metric; MPN 0603WAF100JT5E; LCSC C22859
TP6: CAN_RX; TestPoint_Pad_D1.5mm; MPN PCB test point; not fitted
TP7: CAN_TX; TestPoint_Pad_D1.5mm; MPN PCB test point; not fitted
TP17: CAN_BUS_N; TestPoint_Pad_D1.5mm; MPN PCB test point; not fitted
TP18: CAN_BUS_P; TestPoint_Pad_D1.5mm; MPN PCB test point; not fitted
TP19: VCC; TestPoint_Pad_D1.5mm; MPN PCB test point; not fitted
TP20: PD_VIN_SW; TestPoint_Pad_D1.5mm; MPN PCB test point; not fitted
TP21: Q1_GATE; TestPoint_Pad_D1.5mm; MPN PCB test point; not fitted
TP22: PD_ENABLE; TestPoint_Pad_D1.5mm; MPN PCB test point; not fitted
TP23: PD_PGOOD; TestPoint_Pad_D1.5mm; MPN PCB test point; not fitted
TP24: PD_I2C_SCL; TestPoint_Pad_D1.5mm; MPN PCB test point; not fitted
TP25: PD_I2C_SDA; TestPoint_Pad_D1.5mm; MPN PCB test point; not fitted
TP26: KILL_GATE; TestPoint_Pad_D1.5mm; MPN PCB test point; not fitted
U3: LMX5069MS; MSOP-10_3x3mm_P0.5mm_0.20mm_Clearance; MPN LMX5069MS; LCSC C47967145
U4: INA237AIDGSR; TSSOP-10_3x3mm_P0.5mm; MPN INA237AIDGSR; LCSC C2864837
U5: TCAN3413DR; SOIC-8_3.9x4.9mm_P1.27mm; MPN TCAN3413DR; LCSC C22433320

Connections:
+3V3: C15.1, C16.1, C18.1, R11.1, R19.1, U4.6 (VS), U5.3 (VCC), U5.5 (VIO); also elsewhere on the board
/CAN_BUS_N: D2.2 (IO2), L3.1 (A_PHY), TP17.1 (1_1); also elsewhere on the board
/CAN_BUS_P: D2.1 (IO1), L3.2 (B_PHY), TP18.1 (1_1); also elsewhere on the board
/INA_ALERT: R19.2, U4.3 (~Alert); also elsewhere on the board
/PD_ENABLE: Q3.1 (G), R10.1, TP22.1 (1_1); also elsewhere on the board
/PD_I2C_SCL: MOD1.6 (SCL), TP24.1 (1_1), U4.5 (SCL); also elsewhere on the board
/PD_I2C_SDA: MOD1.5 (SDA), TP25.1 (1_1), U4.4 (SDA); also elsewhere on the board
/PD_IRQ: MOD1.7 (IRQ); also elsewhere on the board
/PD_PGOOD: R11.2, TP23.1 (1_1), U3.8 (PGD); also elsewhere on the board
/Protected Power and Controls/CAN_PHY_N: L3.4 (A_BUS), U5.6 (CANL)
/Protected Power and Controls/CAN_PHY_P: L3.3 (B_BUS), U5.7 (CANH)
/Protected Power and Controls/HS_OVLO: R6.2, R7.1, U3.4 (OVLO)
/Protected Power and Controls/HS_SENSE: C1.1, Q1.2 (D), R1.2, R18.1, U3.1 (SENSE)
/Protected Power and Controls/HS_UVLO: Q2.3 (D), R4.2, R5.1, U3.3 (UVLO)
/Protected Power and Controls/INA_INM_FILT: C10.2, R18.2, U4.9 (Vin-)
/Protected Power and Controls/INA_INP_FILT: C10.1, R17.1, U4.10 (Vin+)
/Protected Power and Controls/KILL_GATE: Q2.1 (G), Q3.3 (D), R8.2, R9.1, TP26.1 (1_1)
/Protected Power and Controls/PD_VIN_SW: MOD1.1 (DC_IN), MOD1.3 (DC_IN), Q1.3 (S), R2.2, TP20.1 (1_1), U4.8 (Vbus)
/Protected Power and Controls/Q1_GATE: Q1.1 (G), TP21.1 (1_1), U3.10 (GATE)
CAN_RX: TP6.1 (1_1), U5.4 (RXD); also elsewhere on the board
CAN_TX: TP7.1 (1_1), U5.1 (TXD); also elsewhere on the board
GND: C1.2, C2.2, C15.2, C16.2, C18.2, D1.2 (A), D2.3 (GND), MOD1.2 (GND), MOD1.4 (GND), Q2.2 (S), Q3.2 (S), R3.2, R5.2, R7.2, R9.2, R10.2, U3.5 (GND), U4.1 (A1), U4.2 (A0), U4.7 (GND), U5.2 (GND), U5.8 (STB); also elsewhere on the board
unnamed: R2.1, U3.9 (OUT)
unnamed: R3.1, U3.7 (PWR)
unnamed: C2.1, U3.6 (TIMER)
VCC: D1.1 (K), R1.1, R4.1, R6.1, R8.1, R17.2, TP19.1 (1_1), U3.2 (VIN); also elsewhere on the board

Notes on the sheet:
MOD1 / CURRENT CARRIER: 24 V nominal, 30 V maximum input. 48 V operation requires a new carrier revision and rated module/protection. Do not test this populated SW3538 at 36 V or 48 V. TODO: Verify MOD1 input-capacitor ratings/effective capacitance and hot-plug/turn-off voltage at its terminals; pr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
PROTECTED PD POWER + TELEMETRY + MODULE INTERFACE
INA237 address fixed at 0x40: A0 = A1 = GND.
TODO: Q1 SOA RELEASE GATE Prove IPB020N10N5LF at the hot corner: approximately 66 W inferred maximum power limit and 66.5 ms maximum TIMER interval. Do not substitute Q1 using RDS(on) alone. Validate current/power limits and startup on hardware.
R17/R18 are Kelvin sense traces from the R1 pads. U4 VBUS intentionally measures after Q1.
TESTPOINT PLACEMENT — POWER / CONTROL Place VCC and PD_VIN_SW pads with clearance for at least the 85 V transient domain and away from low-voltage copper. Keep Q1_GATE, KILL_GATE, PD_ENABLE, and PD_PGOOD at their owning devices with direct, very short stubs. Place PD_I2C_SCL/SDA directly on the rou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
PROJECT-LOCAL U3 FOOTPRINT U3 is Maxinmicro LMX5069MS (C47967145), MSOP-10; manufacturer datasheet is archived locally. Use mini-rack-power:MSOP-10_3x3mm_P0.5mm_0.20mm_Clearance. It retains KiCad's pad length, body, and courtyard, but narrows pads to 0.30 mm for 0.20 mm copper clearance at 0.50 mm 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
Default OFF: R8/R9 drive Q2 on unless PC14 drives Q3. LMX5069 auto-retries; STM32 observes PD_PGOOD and may remove PD_ENABLE.
CAN-FD PHYSICAL LAYER
CAN PLACEMENT: keep D2, L3, and U5 close to J1 (connector → D2 → L3 → U5). D2 is at the closest location that clears J1 and preserves post-assembly soldering access; keep its remaining CAN stubs and ground connection short. Place C15/C16 directly at U5 VCC/VIO. Route CAN_BUS_P/N and CAN_PHY_P/N as 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
SW3538 IRQ/ONLINE2 -> PD_IRQ Default: active-low ONLINE2 indication. IRQ mode: set Reg0x11[7]; clear Reg0x20 pending flags before enabling Reg0x28 sources.
ASSEMBLY CHECK: verify U3/U4/Q1/MOD1 package pin numbering and footprints against manufacturer drawings.
Power path: VCC -> R1 (6 mR Kelvin-routed) -> HS_SENSE -> Q1 -> PD_VIN_SW
POWER / CURRENT MONITOR

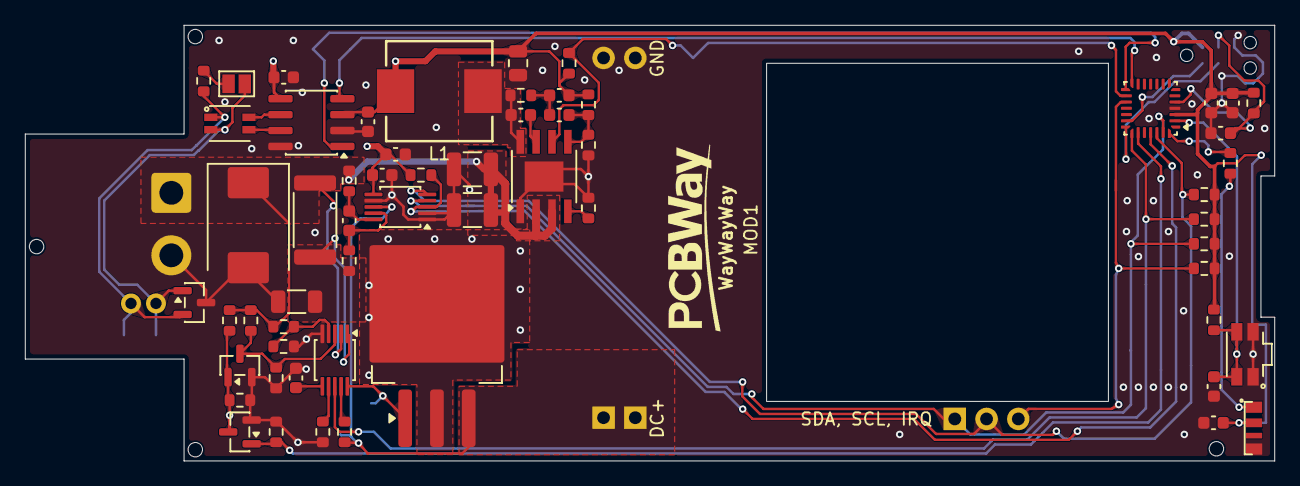
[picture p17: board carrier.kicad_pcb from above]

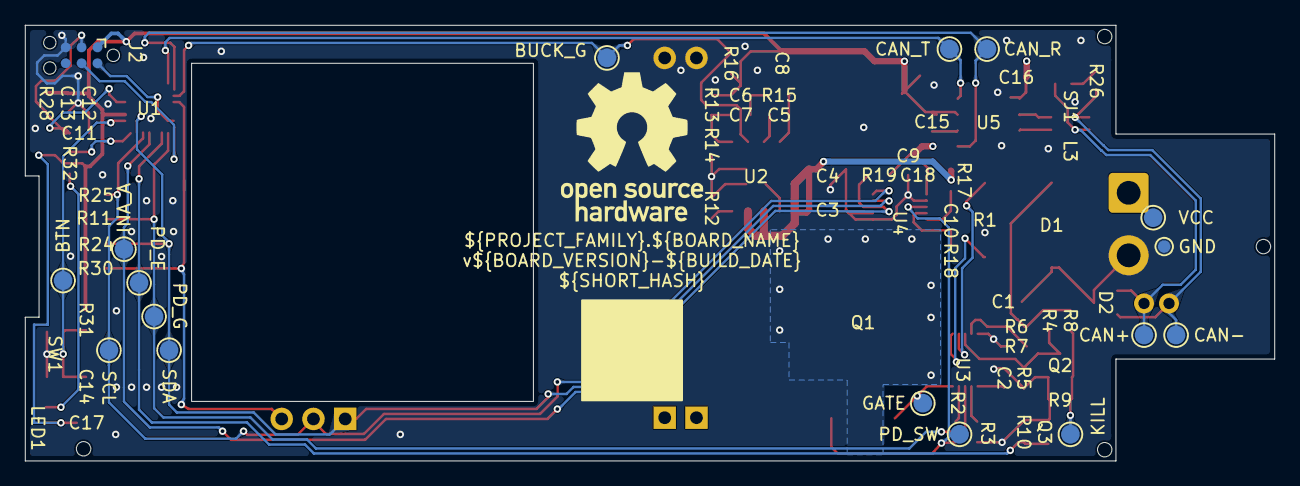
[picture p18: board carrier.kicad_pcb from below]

Board: 4 copper layers, 100.0 x 34.9 mm, 83 parts (17 on the bottom side), 39 nets.

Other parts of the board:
LOGO_PCBWAY: PCBWay_Logo_15mm

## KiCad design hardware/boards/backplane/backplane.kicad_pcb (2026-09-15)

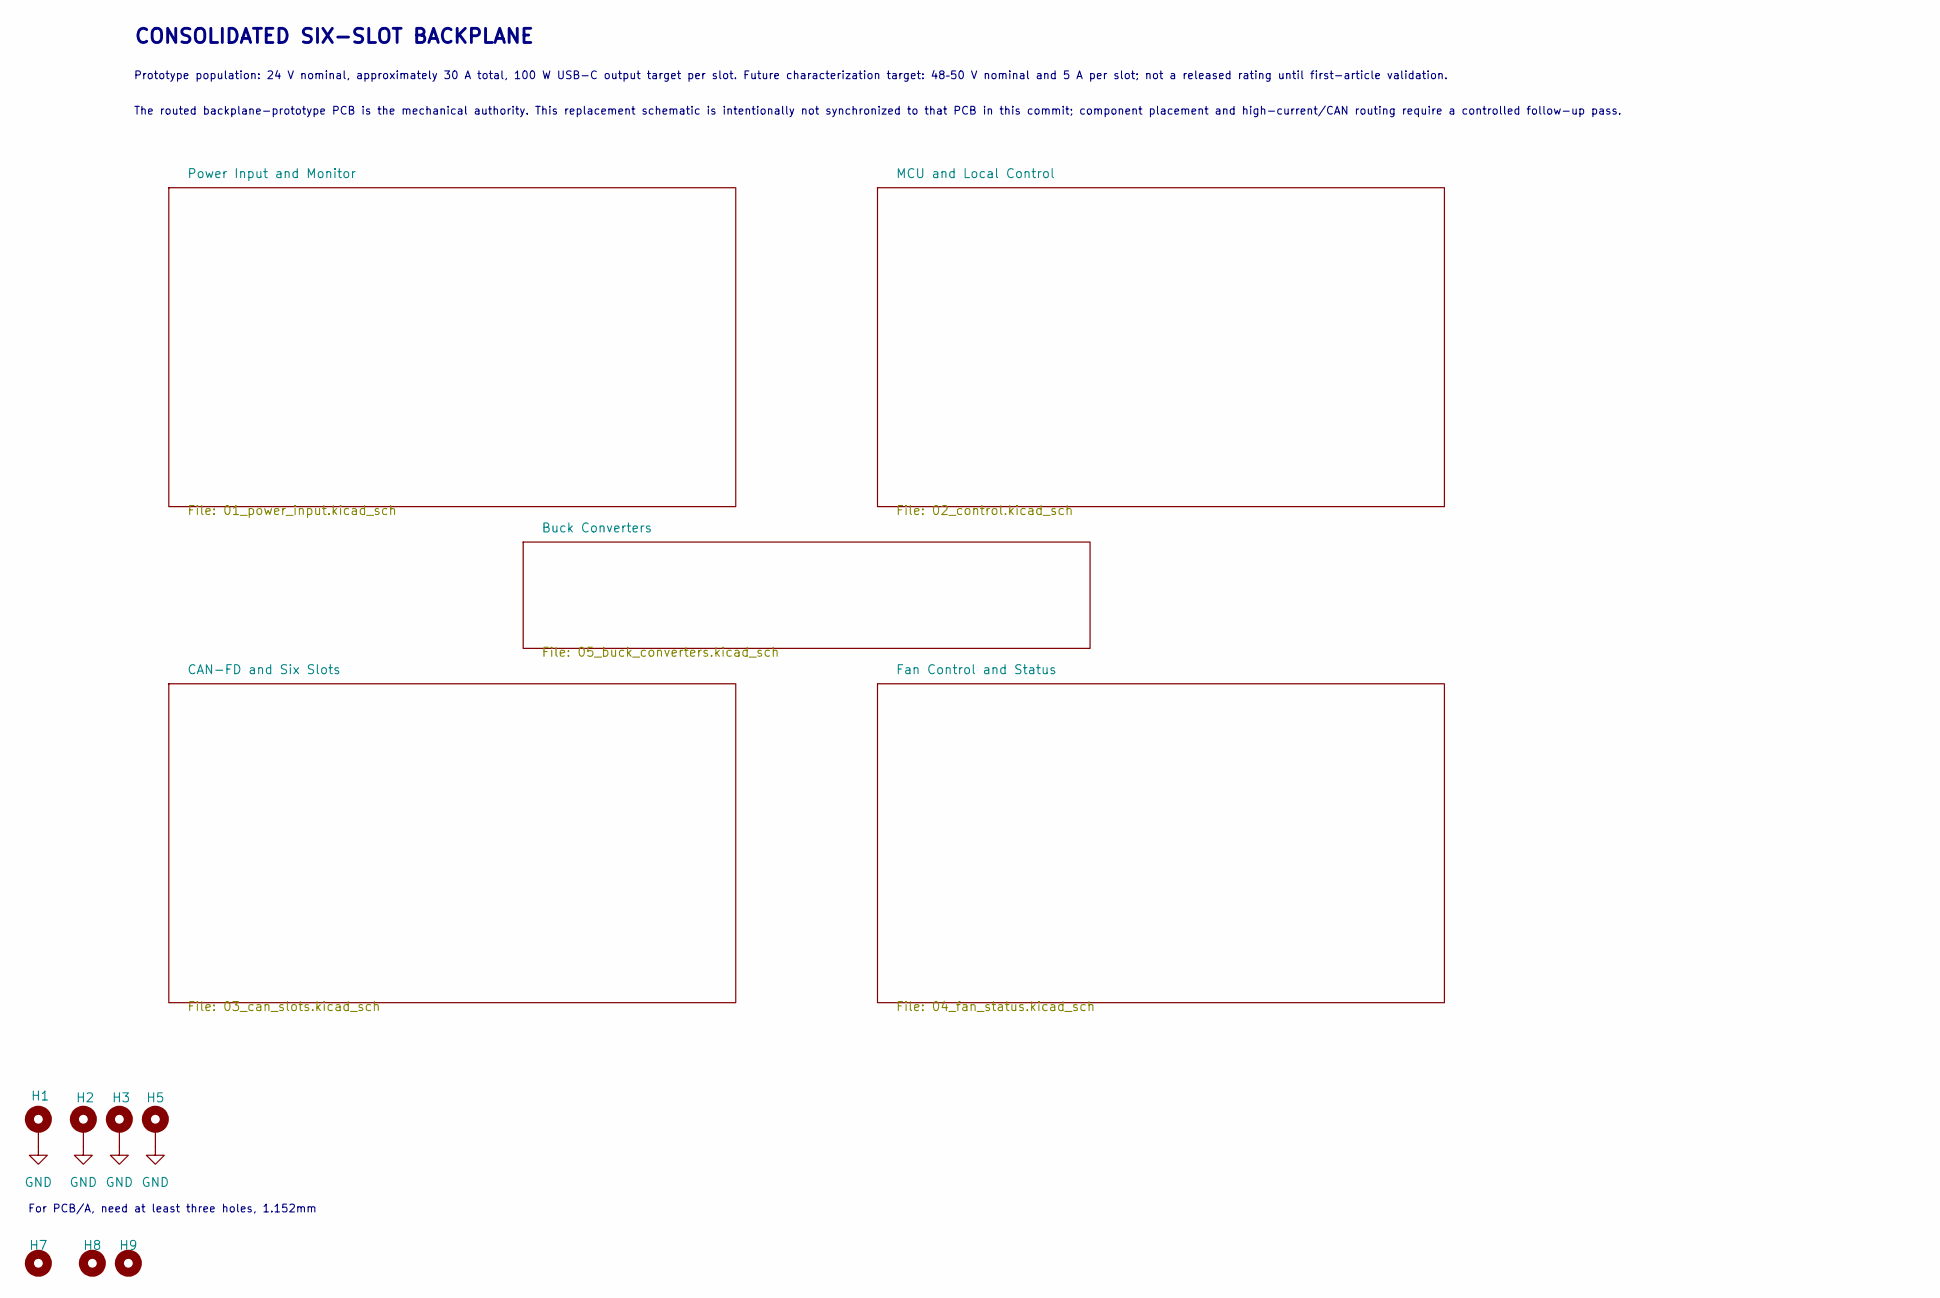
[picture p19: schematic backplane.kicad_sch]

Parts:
H1, H2, H3, H5: M2 CHASSIS; MountingHole_2.2mm_M2_Pad_Via_JLC
H7, H8, H9: ToolingHole_1.152mm; MountingHole_JLCPCB_Tooling_1.152mm

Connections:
GND: H1.1 (1_1), H2.1 (1_1), H3.1 (1_1), H5.1 (1_1); also elsewhere on the board

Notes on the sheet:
The routed backplane-prototype PCB is the mechanical authority. This replacement schematic is intentionally not synchronized to that PCB in this commit; component placement and high-current/CAN routing require a controlled follow-up pass.
Prototype population: 24 V nominal, approximately 30 A total, 100 W USB-C output target per slot. Future characterization target: 48–50 V nominal and 5 A per slot; not a released rating until first-article validation.
CONSOLIDATED SIX-SLOT BACKPLANE
For PCB/A, need at least three holes, 1.152mm

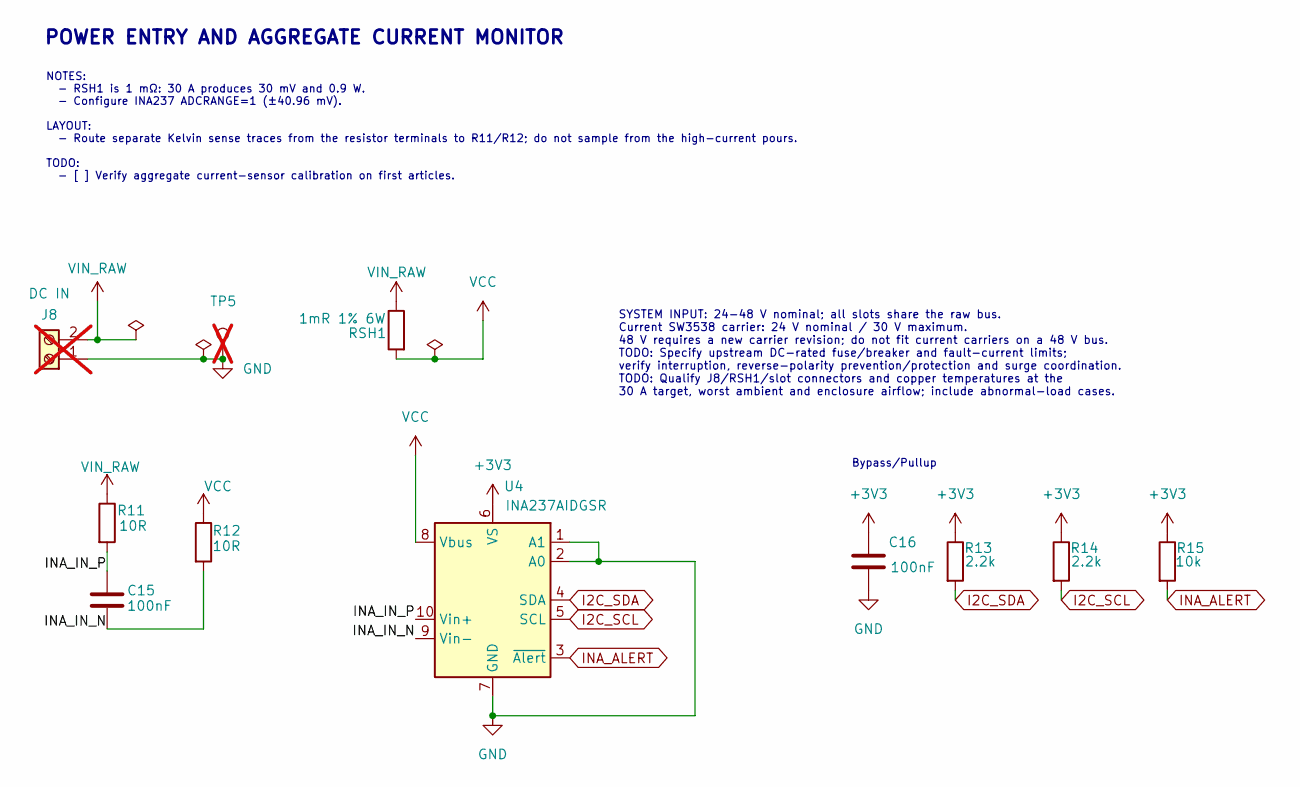
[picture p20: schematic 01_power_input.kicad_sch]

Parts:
C15, C16: 100nF; C_0603_1608Metric; Voltage 50 V; MPN CC0603KRX7R9BB104; LCSC C14663
J8: DC IN; DORABO_DB910-6.35-2P-GN-S; MPN DB910-6.35-2P-GN-S; LCSC C395872; not fitted
R11, R12: 10R; R_0603_1608Metric; Tolerance 1%; MPN 0603WAF100JT5E; LCSC C22859
R13, R14: 2.2k; R_0603_1608Metric; Tolerance 1%; MPN 0603WAF2201T5E; LCSC C4190
R15: 10k; R_0603_1608Metric; Tolerance 1%; MPN 0603WAF1002T5E; LCSC C25804
RSH1: 1mR 1% 6W; R_2512_6332Metric; Tolerance 1%; MPN HoLSX2512-6W-1mR-1%; LCSC C19270875
TP5: GND; TestPoint_Pad_D1.5mm; not fitted
U4: INA237AIDGSR; MSOP-10_3x3mm_P0.5mm_0.20mm_Clearance; MPN INA237AIDGSR; LCSC C2864837

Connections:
+3V3: C16.1, R13.1, R14.1, R15.1, U4.6 (VS); also elsewhere on the board
/Power Input and Monitor/INA_IN_N: C15.2, R12.2, U4.9 (Vin-)
/Power Input and Monitor/INA_IN_P: C15.1, R11.2, U4.10 (Vin+)
GND: C16.2, J8.1, TP5.1 (1_1), U4.1 (A1), U4.2 (A0), U4.7 (GND); also elsewhere on the board
I2C_SCL: R14.2, U4.5 (SCL); also elsewhere on the board
I2C_SDA: R13.2, U4.4 (SDA); also elsewhere on the board
INA_ALERT: R15.2, U4.3 (~Alert); also elsewhere on the board
VCC: R12.1, RSH1.2, U4.8 (Vbus); also elsewhere on the board
VIN_RAW: J8.2, R11.1, RSH1.1

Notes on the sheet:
NOTES: - RSH1 is 1 mΩ: 30 A produces 30 mV and 0.9 W. - Configure INA237 ADCRANGE=1 (±40.96 mV). LAYOUT: - Route separate Kelvin sense traces from the resistor terminals to R11/R12; do not sample from the high-current pours. TODO: - [ ] Verify aggregate current-sensor calibration on first articles.
Bypass/Pullup
SYSTEM INPUT: 24-48 V nominal; all slots share the raw bus. Current SW3538 carrier: 24 V nominal / 30 V maximum. 48 V requires a new carrier revision; do not fit current carriers on a 48 V bus. TODO: Specify upstream DC-rated fuse/breaker and fault-current limits; verify interruption, reverse-polar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
POWER ENTRY AND AGGREGATE CURRENT MONITOR

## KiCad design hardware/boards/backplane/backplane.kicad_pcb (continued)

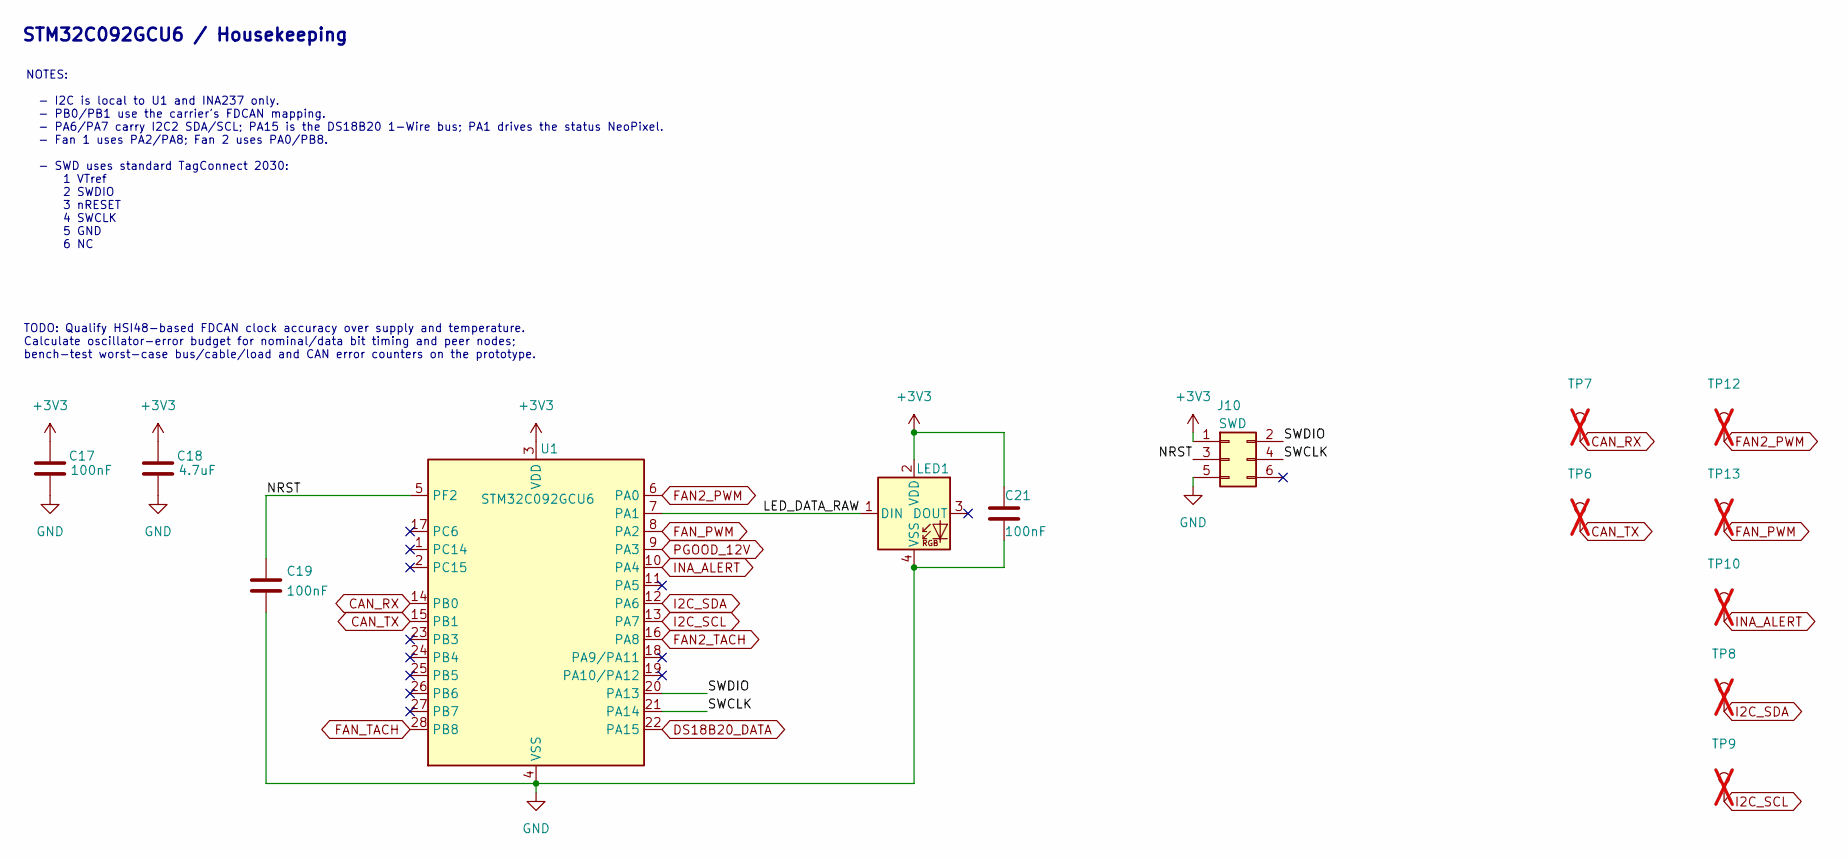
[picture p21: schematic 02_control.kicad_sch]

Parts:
C17, C19: 100nF; C_0603_1608Metric; Voltage 50 V; MPN CC0603KRX7R9BB104; LCSC C14663
C18: 4.7uF; C_0603_1608Metric; Voltage 10 V or greater; MPN CL10A475KO8NNNC; LCSC C19666
C21: 100nF; C_0603_1608Metric; MPN CC0603KRX7R9BB104; LCSC C14663
J10: SWD; Tag-Connect_TC2030-IDC-NL_2x03_P1.27mm_Vertical; MPN TC2030-IDC-NL
LED1: WS2812B-4020-V6; LED_Worldsemi_WS2812B-4020-V6_SideView; MPN WS2812B-4020-V6; LCSC C52941387
TP6: CAN_TX; TestPoint_Pad_D1.5mm; not fitted
TP7: CAN_RX; TestPoint_Pad_D1.5mm; not fitted
TP8: I2C_SDA; TestPoint_Pad_D1.5mm; not fitted
TP9: I2C_SCL; TestPoint_Pad_D1.5mm; not fitted
TP10: INA_ALERT; TestPoint_Pad_D1.5mm; not fitted
TP12, TP13: FAN_PWM; TestPoint_Pad_D1.5mm; not fitted
U1: STM32C092GCU6; QFN-28_4x4mm_P0.5mm; MPN STM32C092GCU6; LCSC C44847705

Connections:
+3V3: C17.1, C18.1, C21.1, J10.1, LED1.2 (VDD), U1.3 (VDD); also elsewhere on the board
/MCU and Local Control/LED_DATA_RAW: LED1.1 (DIN), U1.7 (PA1)
/MCU and Local Control/NRST: C19.1, J10.3, U1.5 (PF2)
/MCU and Local Control/SWCLK: J10.4, U1.21 (PA14)
/MCU and Local Control/SWDIO: J10.2, U1.20 (PA13)
CAN_RX: TP7.1 (1_1), U1.14 (PB0); also elsewhere on the board
CAN_TX: TP6.1 (1_1), U1.15 (PB1); also elsewhere on the board
DS18B20_DATA: U1.22 (PA15); also elsewhere on the board
FAN2_PWM: TP12.1 (1_1), U1.6 (PA0); also elsewhere on the board
FAN2_TACH: U1.16 (PA8); also elsewhere on the board
FAN_PWM: TP13.1 (1_1), U1.8 (PA2); also elsewhere on the board
FAN_TACH: U1.28 (PB8); also elsewhere on the board
GND: C17.2, C18.2, C19.2, C21.2, J10.5, LED1.4 (VSS), U1.4 (VSS); also elsewhere on the board
I2C_SCL: TP9.1 (1_1), U1.13 (PA7); also elsewhere on the board
I2C_SDA: TP8.1 (1_1), U1.12 (PA6); also elsewhere on the board
INA_ALERT: TP10.1 (1_1), U1.10 (PA4); also elsewhere on the board
PGOOD_12V: U1.9 (PA3); also elsewhere on the board

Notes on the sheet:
TODO: Qualify HSI48-based FDCAN clock accuracy over supply and temperature. Calculate oscillator-error budget for nominal/data bit timing and peer nodes; bench-test worst-case bus/cable/load and CAN error counters on the prototype.
STM32C092GCU6 / Housekeeping
NOTES: - I2C is local to U1 and INA237 only. - PB0/PB1 use the carrier's FDCAN mapping. - PA6/PA7 carry I2C2 SDA/SCL; PA15 is the DS18B20 1-Wire bus; PA1 drives the status NeoPixel. - Fan 1 uses PA2/PA8; Fan 2 uses PA0/PB8. - SWD uses standard TagConnect 2030: 1 VTref 2 SWDIO 3 nRESET 4 SWCLK 5 GND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

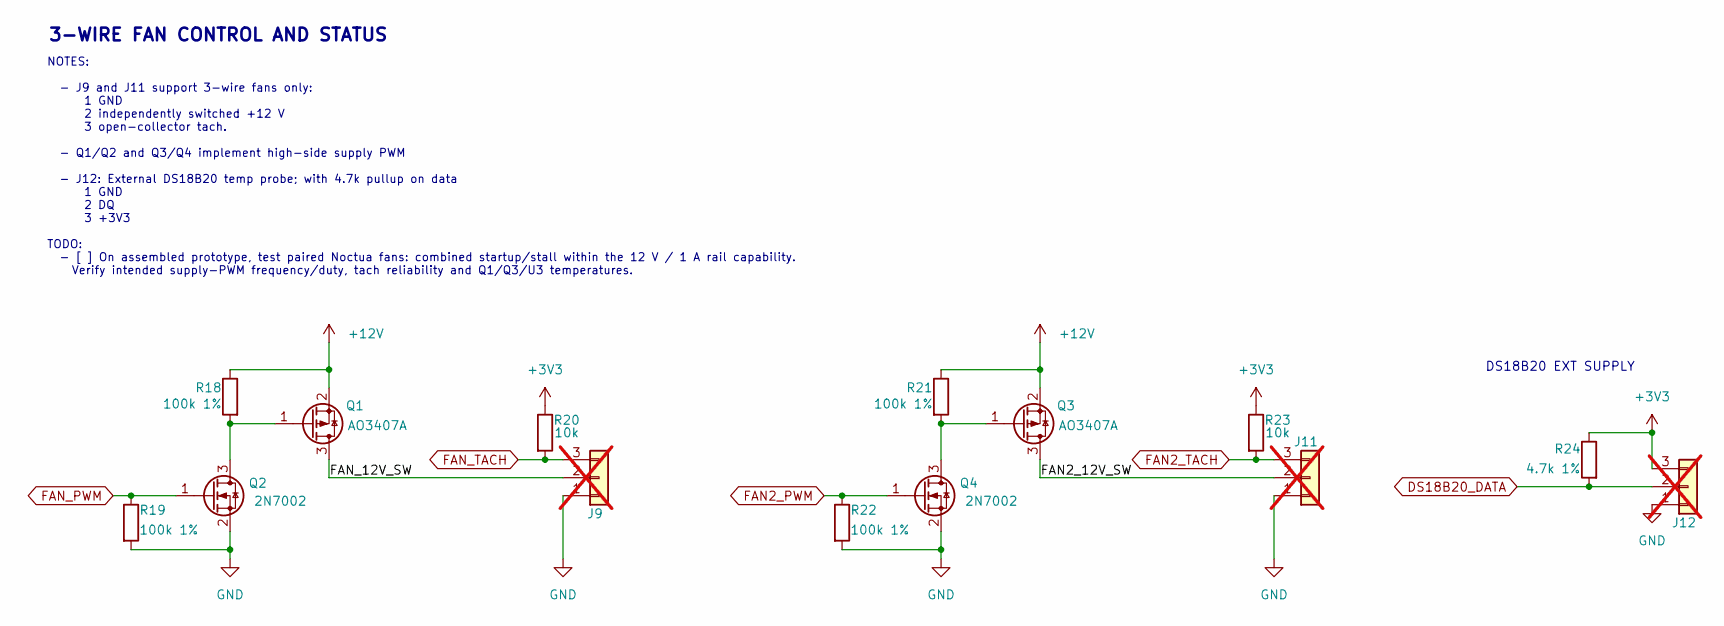
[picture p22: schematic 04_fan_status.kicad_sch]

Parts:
J9, J11: 12V 3-WIRE FAN; FanPinHeader_1x03_P2.54mm_Vertical_JLC_Edge; MPN TBD / user fan header; not fitted
J12: DS18B20 EXT SUPPLY; PinHeader_1x03_P2.54mm_Vertical; MPN TBD / user pin header; not fitted
Q1, Q3: AO3407A; SOT-23; MPN AO3407A; LCSC C15155
Q2, Q4: 2N7002; SOT-23; MPN 2N7002; LCSC C8545
R18, R19, R21, R22: 100k 1%; R_0603_1608Metric; Tolerance 1%; MPN 0603WAF1003T5E; LCSC C25803
R20, R23: 10k; R_0603_1608Metric; Tolerance 1%; MPN 0603WAF1002T5E; LCSC C25804
R24: 4.7k 1%; R_0603_1608Metric; Tolerance 1%; MPN 0603WAF4701T5E; LCSC C23162

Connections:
+3V3: J12.3, R20.1, R23.1, R24.1; also elsewhere on the board
+12V: Q1.2 (S), Q3.2 (S), R18.1, R21.1; also elsewhere on the board
/Fan Control and Status/FAN2_12V_SW: J11.2, Q3.3 (D)
/Fan Control and Status/FAN_12V_SW: J9.2, Q1.3 (D)
DS18B20_DATA: J12.2, R24.2; also elsewhere on the board
FAN2_PWM: Q4.1 (G), R22.1; also elsewhere on the board
FAN2_TACH: J11.3, R23.2; also elsewhere on the board
FAN_PWM: Q2.1 (G), R19.1; also elsewhere on the board
FAN_TACH: J9.3, R20.2; also elsewhere on the board
GND: J9.1, J11.1, J12.1, Q2.2 (S), Q4.2 (S), R19.2, R22.2; also elsewhere on the board
unnamed: Q1.1 (G), Q2.3 (D), R18.2
unnamed: Q3.1 (G), Q4.3 (D), R21.2

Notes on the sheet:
NOTES: - J9 and J11 support 3-wire fans only: 1 GND 2 independently switched +12 V 3 open-collector tach. - Q1/Q2 and Q3/Q4 implement high-side supply PWM - J12: External DS18B20 temp probe; with 4.7k pullup on data 1 GND 2 DQ 3 +3V3 TODO: - [ ] On assembled prototype, test paired Noctua fans: comb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
3-WIRE FAN CONTROL AND STATUS
DS18B20 EXT SUPPLY

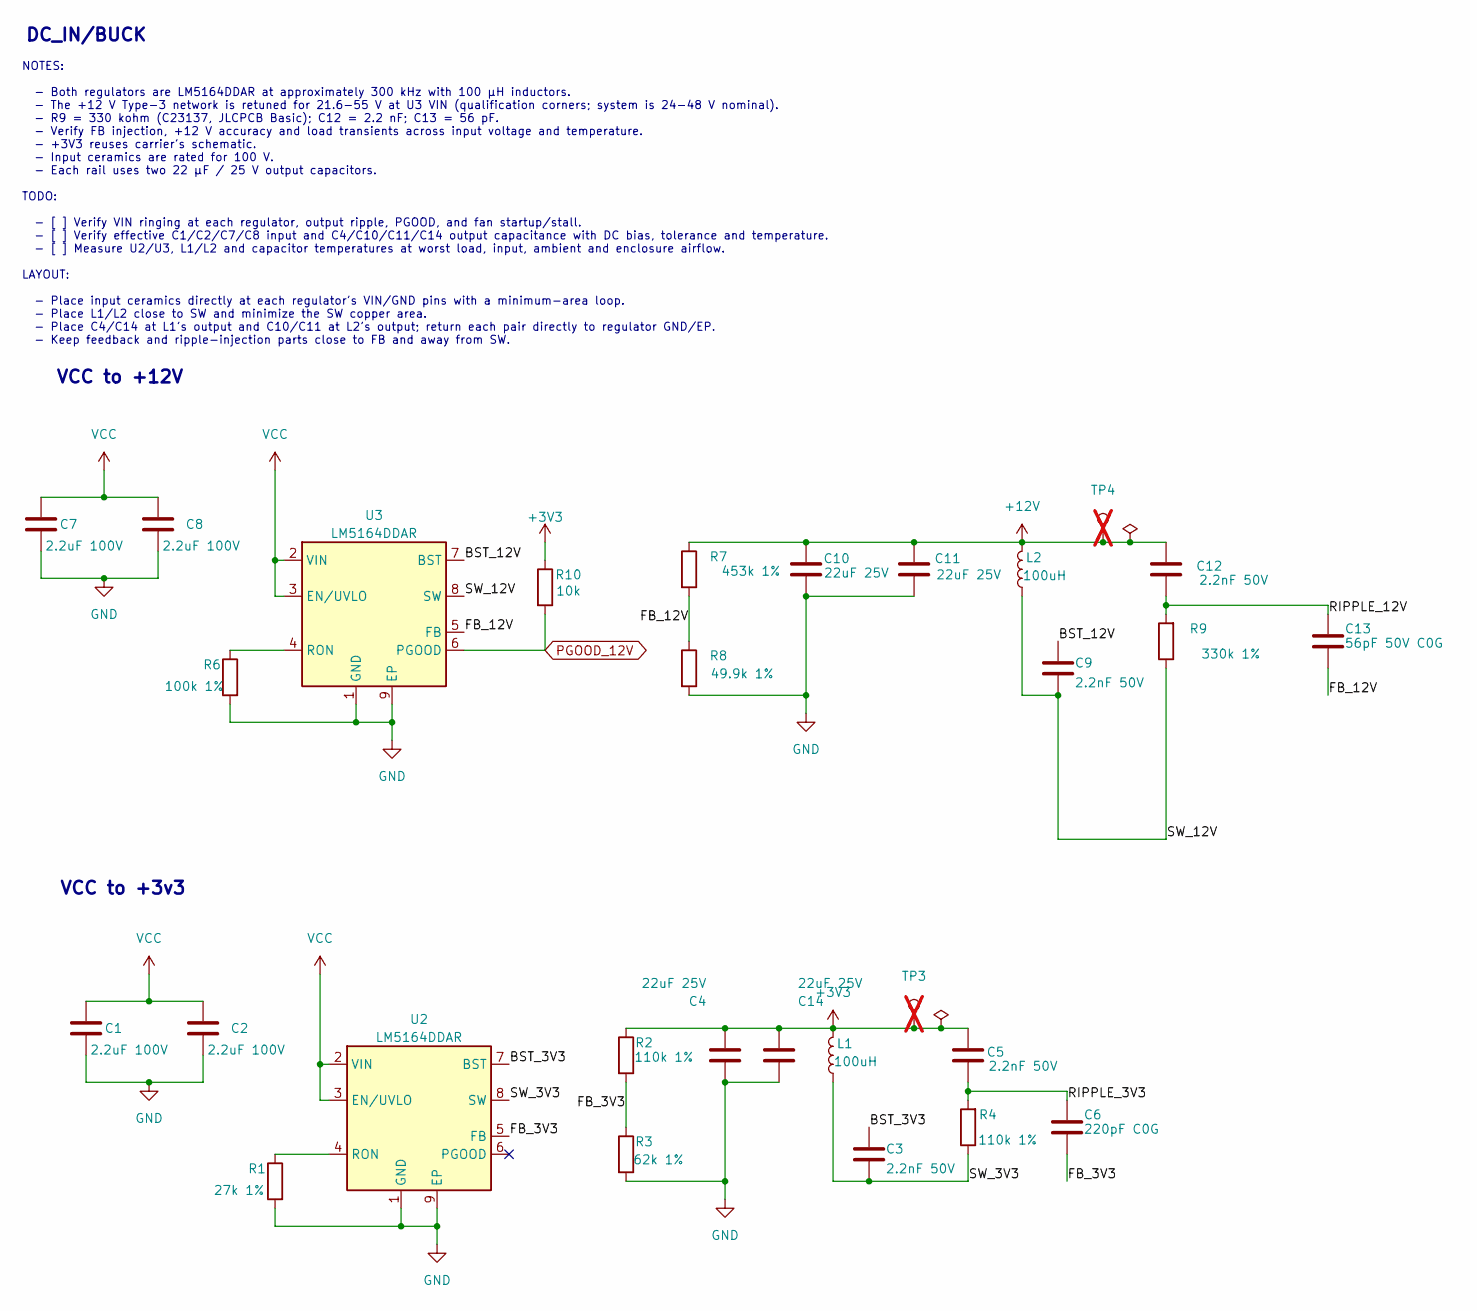
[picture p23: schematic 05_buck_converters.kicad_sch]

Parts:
C1, C2, C7, C8: 2.2uF 100V; C_1210_3225Metric; Voltage 100 V; MPN CL32B225KCJSNNE; LCSC C55151
C3, C5, C9, C12: 2.2nF 50V; C_0603_1608Metric; Voltage 50 V; MPN 0603B222K500NT; LCSC C1604
C4, C10, C11, C14: 22uF 25V; C_0805_2012Metric; Voltage 25 V; MPN CL21A226MAQNNNE; LCSC C45783
C6: 220pF C0G; C_0603_1608Metric; Voltage 50 V; MPN CC0603JRNPO9BN221; LCSC C106210
C13: 56pF 50V C0G; C_0603_1608Metric; Voltage 50 V; MPN 0603CG560J500NT; LCSC C1676
L1, L2: 100uH; L_PRODTech_PSPMAA0805; MPN PSPMAA0805-101M-ANP; LCSC C2962892
R1: 27k 1%; R_0603_1608Metric; Tolerance 1%; MPN 0603WAF2702T5E; LCSC C22967
R2, R4: 110k 1%; R_0603_1608Metric; Tolerance 1%; MPN 0603WAF1103T5E; LCSC C25805
R3: 62k 1%; R_0603_1608Metric; Tolerance 1%; MPN 0603WAF6202T5E; LCSC C23221
R6: 100k 1%; R_0603_1608Metric; Tolerance 1%; MPN 0603WAF1003T5E; LCSC C25803
R7: 453k 1%; R_0603_1608Metric; Tolerance 1%; MPN 0603WAF4533T5E; LCSC C25818
R8: 49.9k 1%; R_0603_1608Metric; Tolerance 1%; MPN 0603WAF4992T5E; LCSC C23184
R9: 330k 1%; R_0603_1608Metric; Tolerance 1%; MPN 0603WAF3303T5E; LCSC C23137
R10: 10k; R_0603_1608Metric; Tolerance 1%; MPN 0603WAF1002T5E; LCSC C25804
TP3: +3V3; TestPoint_Pad_D1.5mm; not fitted
TP4: +12V; TestPoint_Pad_D1.5mm; not fitted
U2, U3: LM5164DDAR; TI_SO-PowerPAD-8; MPN LM5164DDAR; LCSC C477928

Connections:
+3V3: C4.1, C5.2, C14.1, L1.2, R2.1, R10.1, TP3.1 (1_1); also elsewhere on the board
+12V: C10.1, C11.1, C12.2, L2.2, R7.1, TP4.1 (1_1); also elsewhere on the board
/Buck Converters/BST_3V3: C3.1, U2.7 (BST)
/Buck Converters/BST_12V: C9.1, U3.7 (BST)
/Buck Converters/FB_3V3: C6.2, R2.2, R3.1, U2.5 (FB)
/Buck Converters/FB_12V: C13.2, R7.2, R8.1, U3.5 (FB)
/Buck Converters/RIPPLE_3V3: C5.1, C6.1, R4.2
/Buck Converters/RIPPLE_12V: C12.1, C13.1, R9.2
/Buck Converters/SW_3V3: C3.2, L1.1, R4.1, U2.8 (SW)
/Buck Converters/SW_12V: C9.2, L2.1, R9.1, U3.8 (SW)
GND: C1.2, C2.2, C4.2, C7.2, C8.2, C10.2, C11.2, C14.2, R1.2, R3.2, R6.2, R8.2, U2.1 (GND), U2.9 (EP), U3.1 (GND), U3.9 (EP); also elsewhere on the board
unnamed: R1.1, U2.4 (RON)
unnamed: R6.1, U3.4 (RON)
PGOOD_12V: R10.2, U3.6 (PGOOD); also elsewhere on the board
VCC: C1.1, C2.1, C7.1, C8.1, U2.2 (VIN), U2.3 (EN/UVLO), U3.2 (VIN), U3.3 (EN/UVLO); also elsewhere on the board

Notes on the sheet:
DC_IN/BUCK
NOTES: - Both regulators are LM5164DDAR at approximately 300 kHz with 100 µH inductors. - The +12 V Type-3 network is retuned for 21.6-55 V at U3 VIN (qualification corners; system is 24-48 V nominal). - R9 = 330 kohm (C23137, JLCPCB Basic); C12 = 2.2 nF; C13 = 56 pF. - Verify FB injection, +12 V a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
VCC to +3v3
VCC to +12V

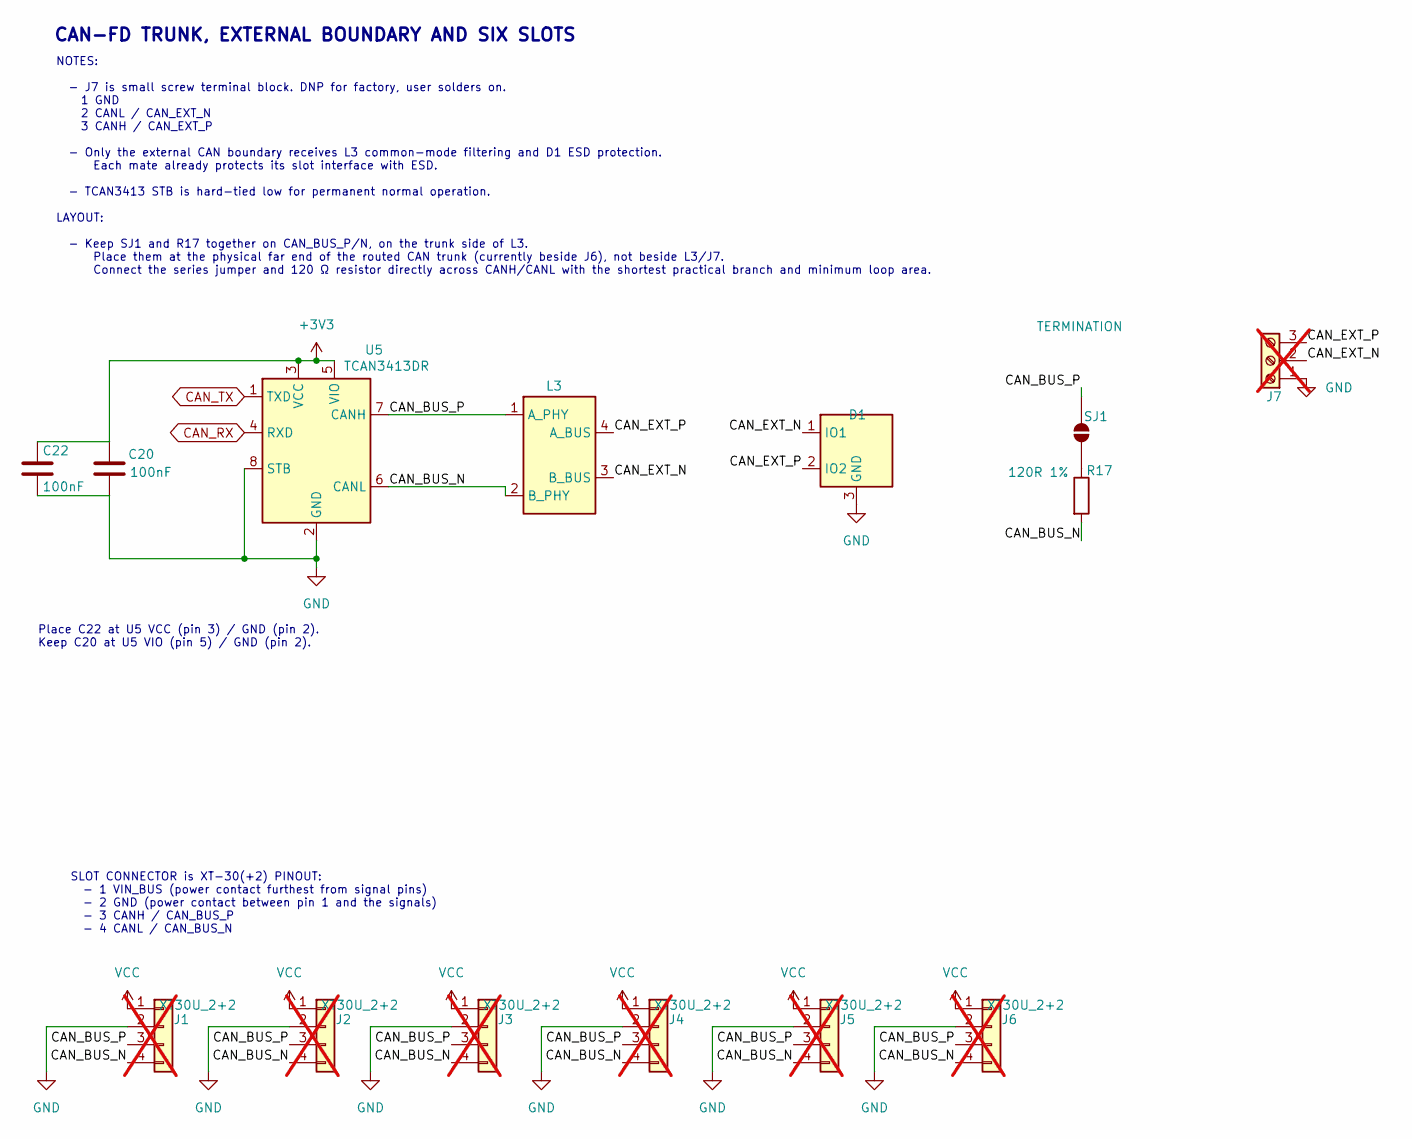
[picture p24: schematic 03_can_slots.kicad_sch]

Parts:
C20, C22: 100nF; C_0603_1608Metric; Voltage 50 V; MPN CC0603KRX7R9BB104; LCSC C14663
D1: PESD2CANFD27V-TR; SOT-23; MPN PESD2CANFD27V-TR; LCSC C552488
J1, J2, J3, J4, J5, J6: XT30U_2+2; Amass_XT30U_2plus2_F; MPN XT30U(2+2)-F.G.B; LCSC C30170181; not fitted
J7: XY308-2.54-3P / EXTERNAL CAN; TerminalBlock_Xinya_XY308-2.54-3P_1x03_P2.54mm_Horizontal; MPN XY308-2.54-3P; LCSC C557686; not fitted
L3: ACT1210D-101-2P-TL00; L_CommonModeChoke_TDK_ACT1210D; MPN ACT1210D-101-2P-TL00; LCSC C3039743
R17: 120R 1%; R_0603_1608Metric; Tolerance 1%; MPN 0603WAF1200T5E; LCSC C22787
SJ1: TERMINATION; SolderJumper-2_P1.3mm_Open_Pad1.0x1.5mm; MPN PCB solder jumper
U5: TCAN3413DR; SOIC-8_3.9x4.9mm_P1.27mm; MPN TCAN3413DR; LCSC C22433320

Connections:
+3V3: C20.1, C22.1, U5.3 (VCC), U5.5 (VIO); also elsewhere on the board
/CAN-FD and Six Slots/CAN_BUS_N: J1.4, J2.4, J3.4, J4.4, J5.4, J6.4, L3.2 (B_PHY), R17.2, U5.6 (CANL)
/CAN-FD and Six Slots/CAN_BUS_P: J1.3, J2.3, J3.3, J4.3, J5.3, J6.3, L3.1 (A_PHY), SJ1.1 (A), U5.7 (CANH)
/CAN-FD and Six Slots/CAN_EXT_N: D1.1 (IO1), J7.2, L3.3 (B_BUS)
/CAN-FD and Six Slots/CAN_EXT_P: D1.2 (IO2), J7.3, L3.4 (A_BUS)
CAN_RX: U5.4 (RXD); also elsewhere on the board
CAN_TX: U5.1 (TXD); also elsewhere on the board
GND: C20.2, C22.2, D1.3 (GND), J1.2, J2.2, J3.2, J4.2, J5.2, J6.2, J7.1, U5.2 (GND), U5.8 (STB); also elsewhere on the board
unnamed: R17.1, SJ1.2 (B)
VCC: J1.1, J2.1, J3.1, J4.1, J5.1, J6.1; also elsewhere on the board

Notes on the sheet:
SLOT CONNECTOR is XT-30(+2) PINOUT: - 1 VIN_BUS (power contact furthest from signal pins) - 2 GND (power contact between pin 1 and the signals) - 3 CANH / CAN_BUS_P - 4 CANL / CAN_BUS_N
NOTES: - J7 is small screw terminal block. DNP for factory, user solders on. 1 GND 2 CANL / CAN_EXT_N 3 CANH / CAN_EXT_P - Only the external CAN boundary receives L3 common-mode filtering and D1 ESD protection. Each mate already protects its slot interface with ESD. - TCAN3413 STB is hard-tied low 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
CAN-FD TRUNK, EXTERNAL BOUNDARY AND SIX SLOTS
Place C22 at U5 VCC (pin 3) / GND (pin 2). Keep C20 at U5 VIO (pin 5) / GND (pin 2).

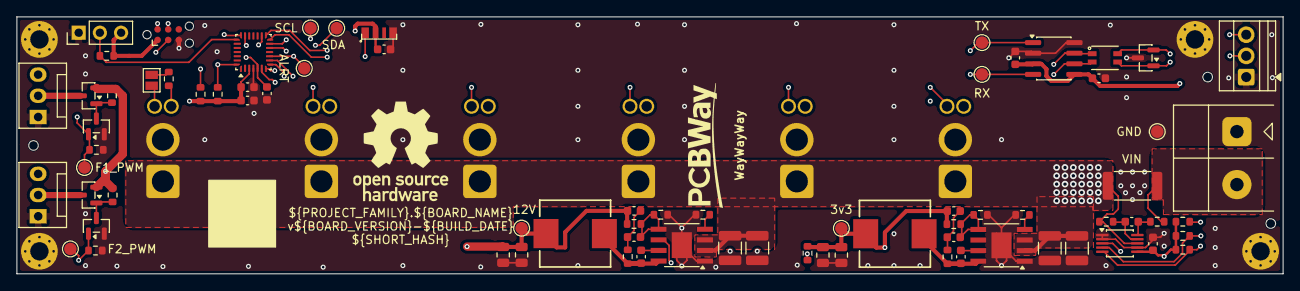
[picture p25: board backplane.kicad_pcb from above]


Board: 4 copper layers, 151.8 x 30.8 mm, 90 parts (10 on the bottom side), 41 nets.

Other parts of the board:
LOGO_PCBWAY: PCBWay_Logo_15mm

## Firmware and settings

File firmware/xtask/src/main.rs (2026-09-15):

use std::{
    env,
    fmt::Write as _,
    fs,
    path::{Path, PathBuf},
    process::{Command, ExitCode},
};

use pdcan_protocol::{
    CommissioningHeader, Header, MESSAGE_DEFINITIONS, MessageClass, MessageSender, NODE_TARGET,
    TargetKind,
};
use pdcan_types::{
    CarrierProfile, FirmwareVersion, HardwareRevision, ImageTarget, NodeRole, RequesterId,
    Sha256Digest, UpdateManifest,
};
use sha2::{Digest as _, Sha256};

const EMBEDDED_TARGET: &str = "thumbv6m-none-eabi";
const APPLICATION_PARTITION_BYTES: u64 = 110 * 1024;
const APPLICATION_BUDGET_BYTES: u64 = 100 * 1024;
const BOOTLOADER_PARTITION_BYTES: u64 = 16 * 1024;
const SRAM_BYTES: u64 = 30 * 1024;
const RAM_BUDGET_BYTES: u64 = SRAM_BYTES * 9 / 10;

#[derive(Clone, Copy, Debug, Eq, PartialEq)]
enum FirmwareTarget {
    Backplane,
    Carrier,
    Bootloader,
}

impl FirmwareTarget {
    const ALL: [Self; 3] = [Self::Backplane, Self::Carrier, Self::Bootloader];

    const fn name(self) -> &'static str {
        match self {
            Self::Backplane => "backplane",
            Self::Carrier => "carrier",
            Self::Bootloader => "bootloader",
        }
    }

    const fn package(self) -> &'static str {
        match self {
            Self::Backplane => "backplane-firmware",
            Self::Carrier => "carrier-firmware",
            Self::Bootloader => "pdcan-bootloader",
        }
    }

    const fn binary(self) -> &'static str {
        match self {
            Self::Backplane => "backplane",
            Self::Carrier => "carrier",
            Self::Bootloader => "pdcan-bootloader",
        }
    }

    const fn features(self) -> Option<&'static str> {
        match self {
            Self::Backplane | Self::Carrier => Some("firmware-bin"),
            Self::Bootloader => None,
        }
    }

    fn parse(value: &str) -> Result<Self, String> {
        match value {
            "backplane" => Ok(Self::Backplane),
            "carrier" => Ok(Self::Carrier),
            "bootloader" => Ok(Self::Bootloader),
            _ => Err(format!("unsupported firmware target {value:?}")),
        }
    }
}

fn main() -> ExitCode {
    match run(env::args().skip(1)) {
        Ok(()) => ExitCode::SUCCESS,
        Err(error) => {
            eprintln!("xtask: {error}");
            ExitCode::from(1)
        }
    }
}

fn run(arguments: impl Iterator<Item = String>) -> Result<(), String> {
    let arguments: Vec<_> = arguments.collect();
    match arguments.as_slice() {
        [] => {
            print_help();
            Ok(())
        }
        [arg] if arg == "--help" || arg == "-h" => {
            print_help();
            Ok(())
        }
        [command] if command == "dbc" => write_or_check_dbc(false),
        [command, option] if command == "dbc" && option == "--check" => write_or_check_dbc(true),
        [command] if command == "ci" => run_ci(),
        [firmware, build, all] if firmware == "firmware" && build == "build" && all == "all" => {
            build_all_firmware(false)
        }
        [firmware, build, all, release]
            if firmware == "firmware"
                && build == "build"
                && all == "all"
                && release == "--release" =>
        {
            build_all_firmware(true)
        }
        [firmware, build, target] if firmware == "firmware" && build == "build" => {
            build_firmware(FirmwareTarget::parse(target)?, false)
        }
        [firmware, build, target, release]
            if firmware == "firmware" && build == "build" && release == "--release" =>
        {
            build_firmware(FirmwareTarget::parse(target)?, true)
        }
        [firmware, bundle, target, version, image, output]
            if firmware == "firmware" && bundle == "bundle" =>
        {
            build_bundle(
                FirmwareTarget::parse(target)?,
                parse_version(version)?,
                Path::new(image),
                Path::new(output),
            )
        }
        _ => Err("unsupported arguments; run `cargo xtask --help`".into()),
    }
}

fn print_help() {
    println!(
        "\
Firmware workspace automation (run from firmware/)

Usage:
  cargo xtask ci
  cargo xtask dbc [--check]
  cargo xtask firmware build <backplane|carrier|bootloader|all> [--release]
  cargo xtask firmware bundle <backplane|carrier> <MAJOR.MINOR.PATCH> <IMAGE> <OUTPUT>
"
    );
}

fn parse_version(value: &str) -> Result<FirmwareVersion, String> {
    let mut components = value.split('.');
    let parse_component = |component: Option<&str>| {
        component
            .ok_or_else(|| "version must be MAJOR.MINOR.PATCH".to_owned())?
            .parse::<u16>()
            .map_err(|_| "version components must be unsigned 16-bit integers".to_owned())
    };
    let version = FirmwareVersion {
        major: parse_component(components.next())?,
        minor: parse_component(components.next())?,
        patch: parse_component(components.next())?,
    };
    if components.next().is_some() {
        return Err("version must be MAJOR.MINOR.PATCH".into());
    }
    Ok(version)
}

fn build_bundle(
    target: FirmwareTarget,
    version: FirmwareVersion,
    image_path: &Path,
    output_path: &Path,
) -> Result<(), String> {
    let (role, carrier_profile) = match target {
        FirmwareTarget::Backplane => (NodeRole::Backplane, None),
        FirmwareTarget::Carrier => (NodeRole::Carrier, Some(CarrierProfile::Sw3538)),
        FirmwareTarget::Bootloader => {
            return Err(
                "bootloaders are SWD-only and cannot be placed in CAN update bundles".into(),
            );
        }
    };
    let image = fs::read(image_path)
        .map_err(|error| format!("cannot read {}: {error}", image_path.display()))?;
    if image.len() > usize::try_from(APPLICATION_PARTITION_BYTES).expect("limit fits usize") {
        return Err(format!(
            "application image exceeds the {APPLICATION_PARTITION_BYTES} byte ACTIVE partition"
        ));
    }
    let digest: [u8; 32] = Sha256::digest(&image).into();
    let manifest = UpdateManifest {
        target: ImageTarget {
            role,
            carrier_profile,
            hardware_revision: HardwareRevision::REV_A,
            partition_layout: 1,
        },
        version,
        image_size: u32::try_from(image.len()).map_err(|_| "application image is too large")?,
        digest: Sha256Digest::from_bytes(digest),
    };
    let bundle = pdcan_artifact::build_unsigned(manifest, &image)
        .map_err(|error| format!("cannot build bundle: {error:?}"))?;
    fs::write(output_path, bundle)
        .map_err(|error| format!("cannot write {}: {error}", output_path.display()))?;
    println!("generated {}", output_path.display());
    Ok(())
}

fn workspace_root() -> PathBuf {
    Path::new(env!("CARGO_MANIFEST_DIR"))
        .parent()
        .expect("xtask is directly below the workspace root")
        .to_owned()
}

fn run_ci() -> Result<(), String> {
    run_command("cargo", &["fmt", "--all", "--check"])?;
    run_command(
        "cargo",
        &["test", "--workspace", "--exclude", "pdcan-bootloader"],
    )?;
    run_command(
        "cargo",
        &[
            "clippy",
            "--workspace",
            "--exclude",
            "pdcan-bootloader",
            "--all-targets",
            "--",
            "-D",
            "warnings",
        ],
    )?;
    for target in FirmwareTarget::ALL {
        clippy_firmware(target)?;
    }
    write_or_check_dbc(true)?;
    for target in FirmwareTarget::ALL {
        build_firmware(target, true)?;
    }
    Ok(())
}

fn clippy_firmware(target: FirmwareTarget) -> Result<(), String> {
    let mut arguments = vec![
        "clippy",
        "--package",
        target.package(),
        "--bin",
        target.binary(),
        "--target",
        EMBEDDED_TARGET,
    ];
    if let Some(features) = target.features() {
        arguments.extend(["--features", features]);
    }
    arguments.extend(["--", "-D", "warnings"]);
    run_command("cargo", &arguments)
}

fn build_firmware(target: FirmwareTarget, release: bool) -> Result<(), String> {
    let mut arguments = vec![
        "build",
        "--package",
        target.package(),
        "--bin",
        target.binary(),
        "--target",
        EMBEDDED_TARGET,
    ];
    if let Some(features) = target.features() {
        arguments.extend(["--features", features]);
    }
    if release {
        arguments.push("--release");
    }
    run_command("cargo", &arguments)?;
    if release {
        report_firmware_size(target)?;
    }
    Ok(())
}

fn build_all_firmware(release: bool) -> Result<(), String> {
    for target in FirmwareTarget::ALL {
        build_firmware(target, release)?;
    }
    Ok(())
}

fn report_firmware_size(target: FirmwareTarget) -> Result<(), String> {
    let sysroot = command_stdout("rustc", &["--print", "sysroot"])?;
    let version = command_stdout("rustc", &["-vV"])?;
    let host = version
        .lines()
        .find_map(|line| line.strip_prefix("host: "))
        .ok_or("rustc version data did not include a host triple")?;
    let llvm_size = Path::new(sysroot.trim())
        .join("lib/rustlib")
        .join(host)
        .join("bin/llvm-size");
    if !llvm_size.is_file() {
        return Err(format!(
            "llvm-tools-preview is required; {} is missing",
            llvm_size.display()
        ));
    }
    let artifact = workspace_root()
        .join("target")
        .join(EMBEDDED_TARGET)
        .join("release")
        .join(target.binary());
    let output = Command::new(&llvm_size)
        .arg(&artifact)
        .output()
        .map_err(|error| format!("cannot run llvm-size: {error}"))?;
    if !output.status.success() {
        return Err(format!("llvm-size failed for {}", artifact.display()));
    }
    let report = String::from_utf8(output.stdout)
        .map_err(|error| format!("llvm-size returned non-UTF-8 output: {error}"))?;
    let (text, data, bss) = parse_llvm_size(&report)?;
    let flash = text.saturating_add(data);
    let ram = data.saturating_add(bss);
    let (hard_flash_limit, budget) = if target == FirmwareTarget::Bootloader {
        (BOOTLOADER_PARTITION_BYTES, BOOTLOADER_PARTITION_BYTES)
    } else {
        (APPLICATION_PARTITION_BYTES, APPLICATION_BUDGET_BYTES)
    };
    println!(
        "firmware {} size: flash={flash}/{hard_flash_limit} bytes (budget {budget}), ram={ram}/{SRAM_BYTES} bytes (budget {RAM_BUDGET_BYTES})",
        target.name()
    );
    if flash > hard_flash_limit {
        return Err(format!(
            "{} flash partition exceeded: {flash} > {hard_flash_limit}",
            target.name()
        ));
    }
    if flash > budget {
        return Err(format!(
            "{} flash growth budget exceeded: {flash} > {budget}",
            target.name()
        ));
    }
    if ram > RAM_BUDGET_BYTES {
        return Err(format!(
            "{} RAM budget exceeded: {ram} > {RAM_BUDGET_BYTES}",
            target.name()
        ));
    }
    Ok(())
}

fn command_stdout(program: &str, arguments: &[&str]) -> Result<String, String> {
    let output = Command::new(program)
        .args(arguments)
        .output()
        .map_err(|error| format!("cannot run {program}: {error}"))?;
    if !output.status.success() {
        return Err(format!("{program} exited with {}", output.status));
    }
    String::from_utf8(output.stdout)
        .map_err(|error| format!("{program} output was not UTF-8: {error}"))
}

fn parse_llvm_size(report: &str) -> Result<(u64, u64, u64), String> {
    let values: Vec<_> = report
        .lines()
        .nth(1)
        .ok_or_else(|| format!("unexpected llvm-size output: {report:?}"))?
        .split_whitespace()
        .collect();
    if values.len() < 3 {
        return Err(format!("unexpected llvm-size row: {values:?}"));
    }
    let parse = |index: usize, name: &str| {
        values[index]
            .parse::<u64>()
            .map_err(|error| format!("invalid {name} size {:?}: {error}", values[index]))
    };
    Ok((parse(0, "text")?, parse(1, "data")?, parse(2, "bss")?))
}

fn write_or_check_dbc(check: bool) -> Result<(), String> {
    let path = workspace_root().join("docs/pdcan/can/pdcan.dbc");
    let generated = render_dbc()?;
    if check {
        let existing = fs::read_to_string(&path)
            .map_err(|error| format!("cannot read generated {}: {error}", path.display()))?;
        if existing != generated {
            return Err(format!(
                "{} is stale; run `cargo xtask dbc`",
                path.display()
            ));
        }
    } else {
        let parent = path.parent().expect("DBC path has a parent");
        fs::create_dir_all(parent)
            .map_err(|error| format!("cannot create {}: {error}", parent.display()))?;
        fs::write(&path, generated)
            .map_err(|error| format!("cannot write {}: {error}", path.display()))?;
        println!("generated {}", path.display());
    }
    Ok(())
}

fn render_dbc() -> Result<String, String> {
    let mut output = String::from(
        "VERSION \"PDCAN Gen-2; generated by cargo xtask dbc\"\n\nNS_ :\n\nBS_:\n\nBU_: Node Host\n\n",
    );
    output.push_str(
        "CM_ \"Generated from pdcan_protocol::MESSAGE_DEFINITIONS. Operational IDs use node 1, target 15 (or fan 0), and requester 15; commissioning IDs use representative token 1.\";\n\n",
    );
    for definition in MESSAGE_DEFINITIONS {
        let target = match definition.target {
            TargetKind::Fan => 0,
            TargetKind::Node | TargetKind::Commissioning => NODE_TARGET,
        };
        let requester = if definition.requester_scoped {
            RequesterId::PDCAN_DEFAULT
        } else {
            RequesterId::PROTOCOL
        };
        let id = if definition.class == MessageClass::Commissioning {
            CommissioningHeader::new(definition.priority, 1, requester, definition.opcode)
                .map_err(|error| format!("invalid definition {}: {error:?}", definition.name))?
                .encode()
        } else {
            Header::new(
                definition.priority,
                definition.class,
                1,
                target,
                requester,
                definition.opcode,
            )
            .map_err(|error| format!("invalid definition {}: {error:?}", definition.name))?
            .encode()
        };
        let transmitter = match definition.sender {
            MessageSender::Host => "Host",
            MessageSender::Node => "Node",
        };
        writeln!(
            &mut output,
            "BO_ {} PDCAN_{}: {} {transmitter}",
            id.get() | 0x8000_0000,
            definition.name,
            definition.payload_len
        )
        .map_err(|error| format!("cannot render DBC: {error}"))?;
        if definition.has_request_id {
            output.push_str(
                " SG_ RequestId : 0|64@1+ (1,0) [0|1.8446744073709552e+19] \"\" Vector__XXX\n",
            );
        }
        output.push('\n');
    }
    Ok(output)
}

fn run_command(program: &str, arguments: &[&str]) -> Result<(), String> {
    println!("+ {program} {}", arguments.join(" "));
    let status = Command::new(program)
        .args(arguments)
        .current_dir(workspace_root())
        .status()
        .map_err(|error| format!("cannot run {program}: {error}"))?;
    if status.success() {
        Ok(())
    } else {
        Err(format!("{program} exited with {status}"))
    }
}

#[cfg(test)]
mod tests {
    use super::*;

    #[test]
    fn parses_llvm_size_berkeley_output() {
        let report = "text data bss dec hex filename\n1024 12 44 1080 438 firmware\n";
        assert_eq!(parse_llvm_size(report), Ok((1024, 12, 44)));
    }

    #[test]
    fn generated_dbc_contains_every_gen2_definition_and_no_backpack_node() {
        let dbc = render_dbc().unwrap();
        for definition in MESSAGE_DEFINITIONS {
            assert!(dbc.contains(&format!("PDCAN_{}:", definition.name)));
        }
        assert!(dbc.contains("BU_: Node Host"));
        assert!(!dbc.contains("Backpack"));
    }

    #[test]
    fn all_three_finalized_firmware_targets_are_buildable_names() {
        assert_eq!(FirmwareTarget::ALL.len(), 3);
        assert_eq!(
            FirmwareTarget::parse("backplane"),
            Ok(FirmwareTarget::Backplane)
        );
        assert_eq!(
            FirmwareTarget::parse("carrier"),
            Ok(FirmwareTarget::Carrier)
        );
        assert_eq!(
            FirmwareTarget::parse("bootloader"),
            Ok(FirmwareTarget::Bootloader)
        );
    }
}

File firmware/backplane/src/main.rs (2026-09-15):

#![no_std]
#![no_main]

use core::{cell::RefCell, hint::black_box};

use embassy_boot_stm32::{AlignedBuffer, BlockingFirmwareUpdater, FirmwareUpdaterConfig};
use embassy_stm32::flash::Flash;
use embassy_stm32::gpio::{Level, Output, Speed};
use embassy_sync::blocking_mutex::{Mutex, raw::NoopRawMutex};
use embassy_time::Timer;
use panic_halt as _;

#[embassy_executor::main]
async fn main(spawner: embassy_executor::Spawner) -> ! {
    let _ = spawner;
    let peripherals = embassy_stm32::init(embassy_stm32::Config::default());

    // The finalized board uses active-high supply PWM. Start both 3-wire fan
    // channels at the safe full-on state before initializing the wider system.
    let _fan_1 = Output::new(peripherals.PA2, Level::High, Speed::Low);
    let _fan_2 = Output::new(peripherals.PA0, Level::High, Speed::Low);
    let _status_led = Output::new(peripherals.PA1, Level::Low, Speed::VeryHigh);

    let regions = Flash::new_blocking(peripherals.FLASH).into_blocking_regions();
    let flash = Mutex::<NoopRawMutex, _>::new(RefCell::new(regions.bank1_region));
    let updater_config = FirmwareUpdaterConfig::from_linkerfile_blocking(&flash, &flash);
    let mut state_buffer = AlignedBuffer([0; 8]);
    let mut firmware_updater = BlockingFirmwareUpdater::new(updater_config, state_buffer.as_mut());
    let boot_state = firmware_updater
        .get_state()
        .expect("Embassy Boot state partition must be readable");
    black_box(boot_state);

    // Do not mark a trial image booted yet. Confirmation belongs after the CAN,
    // watchdog, configuration, and critical peripheral health gates are live.
    loop {
        Timer::after_secs(1).await;
    }
}

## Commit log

2026-09-15 Initial public snapshot
    [01_power_control.kicad_sch, 01_power_input.kicad_sch, 02_control.kicad_sch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]
2026-09-16 Organize worklogs into dated page bundles with prototype images
2026-09-18 Clarify project goals and initial system power targets
2026-09-18 Document the ESP32 gateway concept with a placeholder render
2026-09-19 Add backplane copper-capacity figure to the system overview
2026-09-19 Update system interfaces, power estimates, and image captions
2026-09-19 Expand the first prototype worklog and journal introduction
2026-10-09 Add Indy silkscreen artwork and size comparison proofs
